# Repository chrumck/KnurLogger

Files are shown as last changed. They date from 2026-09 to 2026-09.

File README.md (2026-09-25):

# KnurLogger

Headless Raspberry Pi logger for the ND Miata instrumentation. It publishes sensor channels to
RaceChrono over BLE and retains raw readings and diagnostics in append-only local session files.

## Start here

| Task | Read |
|---|---|
| Work on the code | [Working instructions](CLAUDE.md), then [software contract](software-contract.md) |
| Build, deploy, enroll probes or retrieve logs | [Operations](operations.md) |
| Configure the phone or decode a packet | [Channel reference](racechrono-channels.md) |
| Diagnose BLE or inspect a recording | [BLE protocol](ble-protocol.md) |
| Diagnose I2C or change sensor acquisition | [Hardware interfaces](hardware-interface.md) |
| Change thermal sampling | [1-Wire probes](one-wire-probes.md) |
| Interpret counters and clocks | [Session records](session-records.md) |
| Change the pressure correction or enter line lengths | [Correction plan](pressure-correction.md), then [operations](operations.md#pressure-correction-settings) |
| Wire the board | [Perfboard build sheet](SystemSetup/logger-perfboard-wiring.md) |
| Configure the host or inspect setup progress | [Host runbook](SystemSetup/pi-headless-setup.md) |
| Restore the phone profile | [RaceChrono profile](RaceChrono/README.md) |
| Understand a retired feature or resolved fault | [History](CLAUDE.history.md) |

Measurement requirements, qualification and the project backlog belong to
[ndLouvers](../ndLouvers/CFD-Learning-Plan.md). Measured results belong to its
[thermal](../ndLouvers/thermals-testing.md) and [pressure](../ndLouvers/pressure-testing.md)
companions. Logger operation is not pressure-channel qualification.

## Hardware it drives

| Part | Interface | Channels |
|---|---|---|
| 5 × Sensirion SDP810 (4 × ±500 Pa on `P0`/`P1`/`P3`/`P4`, 1 × ±125 Pa on **`P2`**) | I2C `0x25` behind a PCA9548A mux at `0x70` | `P0`–`P5` |
| 4 × DS18B20 | 1-Wire on GPIO4, addressed by 64-bit ROM ID | `temp0`–`temp3` |
| BME280 | I2C `0x77` on the main bus | enclosure pressure, cavity temperature, humidity |

**Channel names are positional and carry no meaning.** `P0`–`P5` are fixed by mux position;
`temp0`–`temp3` are fixed by ROM ID at enrollment. The mapping from these to measurement roles
(`T_ambient`, `T_core_in`, `U`, `X`, `C` …) must be recorded with the session metadata. Do not
rename a channel after a role. The thermal role map and its confirmation are in
[ndLouvers thermals §1.1](../ndLouvers/thermals-testing.md#11-channels-roles-and-bindings); the
ROM IDs are in the build sheet's §5a. Pressure role allocation belongs to
[ndLouvers instrumentation](../ndLouvers/instrumentation-spec.md).

All five SDP810s answer at the same fixed I2C address and cannot be strapped apart, which is why
the mux is mandatory rather than a convenience.

## Layout

Single translation unit: every `.cxx` is `#include`-d into `main.cxx`, in the order below, and only
`main.cxx` is named in `CMakeLists.txt`.

```
main.cxx              argument parsing, worker startup, thread joins
dataContracts.hpp     includes, constants, the config and state structs
appData.cxx           the two globals
helpers.cxx           TAI and boot clocks, sysfs and subprocess readers
config.cxx            the .ini, resolved from /proc/self/exe
sessionWriter.cxx     append-only NDJSON, record queue, ~1 s fsync cadence
blePackets.cxx        RaceChrono packet wire format — before every producer
supplyMonitor.cxx     vcgencmd + rpi_volt hwmon at 1 Hz, sticky-bit transitions
oneWireProbes.cxx     DS18B20 enrollment, the bindings in the .ini, 0x602 and 0x603
i2cBus.cxx            I2C_RDWR transport with the mandatory retry — the mux shares it
bme280Sensor.cxx      BME280 forced-mode reads, compensation, 0x600 and 0x601
pressureSensors.cxx   PCA9548A channel select, five SDP810s, 0x605, 0x606 and 0x607
raceChronoBle.cxx     bluez_inc: adapter, advertisement, GATT, notify timers
bluez_inc/            submodule, github.com/weliem/bluez_inc

build/KnurLogger.ini  config TEMPLATE; the deployed copy is ~/bin/KnurLogger.ini on the box

*.md                  subsystem, operations and plan documents — routed by "Start here" above

Tools/                offline diagnostics; nothing here runs on the box
  rcz-channels.py       decode a RaceChrono .rcz's channel slots and flag a mistyped
                        equation — the phone's channel list, audited without the phone
  bell-marks.py         evaluate calibration-bell marks against one pressure channel of a
                        session, on the as-built bell constants and the barometric factor
  ladder-fit.py         re-derive every ladder mark in force and fit each sensor's span
                        term: constant, sign split, slope, per-rung offsets, validation
  pressure-correction-check.py  recompute a session's pressure correction from its own
                        baseline and raw readings, and check the stale-hold events

3DPrinting/           every printed part for both boxes — enclosure, sensor holders, boom
                      tip, the calibration bell (calibrationBell.md owns its constants) and
                      the hood tap's surface static button (surfaceStaticButton.md)

bellTesting.xlsx      the bell-session spreadsheet

RaceChrono/           the phone's configuration, which lives nowhere else
  vehicleProfile.json   RaceChrono's exported vehicle profile, localUuid stripped;
                        both boxes' channels, since the two share one channel set
  README.md             why it is here, how to re-import it, and its traps

SystemSetup/          host configuration; nothing here is logger code
  pi-headless-setup.md    the runbook — start here
  logger-perfboard-wiring.md  the perfboard build sheet — §3a's net list is the authority
                          on every connection. Measurement requirements it serves are in
                          ndLouvers/instrumentation-spec.md.
  audit-boot.sh           read-only survey of what the box runs at boot
  install-dependencies.sh packages the build needs
  harden-headless.sh      boot-time service reduction and bus configuration
  ssh-harden.sh           key-only SSH
  deploy-logger.sh        installs the production binary into ~/bin, never its .ini
  grant-w1-bulk-read.sh   udev rule for therm_bulk_read — one of the two conditions for 1 Hz
  60-knurlogger-w1-bulk-read.rules  what that script installs
  KnurLogger.service      systemd unit — INSTALLED and enabled, survives a reboot
```

## Relationship to the other two loggers

| | KnurDash | iSitePiLogger | KnurLogger |
|---|---|---|---|
| Display | 4.3" DSI touchscreen, GTK under `startx` | none | none |
| Primary record | RaceChrono on the phone | files uploaded over HTTP | **RaceChrono over BLE**; SD card is the durable raw/diagnostic record |
| Radios | BLE | both disabled | **BLE required**, Wi-Fi up (blocked by hand only to diagnose BLE) |
| Language | C | C++, single translation unit | C++, single translation unit |

**KnurDash** contributes the RaceChrono BLE protocol implementation and its `bluez_inc` usage.
It is not the structural model: it is a GUI dash that boots into `startx`, and this box has no
display.

**iSitePiLogger** is the structural model — `SystemSetup/` layout, pre-flight-by-default scripts,
single-translation-unit CMake build, procedural GLib workers, an `.ini` beside the binary,
`CLOCK_TAI` throughout. Two things in it must **not** be copied, and both are load-bearing:

1. Its `setupNotes.txt` disables Bluetooth. BLE is this box's product.
2. Its `setupNotes.txt` disables Wi-Fi. This box lives in a wheel-well cavity with no Ethernet,
   so Wi-Fi is the only way back in; it stays up and is blocked by hand only to diagnose BLE.

## Next

Use [ndLouvers Work Progress](../ndLouvers/work-progress.md) for project work,
[pressure-correction.md](pressure-correction.md) for the logger correction's remaining steps, and
the [host runbook](SystemSetup/pi-headless-setup.md#work-progress) for host-specific open items.
The [acquisition plan](pressure-worker-plan.md) retains its pending recording audit and links
to the completed implementation record.

## Licence

MIT — see [LICENSE](LICENSE), which also states what it does not cover and the absence of any
warranty of fitness for vehicle use. **`bluez_inc` is a submodule, not a copy**, so its own MIT
licence travels with it rather than being restated here. The sibling
[ndLouvers](https://github.com/chrumck/ndLouvers) repository carries the same licence.

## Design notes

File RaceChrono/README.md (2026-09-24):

# RaceChrono vehicle profile — the channel list, backed up

**`vehicleProfile.json` is RaceChrono's exported vehicle profile, with `localUuid` removed.**
It is the only copy of the phone's channel definitions outside the phone, and it covers **both
boxes**: the two devices share one RaceChrono channel set, which is why a channel added for one of
them can break the other.

**Why this is here at all.** Channel definitions are hand-typed into the app. The byte-level
specification is in `../racechrono-channels.md`; this file is the actual configuration, equations and predefined
channel slots included. Re-picking slots by hand is what produced the `bytesToUint`-where-
`bytesToInt`-belongs fault on `Temperature Front 2` (`../../ndLouvers/` open item 45), so a backup that
can be re-imported is worth more than a table that has to be re-typed.

**This directory holds the PROFILE, not recordings.** Session `.rcz` exports live outside both
repositories, in `C:\_claude\RaceChrono\` — `../../ndLouvers/thermals-testing.md` §2.5 item 4 owns
that and says how they differ from the SD session files. Sessions are cited by `.rcz` filename in
`../CLAUDE.history.md`; do not look for them here.

**Exported 2026-09-19**, from the profile named `AE30`. It is a snapshot, not a live mirror —
**the app is the authority**, and this file is stale from the moment a channel is edited.
Re-export after any change.

**This export is the one that carries `0x605`–`0x607`.** The pressure channels and their status
fields were entered on 2026-09-19 and verified the same day — the sentinel check with the sensors
disconnected, every channel negative, and `0x606`'s free-running counter stepping +1 — so all eight
of box 2's packets are now subscribed. It also carries the `0x420` byte 7 channel that
`../../ndLouvers/` open item 47 had been waiting for.

> **⚠ A `git diff` OF THIS FILE IS NOT A REVIEW OF IT.** RaceChrono emits `customChannels` in an
> order that shifts as entries are added, so a re-export rewrites lines that did not change — this
> one showed 184 insertions and 86 deletions for 14 added channels. **Diff it by `(pid, channelId)`
> instead**, decoding each id as `slot × 2²⁰ + channelType`, or an equation edited by hand will pass
> review unseen. That is the fault class this whole directory exists to catch.

## Restoring it

RaceChrono imports a `.rcz`, which is a zip with the profile at the archive root:

```bash
cd RaceChrono && zip ../vehicle.rcz vehicleProfile.json
```

**`localUuid` was removed before committing** — it is a 64-hex-character identifier tied to the
owner's install, not a channel definition, and this repository is public. Re-import has **not been
tested without it**; if the app refuses the file, paste the value back from the original export or
from an export taken after this one.

## What is in it

49 custom channels across thirteen packet IDs. **Box 2's are `0x600`–`0x607`, 36 channels**
(`../racechrono-channels.md` §"The slot map" is the human-readable version). **Box 1's are `0x78`, `0x202`,
`0x420`, `0x4FA` and `0x7F0`, 13 channels.**

**The IDs claimed across both boxes are therefore `0x78`, `0x202`, `0x420`, `0x4FA`, `0x600`–`0x607`
and `0x7F0`.** Check a proposed new packet ID against that list here, in this file, rather than
against either box's source: the two devices share one channel set, so an ID free on one of them is
not necessarily free.

Two of those 49 are not in the slot map and are worth naming, because each is a decision rather
than an omission:

1. **`P5` has no channel** — `0x606` bytes 2–3. Mux channel 5 is unpopulated, so the field is a
   permanent sentinel inside a packet that is subscribed anyway. `../racechrono-channels.md` slot-map note 5
   owns it, including what to do if channel 5 is ever populated.
2. **`0x420` byte 7 is now defined**, as `H-40` on predefined channel 10031, alongside byte 0's
   existing `A-40` on 10026. That is the outside-air temperature of `../../ndLouvers/` open item 47.
   Defining it fixes nothing retrospectively — no past recording can be reprocessed — so it counts
   only from the first session recorded after this export.

**Two things worth knowing before editing an equation by hand.**

1. **RaceChrono's equation parser is case-insensitive**, and this file proves it: `bytesToUint`,
   `bytesTouInt`, `bytestouint` and `bytesToUInt` all appear and all work. **Do not "normalise" the
   casing** — there is nothing to fix, and an edit is a chance to introduce the fault below.
2. **`bytestoint` and `bytestouint` differ by one letter, and that letter is the signed/unsigned
   decision.** In lowercase, scanning for it by eye is unreliable. `../Tools/rcz-channels.py`
   checks it from a recording instead — on `Temperature` slots at +327.68 and, since 2026-09-19,
   on `Pressure` slots at +3.2768. **The pressure channels need that check more than the thermal
   ones did**: a negative differential is normal on half of them, depending only on which port the
   tube lands in, so a wrong sign there corrupts ordinary data rather than only the marker.
   `Pressure Front 50` is exempt and must stay `bytesToUint` — `0x600`'s enclosure pressure is
   unsigned by design.

**`A`–`H` (or `a`–`h`) in an equation are payload bytes 0–7.**

**An all-empty channel is not necessarily a broken one.** RaceChrono renders a deliberate
out-of-range marker as no value at all. Box 1's `0x7F0` channels `lowPass(E,254)*4` and
`lowPass(F,254)-50` are `NaN` whenever their sensors are outside their calibration range, and
**that is by design** (owner, 2026-09-11): the marker is how that is signalled. They are working —
on the 2026-09-13 track day both read normally once the car was warm and were empty only for the
first 200–550 s of each session, so "empty" is a property of the session, not of the channel. `../Tools/rcz-channels.py` reports such channels without
calling them faults — **ask what the sensor was doing before changing an equation.**

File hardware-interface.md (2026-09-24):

# Sensor interfaces and bus diagnostics

[SystemSetup/logger-perfboard-wiring.md](SystemSetup/logger-perfboard-wiring.md) owns the net
list, addresses, serial-to-channel allocation and assembly. Consult its §2 and §5 before
working on a physical channel. This file owns software-facing bus rules and diagnostic technique.

## Addressing and identity

1. The five SDP810s are hard-soldered; moving or isolating a sensor requires desoldering.
   Identify each by returned product number and serial, not its board position. Retain its
   returned scale factor; do not hard-code 60 counts/Pa for both products.
2. The sensors share fixed address `0x25`, so select one mux channel at a time. Use only the
   configured populated-channel list. Never probe channel 5: its pull-ups are not fitted.
3. The PCA9548A is strapped to `0x70`; the BME280 at `0x77` occupies the address a differently
   strapped mux could collide with. The BME280 chip ID is `0x60` at register `0xD0`.
4. Each populated downstream channel requires its own pull-ups. The build sheet owns values.
5. Read the mux control register back after writing it and verify the selected channel.
   A seemingly successful write to a faulty segment can otherwise hang the main bus.

## Idle-bus refusal

1. On some boots the first `I2C_RDWR` after an idle interval is refused with `EREMOTEIO`.
   The behavior is bimodal per boot. A clean boot does not close the physical-cause question
   in [ndLouvers open item 44](../ndLouvers/work-progress.md).
2. `i2cBus.cxx` owns the counted retry: up to ten attempts, separated by 500 µs.
   Do not add another retry layer in a sensor worker or hide recovered/exhausted transfers.
3. A clean `i2cdetect` is not proof that spaced transfers work. Check several spaced reads with
   `i2ctransfer -y 1 w1@0x77 0xd0 r1`; a single success or failure cannot establish the mode.
4. Check `present` before interpreting exhausted transfers. Errors while a device is absent
   are not evidence of a deteriorating connected bus. Counters are cumulative and shared;
   [session-records.md](session-records.md) explains the calculation.
5. The configured 10 Hz pressure loop still leaves the bus idle between cycles. Do not raise
   the sample rate to conceal the refusal; its physical cause and sampling choice are separate.

## A downstream segment hangs the main bus

1. First inspect the Pi side with `pinctrl get <n>` when a device is silent. Check wiring before
   trying to repair a physical reset fault in software.
2. A clean scan, both lines idle-high and failed transfers can indicate SDA shorted to SCL on
   the selected downstream segment. Check `SDA_CH<n>` to `SCL_CH<n>` continuity.
3. Recover using GPIO17: `pinctrl set 17 op dl`, pause, then `pinctrl set 17 op dh`.
   Reset between populated channels during diagnosis so one failed segment cannot mask the rest.

## SDP810 continuous mode and sampling

1. Use stop-continuous `0x3FF9`, identity `0x367C`/`0xE102`, then start `0x3615` once per
   sensor. Each measurement is a nine-byte frame with a CRC on each word.
2. Starting continuous mode again while already running is NAK'd. Mux switching does not stop
   that mode. Track `isContinuousStarted` per sensor; a failed read clears it so the next visit
   re-arms and pays `SDP810_START_SETTLE_US`. Do not re-arm unconditionally every cycle.
3. Keep `0x3615` differential-pressure temperature compensation. Do not switch to the mass-flow
   compensation variants as a substitute for the barometric correction specified in
   [pressure-testing.md §2.3a–§2.4](../ndLouvers/pressure-testing.md).
4. At this logger's read interval, `average till read` is exponential smoothing, not a full-cycle
   mean. Its roughly 10 ms time constant does not cover the configured 100 ms interval.
   Changing sampling or averaging requires the measurement decision in
   [open item 54](../ndLouvers/work-progress.md); the hardware retry is a separate question.
5. [pressure-correction.md](pressure-correction.md) owns the pressure correction's decisions and
   its progress. Read it before changing conversion or configuration.

## BME280 quantities

1. `enclosurePressurePa` is enclosure pressure. It is unsuitable as an aerodynamic static
   reference, but supplies the pressure correction's absolute-pressure input. Log it for every
   bench and road session. Physical interpretations belong to
   [thermals-testing.md §1.4](../ndLouvers/thermals-testing.md).
2. `cavityTemperatureC` is the cavity thermometer. It is not the inlet-air temperature for
   density; use the measurement plan's ambient channel for that purpose.
3. `enclosureHumidityPct` supports dewpoint-margin interpretation. The measurement acceptance
   of a sealed enclosure belongs to the instrumentation specification.
4. Forced mode, ×1 oversampling and IIR off minimize self-heating of the cavity thermometer.
   A skipped temperature invalidates pressure and humidity through shared `t_fine`; successful
   transport does not make the resulting measurement valid.

## Other interfaces

1. [one-wire-probes.md](one-wire-probes.md) owns DS18B20 binding, powered-bus operation,
   `28-*` filtering, bulk-read permissions and trigger length, stale-probe behavior, offsets
   and the accepted 85 °C blind spot. Read it before changing that worker.
2. [racechrono-channels.md](racechrono-channels.md) owns packet meanings. The ESP32 test's
   synthetic `0x600`/`0x601` definitions do not describe the Pi's BME280 packets.
3. The four thermal probes are installed on the car. A phone hotspot can provide a local SSH
   path without internet if its NetworkManager profile is configured beforehand. Keep PSKs out
   of git. Enrollment and logging must also survive unattended power-on; BLE is the feedback
   path that shows what RaceChrono actually receives.
4. Wi-Fi gating is manual when diagnosing a BLE problem. Keep Bluetooth enabled and never use
   `rfkill block all`; see [operations.md](operations.md).

The diagnoses behind these rules are in [CLAUDE.history.md](CLAUDE.history.md).

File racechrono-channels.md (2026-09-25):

# RaceChrono channel and packet reference

This file owns packet layouts, equations and the phone slot map.
[ble-protocol.md](ble-protocol.md) owns subscription behavior and export auditing;
[RaceChrono profile restoration](RaceChrono/README.md) owns importing the saved profile.

## RaceChrono channels — what to type into the phone

RaceChrono channel definitions are entered by hand, so they live here. Add the device from inside
RaceChrono (**Settings → other devices → add a DIY device**), **not** from the phone's Bluetooth
pairing screen: this is a BLE GATT peripheral with no bonding, advertising `BR/EDR Not Supported`,
so the OS pairing list will never show it.

**Every payload field is big-endian. Only the 4-byte packet ID is little-endian**, per the DIY API.

> **A packet with no channel definition is never sent.** The logger honours RaceChrono's
> subscription, so entering the logging regime means only the packet IDs you have defined channels
> for get notified. Measured 2026-09-10 on the bench and again in the car on 2026-09-11, when
> `0x604` took **zero** notifications because no channel was defined for it while the other four
> ran at ~1 Hz. The first five packets were defined on 2026-09-11 and **`0x605`–`0x607` on
> 2026-09-19**, so all eight are now subscribed.
> In CAN-bus test mode RaceChrono asks for everything instead, which is why test mode shows
> channels that logging mode does not.
>
> **Define at least one free-running counter, whichever it is.** `0x604` byte 7 is the heartbeat,
> but `0x601` and `0x603` bytes 4–5 are per-cycle counters with the same property, and the second
> road test's zero-drop measurement was made off those two with `0x604` absent.

### The slot map — what to re-enter after a phone wipe

**RaceChrono channels are hand-typed into the phone and exist nowhere else.** The tables below say
which bytes carry what; this one says which predefined channel slot each field was put in, because
a slot is what a gauge, a lap chart or an exported CSV is named after. **Losing it means re-picking
36 slots, and re-picking slots is how one of them ended up decoding signed data as unsigned.**

Slots as of **2026-09-19**, and **verified against RaceChrono's own exported profile**, which is
committed at `RaceChrono/vehicleProfile.json` — that file is the authority on what is entered, this
table is the readable view of it. Packet IDs are decimal, which is what the CAN-ID field takes.

| Packet | Bytes | RaceChrono slot | Carries |
|---|---|---|---|
| 1536 `0x600` | 0–3 | `Pressure Front 50` | enclosure pressure — `/1000` for kPa, displayed in bar |
| 1536 | 4–5 | `Temperature Front 50` | cavity temperature |
| 1536 | 6–7 | `Percent Front 50` | enclosure humidity |
| 1537 `0x601` | 0 | `Digital Front 51` | BME280 status bits, expect 31 |
| 1537 | 1 | `Digital Front 52` | chip ID, expect 96 |
| 1537 | 2–3 | `Digital Front 53` | read errors |
| 1537 | 4–5 | `Digital Front 54` | sample cycles — free-running |
| 1537 | 6–7 | `Digital Front 55` | last read, ms |
| 1538 `0x602` | 0–1 | `Temperature Front 1` | `temp0` |
| 1538 | 2–3 | `Temperature Front 2` | `temp1` |
| 1538 | 4–5 | `Temperature Front 3` | `temp2` |
| 1538 | 6–7 | `Temperature Front 4` | `temp3` |
| 1539 `0x603` | 0 | `Digital Front 1` | probes enumerated |
| 1539 | 1 | `Digital Front 2` | valid-this-cycle mask |
| 1539 | 2–3 | `Digital Front 3` | read errors |
| 1539 | 4–5 | `Digital Front 4` | sample cycles — free-running |
| 1539 | 6–7 | `Digital Front 5` | last conversion, ms |
| 1540 `0x604` | 0 | `Digital Front 11` | logger status bits |
| 1540 | 1 | `Digital Front 12` | sticky throttle bits |
| 1540 | 2 | `Digital Front 13` | undervoltage comparator |
| 1540 | 3–4 | `Digital Front 14` | SoC core mV |
| 1540 | 5–6 | **`Temperature Front 15`** | SoC temperature |
| 1540 | 7 | `Digital Front 16` | **heartbeat** |
| 1541 `0x605` | 0–1 | `Pressure Front 1` | `P0` |
| 1541 | 2–3 | `Pressure Front 2` | `P1` |
| 1541 | 4–5 | `Pressure Front 3` | `P2` |
| 1541 | 6–7 | `Pressure Front 4` | `P3` |
| 1542 `0x606` | 0–1 | `Pressure Front 5` | `P4` |
| 1542 | 2–3 | **not defined** — see note 5 | `P5` |
| 1542 | 4–5 | `Digital Front 21` | sample cycles — free-running |
| 1542 | 6–7 | `Digital Front 22` | last cycle, ms |
| 1543 `0x607` | 0 | `Digital Front 23` | channels enabled, bitmask |
| 1543 | 1 | `Digital Front 24` | sent-this-cycle mask |
| 1543 | 2–3 | `Digital Front 25` | read errors |
| 1543 | 4–5 | `Digital Front 26` | CRC failures |
| 1543 | 6 | **`Temperature Front 20`** | sensor temperature, lowest enabled channel |
| 1543 | 7 | `Digital Front 27` | mux channel selected |

Five things this table is carrying rather than repeating:

1. **`Temperature Front 15` is a Temperature slot on purpose.** It was a Digital one until
   2026-09-11. It is the only `0x604` field with decimals; the rest are integers, and **SoC core
   millivolts stays Digital because RaceChrono has no voltage slot** — no precision is lost, the
   gauge simply carries no unit.
2. **Changing a slot's type changes its identity.** `Digital Front 15` and `Temperature Front 15`
   are different channels with different ids, so a retyped field leaves the old slot behind unless
   it is deleted — still subscribed, still decoding the same bytes under the old name.
3. **The pressure channels are `Pressure Front 1`–`5` and their status fields are `Digital
   Front 21`–`27` plus `Temperature Front 20`** — chosen to sit clear of every slot above, so no
   existing channel is disturbed and a `.rcz` from before 2026-09-19 can be told apart from one
   after it by their presence alone.
   **`0x607` byte 6 is `Temperature Front 20`, not the 21 this table specified until 2026-09-19.**
   The slot entered on the phone won, as the profile always does; 20 was free, satisfies the same
   clear-of-everything property, and `Temperature Front 21` and `Digital Front 21` would have been
   distinct channels anyway, so nothing was at stake either way. **Do not re-pick it to match an
   older table** — deleting and re-entering a channel by hand is the operation that produced the
   `bytesToUint` fault on `Temperature Front 2`, and it would buy nothing.
4. **`0x601` was renumbered from 50–53 to 51–55 on 2026-09-11**, when byte 6–7 was added. **Any
   recording made before that carries the old slot numbers**, so a session and this table can
   disagree without either being wrong. `Tools/rcz-channels.py` prints what a given recording
   actually used — **and a session that was paused and resumed carries one fragment per stretch**,
   which the tool reports separately. Reading only the archive root silently discards every later
   stretch; that is half of the 2026-09-13 track day.
5. **`P5` has no channel on the phone, and that is a decision** (owner, 2026-09-19). Mux channel 5
   is unpopulated — its pull-ups are footprints only and addressing it hangs the bus — so the
   worker never enables it and `0x606` bytes 2–3 carry the `−32768` sentinel permanently. An
   undefined field inside a *subscribed* packet costs nothing: `0x606` is sent for its other three
   channels and the phone simply discards these two bytes. **This is not the open item 47 mistake
   and must not be filed as one** — that was an undefined byte on a frame nobody could see was
   missing, carrying data that existed. Here the packet is visible, the field is a constant, and
   the logger's own `0x607` byte 0 states that channel 5 is disabled. **If mux channel 5 is ever
   populated, define `Pressure Front 6` as `bytesToInt(raw,2,2)/10000` before the first session
   that uses it** — the data is unrecoverable afterwards.

**`0x602` and `0x603` are transcribed byte for byte from the ESP32 rig in
`../ndLouvers/step0b-rig/racechrono_ble_test/`, so definitions written against that rig carry over
unchanged. `0x600` and `0x601` do NOT** — they were the rig's synthetic test frames and were
released for real use (owner decision, 2026-09-10), so a rig-era `0x600` definition decodes
garbage here and must be re-entered.

### `0x600` — enclosure conditions

**These two IDs used to be the ESP32 rig's synthetic test frames and no longer are** (owner
decision, 2026-09-10). That rig is spent, so the IDs were released for real use. **A channel
definition written against the rig's `0x600` decodes garbage here and must be re-entered.**
`0x602`–`0x604` are unchanged and still carry over.

| Bytes | Channel | Equation as deployed | Invalid |
|---|---|---|---|
| 0–3 | enclosure pressure, **kPa on the wire, displayed in bar** | `bytesToUint(raw, 0, 4) / 1000` | `4294967295` → `4294967.295`, i.e. ~42 950 bar |
| 4–5 | cavity temperature | `bytesToInt(raw, 4, 2) / 100` | `-32768` → −327.68 °C |
| 6–7 | enclosure humidity, % | `bytesToUint(raw, 6, 2) / 100` | `65535` → 655.35 % |

**The logger sends pressure in whole pascals and the `/1000` is the phone's, because RaceChrono's
Pressure channel takes kPa and this gauge is set to display bar** (owner, 2026-09-11). So 101 319 Pa
goes out, RaceChrono stores 101.319 and renders **~1.013 bar**. This table documented the undivided
form until the saved vehicle profile showed what was actually entered. The divide is fine and the
invalid marker survives it — ~42 950 bar is no more plausible than 4294967295 Pa — but **the packet
and the channel must be read together**, which is the reason the profile is now backed up in
`RaceChrono/`.

**Temperature is signed — use `bytesToInt`.** Pressure and humidity are unsigned and use
`bytesToUint`; pressure needs the full four bytes because absolute pressure does not fit in two
at 1 Pa resolution. Each invalid marker is absurd after the divide for the same reason `0x602`'s
is: RaceChrono holds the last value it received indefinitely.

**Name these three channels for their roles, not for the part**, because two of the three are
easy to point at the wrong thing:

1. **Pressure is ENCLOSURE pressure and never a static reference.** The cavity is
   aerodynamically live: **measured at 156 Pa below stationary at a mean 116 km/h on the first
   drive (Cp ≈ −0.25)**, which is still 2–3× the 45–90 Pa measurands, is not a single constant Cp,
   and is speed-correlated so it does not average out of a speed sweep. **That is not the only cavity
   record, and the records disagree**: a second cavity record from the third drive
   corroborates the sign and order without being a Cp point, because the route's elevation change
   is the same order as the signal and no altitude channel was exported. **Two track days then add
   SEVEN sessions and they CONTRADICT the first drive** — Cp −0.108 to −0.144, flat to within ±0.006
   from 40 to 200 km/h, on circuits with 8–14 m of altitude span and the altitude channel present;
   `../ndLouvers/` open item 49 owns the disagreement, where the plan's rev 92 review arithmetic
   (12 Pa per metre of GPS altitude error against a 94 Pa signal at 45 km/h) recommends the track
   result, and it is not yet decided. The second drive's box
   was on the passenger seat, so its
   speed-correlated pressure record is a cabin record and was withdrawn.
   **This field is named for where the box is designed to sit, not for where it actually sat**, and
   nothing in the session file says which. Record the mounting state per session. It is tolerable as a
   density term and disqualifying as a reference (`../ndLouvers/thermals-testing.md` §3.6).
2. **Temperature is the cavity thermometer** (plan item 1d, the hot-day envelope), with Pi SoC temperature on `0x604`
   as a cross-check rather than the primary proxy. **It is not the inlet density term** — that is
   `T_ambient`'s DS18B20 on `0x602` byte 0–1.
3. **Humidity is the enclosure's condensation diagnostic** — the enclosure is sealed with no
   desiccant (plan item 1c, closed). Its measurement consumer is the dewpoint margin
   (`../ndLouvers/thermals-testing.md` §3.10).

### `0x601` — BME280 health

| Bytes | Content | Equation | Expected |
|---|---|---|---|
| 0 | bit 0 present, bit 1 calibration read, bit 2 pressure valid, bit 3 temperature valid, bit 4 humidity valid | `bytesToUint(raw, 0, 1)` | **31**; **3** on a skipped measurement |
| 1 | chip ID as read | `bytesToUint(raw, 1, 1)` | **96** (`0x60`); `88` would be a BMP280 |
| 2–3 | cumulative read errors, saturating | `bytesToUint(raw, 2, 2)` | **0** |
| 4–5 | sample cycles | `bytesToUint(raw, 4, 2)` | +1 per second, wraps every **18.2 h** |
| 6–7 | last read, ms | `bytesToUint(raw, 6, 2)` | **~15** |

**This is `0x603`'s argument applied to the BME280, and it matters more here.** A sealed cavity's
temperature and pressure legitimately sit still for minutes, so a frozen `0x600` is not by itself
evidence of anything. Byte 4–5 advances every cycle regardless of what the part reports, which is
what separates a dead worker from a still cavity.

> **⚠ BYTE 0 IS WHAT CATCHES A SKIPPED MEASUREMENT, AND BYTES 2–3 DELIBERATELY DO NOT.** Measured
> once in the field, 2026-09-14: one cycle sent all three `0x600` values as their invalid sentinels
> together — which is the `t_fine` rule, a skipped temperature invalidating pressure and humidity —
> and **byte 0 dropped 31 → 3**, keeping only *present* and *calibration read*. **The read-error
> counter correctly stayed at 0**: the transfer succeeded and `lastReadMs` was normal, so nothing
> failed to read. **A cumulative read-error count of 0 is therefore not evidence that every sample
> was valid.** First time byte 0 has read anything but 31 in the field.

### `0x602` — the four thermal channels

| Bytes | Channel | Equation |
|---|---|---|
| 0–1 | `temp0` | `bytesToInt(raw, 0, 2) / 100` |
| 2–3 | `temp1` | `bytesToInt(raw, 2, 2) / 100` |
| 4–5 | `temp2` | `bytesToInt(raw, 4, 2) / 100` |
| 6–7 | `temp3` | `bytesToInt(raw, 6, 2) / 100` |

**Signed — use `bytesToInt`, not `bytesToUint`.** Sub-zero ambient is a real reading and would
otherwise decode as ~655 °C. A channel with no trustworthy reading sends `-32768`, i.e. **−327.68 °C**,
deliberately absurd rather than plausible because RaceChrono holds the last value it received
indefinitely and an invalid marker has to be visible.

> **⚠ `Temperature Front 2` was defined `bytesToUint`; it is fixed and VERIFIED** (owner,
> 2026-09-11 — with the sensor disconnected the channel reads negative, so the signed decode is in
> force). Keep the whole entry: the fault class is permanent even though this instance is closed.
> Found 2026-09-11: three of the four sentinels decoded as −327.68 and that one as **+327.68**. It
> is `0x602` bytes 2–3, i.e. **`temp1`, the `T_core_in` slot — the probe ΔT_preheat is measured
> from**. **The fault is invisible in normal data**, because a positive temperature decodes
> identically either way, and **nothing on the logger can detect it**. The only ways it shows are
> the sentinel and a sub-zero ambient, so the check below is the check — and it only works with no
> probes attached, which is the condition to confirm the fix in.

**These values carry the per-channel calibration offset** from `KnurLogger.ini`, if one is set — see
§[Calibration offsets](operations.md#calibration-offsets). The session file records the raw reading beside the
value sent, so the two can always be reconciled.

**With no probe on the bus all four send the sentinel, and the packet keeps being republished once
per sample cycle.** Unbound, bound-but-absent and read-badly all send the same sentinel, which is
right — none of them is a temperature — and the session file is where the three are told apart. To
see *which* it is from the phone alone, watch `0x603`: byte 0 is how many probes are on the bus and
byte 1 is which channels read cleanly.

### `0x603` — 1-Wire bus health

| Bytes | Content | Equation | Expected with four probes |
|---|---|---|---|
| 0 | probes enumerated | `bytesToUint(raw, 0, 1)` | **4** |
| 1 | valid-this-cycle bitmask, bit *n* = `temp<n>` | `bytesToUint(raw, 1, 1)` | **15** |
| 2–3 | cumulative read errors, saturating | `bytesToUint(raw, 2, 2)` | **0**, and staying there |
| 4–5 | sample cycles | `bytesToUint(raw, 4, 2)` | +1 per second, wraps at 65535 — i.e. every **18.2 h** |
| 6–7 | last conversion, ms | `bytesToUint(raw, 6, 2)` | **~780 with four probes** — one bulk conversion covering all four. It read ~3200 before 2026-09-11, when each probe paid its own |

Transcribed byte for byte from the ESP32 rig's `0x603`, so channel definitions written against that
rig carry over. **This is what makes the thermal channels checkable rather than merely present:**
four plausible numbers on `0x602` say nothing about whether they are being read, and bytes 0–3 are
where a probe that dropped off the bus or a bus that is retrying shows up. Byte 4–5 is the thermal
equivalent of `0x604`'s heartbeat — it advances every cycle regardless of what the probes read, so
it separates a dead worker from four steady temperatures.

> **⚠ BYTE 2–3 COUNTS *UNTRUSTED SAMPLES*, NOT BUS FAULTS.** A CRC failure, unparseable content,
> a failed read and an out-of-range value all increment it, and only the session record's `reason`
> separates them, so **a rising counter is a reason to read the session file, not a diagnosis.**
> **In sessions recorded before 2026-09-23 it also counted every 85.000 °C reading** as
> `powerOnDefault` — every one of the 17 it counted across the two track days was `temp3` at exactly
> 85.000 °C with a **good CRC**, while the loaded star recorded **zero** CRC failures in 133 894
> cycles. The logger now accepts 85.00 °C as a reading (`one-wire-probes.md`).

**Byte 2–3 counts only probes that answered and read badly.** A bound channel whose probe is *absent*
does not increment it, because a dropped lead and a marginal bus send you to different parts of the
car; absence shows up as byte 0 falling and byte 1 losing a bit.

**A probe that has just been unplugged is `absent` for this purpose too, for ~100 s before it looks
it.** The kernel keeps an unregistered slave's sysfs entry for `w1_slave_ttl` (10) missed searches
at `w1_master_timeout` (10 s), and reads of it succeed and return nothing — so byte 0 stays up,
byte 1 loses its bit, and byte 2–3 stays put. That last part was a bug until 2026-09-10, when
unplugging probes during enrollment charged 186 read errors to a bus that had not failed once
(`CLAUDE.history.md` §1.12). The session file counts these separately as `notAnswering`, so a bus
that really is dropping out is still visible; it is just not confused with one that read badly.

**Byte 6–7 reads ~780 with four probes bound**, because one bulk conversion now covers all four;
it read ~3200 while the reads were sequential. **It read 0 for one session**, which is how the
first fault was found: the field reported the bulk wait whenever the *write* succeeded, so a 0 ms
wait masked ~800 ms of real conversion. It now reports what the cycle actually paid — timed from
**before** the write, because the kernel sleeps the whole conversion inside it — and the `temp`
records carry `bulkState` (the raw `therm_bulk_read` readback, `"1"` when healthy) beside it.
**A ~0 ms reading with cycles still near 1 s means the bulk path ran and its bus reset failed:**
the kernel marks every slave ready regardless, so check byte 2–3 before trusting the temperatures.

**Confirmed on the phone 2026-09-11.** All five channels are defined and decoded correctly against
the logger's own record of the same samples, with no probes attached: probes 0, valid-mask 0, read
errors 0, sample cycles ramping at 1 Hz, conversion 0 ms.

### `0x604` — supply health and logger liveness

| Bytes | Content | Equation |
|---|---|---|
| 0 | low nibble = live throttle bits; bit 4 = records dropped; bit 5 = enrollment mode | `bytesToUint(raw, 0, 1)` |
| 1 | sticky throttle bits, latched since **boot** not since session start — **observed at 5 across both track days**, `undervoltage` + `throttled`, dated from the SD file to the first 13.2 s after boot | `bytesToUint(raw, 1, 1)` |
| 2 | undervoltage comparator; **255 = could not be read**, not "no alarm" | `bytesToUint(raw, 2, 1)` |
| 3–4 | SoC core millivolts — **NOT the supply rail** | `bytesToUint(raw, 3, 2)` |
| 5–6 | SoC temperature | `bytesToInt(raw, 5, 2) / 100` |
| 7 | **heartbeat, +1 per second, wraps at 255** | `bytesToUint(raw, 7, 1)` |

> **⚠ This frame went unsent through two road tests** — no channel was defined for it, so
> RaceChrono's subscription burst never asked for it and the logger recorded `"supply": 0`
> notifications. **Defined 2026-09-11 and CONFIRMED the same evening** on the third drive — all six
> channels decoded, and byte 7's heartbeat stepped exactly +1 across all 410 samples. The slot map
> above has where the six rows went. Re-confirm from either end after any edit to the phone's
> channel list: byte 7 ticking +1 per second on the phone, or `bleNotifiesByPacket` in any
> `supply` record showing `supply` climbing instead of 0.

**Byte 1 is the one to read after a run, and byte 7 during it.** Byte 1 latches since **boot**, so
a session that starts with it non-zero is reporting something that happened before the recording
opened, and **no BLE record can ever date that** — `recordStickyTransitions` timestamps the first
transition of each bit and `stickyAtSessionStart` says whether it was inherited, and both are in
the SD session file only. **That is exactly the case the track days produced, and reading the SD
file is what settled it:** `stickyAtSessionStart` was already 5 at `bootUs` 13.17 s, so the latch
is a power-on transient inside the first 13 seconds (`../ndLouvers/` open item 48, closed). The general
lesson is the one to keep — **a non-zero byte 1 is a question the phone cannot answer.**

**Byte 7 is the channel to watch while the link is live.** Every other field here is a physical
quantity allowed to sit still — SoC core voltage reads a constant 840 mV on an
idle box for hours — so a frozen value proves nothing about the link. A counter freezing means the
link died; a counter skipping means a notification was dropped, which is exactly what commissioning
item 5a asked to be logged. **It is not the only counter with that property**: `0x601` and `0x603`
bytes 4–5 advance every cycle regardless of what their sensors report, and the second road test's
zero-drop measurement was made off those two.

### `0x605` and `0x606` — the six pressure channels

**Nothing on these channels is a pressure measurement yet.** They carry what the five SDP810s
report with every port open to whatever air is around them; the pneumatic rig — wands, tubing,
filters, drainage — is not installed, and `../ndLouvers/pressure-testing.md` §2 is the
qualification none of this discharges. What exists is the channel a measurement will travel down.

**The value on the air is the corrected pressure, not the raw reading** (since 2026-09-24): the
reading divided by the density factor `P_abs / 96 600 Pa` and by `(1 + ε±)`, plus the loss along the
slot's lines. With every line length configured as 0, which it is until the routes are measured,
only the density and span terms act. The equations below are unchanged; `pressure-correction.md`
owns the correction and `session-records.md` the record fields that let a session recompute it.

| Packet | Bytes | Channel | Equation | Invalid |
|---|---|---|---|---|
| 1541 `0x605` | 0–1 | `P0` | `bytesToInt(raw, 0, 2) / 10000` | `-32768` → **−3.2768 kPa** |
| 1541 | 2–3 | `P1` | `bytesToInt(raw, 2, 2) / 10000` | as above |
| 1541 | 4–5 | `P2` | `bytesToInt(raw, 4, 2) / 10000` | as above |
| 1541 | 6–7 | `P3` | `bytesToInt(raw, 6, 2) / 10000` | as above |
| 1542 `0x606` | 0–1 | `P4` | `bytesToInt(raw, 0, 2) / 10000` | as above |
| 1542 | 2–3 | `P5` | **no channel defined** — slot-map note 5 | as above |
| 1542 | 4–5 | sample cycles | `bytesToUint(raw, 4, 2)` | free-running, wraps at 65535 |
| 1542 | 6–7 | last cycle, ms | `bytesToUint(raw, 6, 2)` | **~16** for five sensors |

**The wire carries signed decipascals — 0.1 Pa/LSB — on all six channels** (owner decision,
2026-09-19; [ndLouvers instrumentation-spec.md](../ndLouvers/instrumentation-spec.md) commissioning item 4a). `int16` at 0.01 Pa/LSB overflows
at 327 Pa and cannot carry a ±500 Pa channel, so centipascals would have meant **two decode rules**
on a list nothing in this code can check — which is exactly how `bytesToUint` survived on
`Temperature Front 2`. One rule covers all six instead. The resolution thrown away on the ±125 Pa
part is affordable **because the session file carries raw counts and the returned scale factor at
full resolution**, so any session can be reprocessed; only a `.rcz` cannot, which is the asymmetry
that governs everything on this link.

> **⚠ THE `/10000` IS CORRECT AND THE NUMBER ON THE GAUGE IS THEREFORE SMALL. DO NOT SHORTEN IT.**
> RaceChrono's Pressure channel stores **kPa** — `Pressure Front 50` divides by 1000 for exactly
> that reason — and decipascals reach kPa through ten thousand. Full scale is then 0.5 kPa and the
> 45–90 Pa measurands this project is built around are 0.045–0.090, which a gauge set to bar
> renders as near zero.
>
> **The obvious shortcut does not work, and it was tried** (2026-09-19, withdrawn the same day).
> `/10` looks like it puts pascals on the gauge. It does not: RaceChrono still believes the stored
> number is kPa and applies **its own** unit conversion on top, so 500 Pa stored as "500 kPa"
> displays as **5 bar**. That is wrong twice — wrong unit *and* wrong magnitude — where `/10000` is
> merely small. **A divide that fights the app's unit handling produces a number that means
> nothing.** Keep `/10000`.
>
> **The divide has never been about resolution, and that was measured rather than assumed.**
> RaceChrono stores every sample as a **float64**: `Pressure Front 50`'s samples in the 2026-09-14
> export come back as `101.151`, `101.154`, `101.15000000000001` — an IEEE-754 double carrying full
> precision, 8 bytes per sample. A double would need a divide around 10¹² before it noticed
> anything. **`/10000` costs nothing in the recording**, which is the whole of what the logged and
> exported data depends on.
>
> **What it does cost is the at-the-car eyeball**, and that cost is real: these six channels will
> not be readable on a bar-scaled gauge. Two things soften it. **The sentinel check survives**,
> because it turns on the *sign* — −0.0033 bar against +0.0033 bar — not the magnitude. And if
> RaceChrono's pressure display unit can be set per gauge, setting these six to kPa or Pa makes
> them readable with no change to the equation; the channel definition carries no unit field, so
> the unit is an app setting and not something this document can fix. **The SD session file is the
> authority regardless** — raw counts, the returned scale factor and full-resolution pascals, none
> of which pass through the phone.

**Signed — use `bytesToInt`.** A negative differential is the normal case on half these channels,
depending only on which port the tube lands in, so an unsigned decode corrupts ordinary data rather
than only the sentinel. **`-32768` is the no-trustworthy-reading marker** — also sent for a good
reading that could not be corrected, because the BME280's absolute pressure is missing or more than
10 s old — and decodes to **−3.2768 kPa** — 6.5× the ±500 Pa part's full range and therefore impossible, which is the property an invalid
marker needs, because RaceChrono holds the last value it received indefinitely.

> **⚠ ZERO IS A COMPLETELY PLAUSIBLE DIFFERENTIAL PRESSURE, WHICH MAKES THE SENTINEL MATTER MORE
> HERE THAN ON THE THERMAL CHANNELS.** All six are published as `-32768` before the worker has read
> anything — five of them reaching the phone, `P5` having no channel — so a phone that connects
> first sees unmistakable non-readings rather than believable readings of nothing. A thermal channel
> reading 0 °C at least looks like weather; a pressure channel reading 0 Pa looks like a correct
> answer. **The sentinel check passed on all five with the sensors disconnected** (owner,
> 2026-09-19): every one read negative.

**`0x606` bytes 4–5 advance every cycle whatever the sensors report**, which is what separates a
dead worker from five steady pressures — and five steady zeroes is the resting state of a healthy
rig, so this counter is more necessary here than on `0x601` or `0x603`. At the measured 9.594 Hz it
wraps at 65535 every **1.9 h** rather than the 18.2 h those two take at 1 Hz.

**Channel names are positional and mean nothing.** `P0`–`P5` are fixed by mux position. **The
role→channel mapping belongs to `../ndLouvers/`** (`instrumentation-spec.md` Step 0b, open item 30a) — and these
channels are published independently of any role on purpose, so the phone-side definitions can be
built and verified **before** the rig is, which is the only way to stop open item 47 repeating on the
pressure side. Recording which *part* sits on which channel (the `pressureBaseline` record, and
`SystemSetup/logger-perfboard-wiring.md` §5) is not deciding which *role* it serves.

### `0x607` — pressure channel health

| Bytes | Content | Equation | Expected with five sensors |
|---|---|---|---|
| 0 | channels enabled, bitmask, bit *n* = `P<n>` | `bytesToUint(raw, 0, 1)` | **31** — channels 0–4 |
| 1 | sent-this-cycle bitmask, bit *n* = `P<n>`: read validly **and** corrected | `bytesToUint(raw, 1, 1)` | **31**, and staying there |
| 2–3 | cumulative read errors, saturating | `bytesToUint(raw, 2, 2)` | **0** |
| 4–5 | cumulative CRC failures, saturating | `bytesToUint(raw, 4, 2)` | **0** |
| 6 | sensor temperature of the lowest enabled channel, °C; **−128** when that channel has no valid reading this cycle | `bytesToInt(raw, 6, 1)` | bench ambient |
| 7 | mux control byte: **0** deselected, bit *n* set while `P<n>` is being read, **255** if the end-of-cycle deselect failed | `bytesToUint(raw, 7, 1)` | **0** |

**Byte 1 is how an invalid channel is seen from the phone without decoding the sentinel**, exactly
as `0x603` byte 1 works for the probes. Byte 0 beside it separates "that channel is switched off in
the config" from "that channel failed": a bit in 0 and not in 1 is a sensor that did not read, or a
reading that could not be corrected. The session record's per-channel `reason` says which.

> **⚠ BYTES 2–3 AND BYTES 4–5 ARE TWO COUNTERS ON PURPOSE, AND COLLAPSING THEM WOULD REPEAT A FAULT
> THIS PROJECT HAS ALREADY PAID FOR.** Read errors count *transfers that did not complete*; CRC
> failures count *frames that arrived and could not be trusted*. They send a reader to different
> parts of the box — the bus and the mux for one, the sensor and its wiring for the other. On the
> thermal side one counter conflating the two is what left a probe sitting at 85.000 °C
> misclassified as a bus fault across two track days.

**Byte 7 should read 0, and anything else is a stuck worker or a bridged bus.** The worker
deselects the mux at the end of every cycle and publishes 0. **A cycle that has not finished after
1 s publishes nothing of its own**, so the BLE worker sends `0x607` with byte 7 set to the channel
the pressure worker is stuck on — 1, 2, 4, 8 or 16 for `P0`–`P4` — while `0x606`'s cycle counter
stops. **255 means the deselect itself failed**, which is the state in which a faulty downstream
segment may still be bridged onto the main bus. The session record's `muxControl` field carries the
same value (−1 for 255).

**Byte 6 is the lowest enabled channel's sensor temperature only** — the same part every cycle, so
a trend on the phone always means one sensor — and it is a diagnostic for the part rather than a
measurement of anything: the SDP810's compensation spans −20…85 °C and this says whether it is
inside it. **−128 means that part gave no valid reading this cycle**; the byte never falls back to
another channel. Per-sensor temperature at full resolution is in the session file; there is
no room for five of them here, and no consumer for them on the phone.

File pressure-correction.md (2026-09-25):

# Pressure correction — implementation plan

**Read this first.** This file is the executable plan for correcting the five SDP810 channels
before they reach RaceChrono. Each step below stands alone: it names the files, the change, the
command and the acceptance. **After executing a step, update its row in [Work Progress](#work-progress)**
with the status and what was done, so re-reading this file always shows where the work stopped
and what comes next. Work from `C:\_claude\KnurLogger` on the workstation and build on the box
(`ssh KnurLogger`, `~/KnurLogger/build`); [operations.md](operations.md) owns build and deployment.

[ndLouvers instrumentation-spec.md](../ndLouvers/instrumentation-spec.md) owns measurement
acceptance and [pressure-testing.md §2.4 step 4](../ndLouvers/pressure-testing.md#24-the-calibration-regime)
owns the correction's physics. The fitted values are in
[pressure-testing.md §3.3a](../ndLouvers/pressure-testing.md#33a-the-tubing) and §3.3b; read
them from there rather than from any copy.

## Decisions (owner, 2026-09-24)

1. **Divide.** The true pressure at the pickup is the reading divided by the combined factor
   `g(P)`. The SDP810 is a thermal mass-flow sensor calibrated at 966 mbar, so denser air makes it
   read high: `reading = Δp × P_abs/96 600 Pa`. At 1006.5 mbar a true 100 Pa reads 104.2 Pa.
   Dividing recovers 100 Pa; multiplying gives 108.6 Pa, applying the error twice. The bench ladder
   brought all five sensors within ±1.5 % only with division, and the span terms were fitted that way.
   **Do not implement the multiply form** — the old README's wording, see history 2026-09-24.
2. **Stale absolute pressure: hold, then invalidate.** Use the last valid BME280 pressure for up
   to 10 s — a steep climb moves it ~0.2 % in that time — then send the invalid sentinel on every
   corrected channel until a valid value returns. Raw counts are logged throughout. Every pressure
   record carries the absolute pressure used and its age.
3. **Configuration shape: constants plus lengths.** Global `r` and `R_fixed`, per-slot route
   lengths in metres, per-slot span pair `ε+`/`ε−`, and per-slot bypass-resistance fit
   (coefficient and exponent). The code computes `R_path`.

## The correction, in the form the code uses

For one channel with reading `rdg` (Pa, signed), absolute pressure `P_abs`, and the slot's values:

    B       = P_abs / 96 600 Pa
    ε       = ε+ if rdg ≥ 0, else ε−
    Δp_port = |rdg| / (B · (1 + ε))                      true Δp across the sensor's ports
    Q       = (Δp_port / (a · 10⁻⁶))^(1/(n + 1))          mL/s, from R_s(Q) = a · Q^n
    R_path  = Σ over the slot's lines with L > 0 of (R_fixed + r · L)
    P       = sign(rdg) · (Δp_port + Q · 10⁻⁶ · R_path)

This is §2.4 step 4's `P = reading / g(P)` solved explicitly: the sensor passes a flow `Q` set by
its own bypass curve, and the lines upstream and downstream lose `Q · R_path` before the sensor
sees the rest. A port left open to the bay has no line, no filter and no wand, so it has length 0
and contributes nothing. A zero reading corrects to zero.

**Reference values** for acceptance, with `a` = 2.093 × 10⁸, `n` = 0.615, `r` = 3.1 × 10⁶,
`R_fixed` = 2.6 × 10⁶:

| case | inputs | corrected |
|---|---|---|
| bench charge C, `P0`, rung 6 | rdg 364.86 Pa, `P_abs` 100 090 Pa, ε 0, L_H 10.088 m, L_L 0 | **398.885 Pa** (bell 394.5) |
| bench charge A, `P0`, rung 3 | rdg 101.94 Pa, `P_abs` 100 090 Pa, ε 0, L_H 10.088 m, L_L 0 | **119.611 Pa** (bell 121.7) |
| `P1`, negative, no lines | rdg −100 Pa, `P_abs` 101 325 Pa, ε+ 0.0091, ε− −0.0091 | **−96.212 Pa** |
| 70 Pa on 3 m + 3 m | rdg 70 Pa, `P_abs` 101 325 Pa, ε 0, L_H 3, L_L 3 | **78.463 Pa** |
| zero | rdg 0 | **0** |

---

## Step 1 — Configuration keys and data contracts

**Files:** `dataContracts.hpp`, `config.cxx`, `build/KnurLogger.ini`.

1. In `dataContracts.hpp`, add to the `[pressure]` group:
   1. `tubingResistancePerMetre` (Pa·s/m³ per m; bounds 1e5–1e8) and `lineFixedResistance`
      (Pa·s/m³; bounds 0–1e8), both global.
   2. Per slot, as format strings like `CONFIG_KEY_TEMP_OFFSET_C_FORMAT`: `p{}SpanPositive`,
      `p{}SpanNegative` (fraction; bounds ±0.05), `p{}LineLengthHighM`, `p{}LineLengthLowM`
      (m; bounds 0–20), `p{}BypassCoefficient` (Pa·s/m³ at 1 mL/s; bounds 1e7–1e9) and
      `p{}BypassExponent` (bounds 0–2).
   3. `SDP810_CALIBRATION_ABSOLUTE_PA 96600.0` and `PRESSURE_ABSOLUTE_HOLD_MS 10000`, each with a
      one-line comment saying why (the datasheet's calibration pressure; the hold bound's 0.2 %).
   4. The matching `AppConfig` fields, per-slot arrays indexed by mux channel.
2. In `config.cxx`, load the globals always and the per-slot keys **for every enabled channel**.
   A missing or out-of-range key is a startup error through `logErrorAndKill`, never a silent zero —
   the rule the thermal offsets already follow.
3. In `build/KnurLogger.ini`, add the keys with the §3.3a/§3.3b values: `r` 3.1e6, `R_fixed`
   2.6e6; spans 0/0 for `P0`, `P2`, `P3`, `P4` and 0.0091/−0.0091 for `P1`; bypass 2.093e8/0.615
   for `P0`, `P1`, `P3`, `P4` and 1.586e8/0.216 for `P2` (provisional, two points); **all line
   lengths 0** until the routes are measured on the car.

**Acceptance:** the logger builds, starts with the new template, and refuses to start — naming the
key — when one enabled slot's key is deleted.

## Step 2 — Share the BME280's absolute pressure with the pressure worker

**Files:** `dataContracts.hpp`, `bme280Sensor.cxx`.

1. Add to `Bme280Data` two atomics, `std::atomic<gdouble> heldPressurePa` and
   `std::atomic<guint64> heldPressureBootUs`, with a comment that they are the one cross-thread
   read of this struct and why (the pressure correction). `Bme280Data`'s "no lock" comment must be
   updated to say so.
2. In `sampleBme280()`, write both whenever `reading.isPressureValid` — never on an invalid
   reading, so the held value is always the last good one.
3. Add `gboolean getHeldAbsolutePressure(gdouble* outPa, guint64* outAgeMs)`, returning FALSE if
   no valid value has ever been read. `bme280Sensor.cxx` is included before `pressureSensors.cxx`,
   so the pressure worker can call it directly.

**Acceptance:** builds; a hand-run session's `enclosure` records and the held value agree.

## Step 3 — The correction

**File:** `pressureSensors.cxx`.

1. Add `gdouble getLinePathResistance(gint slot)` and
   `gboolean correctPressure(gint slot, gdouble readingPa, gdouble absolutePa, gdouble* outPa)`
   implementing the section above exactly. Its comment states the divide decision in one line; it
   does not cite this file.
2. At start the worker waits up to 2 s (`PRESSURE_ABSOLUTE_START_WAIT_MS`) for the first valid
   absolute pressure before its first cycle, so a normal start sends no uncorrected cycle and logs
   no stale event; past the bound it samples anyway and reports the pressure missing.
3. In `samplePressure()`, read the held absolute pressure once per cycle. For each valid raw
   reading: if the held value exists and is no older than `PRESSURE_ABSOLUTE_HOLD_MS`, correct it;
   otherwise the channel's sent value is `INT16_MIN` with reason `absolutePressureStale` (or
   `absolutePressureMissing`). **The raw `pressurePa` is kept unchanged.**
4. `pressureDeciPa` — what goes on the air — becomes the corrected value. The raw value stays in
   the record at full resolution beside it.
5. Log one `event` record when the absolute pressure goes stale and one when it recovers, not one
   per cycle (the rate-limiter pattern of `isChannelRefusalReported`).

**Acceptance:** a throwaway test harness, or a temporary `--selftest` path removed before commit,
reproduces every row of the reference table to within 0.001 Pa.

## Step 4 — Records and packets

**Files:** `pressureSensors.cxx`.

1. Each channel in the `pressure` record gains `correctedPa` (null when not sent). The record gains
   top-level `absolutePressurePa` and `absolutePressureAgeMs` — the value used, not the latest.
2. `pressureBaseline` gains a `correction` object: the formula name (`divide`), the hold bound,
   `r`, `R_fixed`, and per enabled slot its spans, line lengths, bypass fit and computed `R_path`.
   A recording then states its own correction, as the thermal offsets do.
3. `0x607`'s valid mask describes the **sent** value: a channel whose raw reading is valid but whose
   correction is stale is not valid there.

**Acceptance:** one hand-run session on the box shows the new fields, and `0x605`/`0x606` carry the
corrected decipascals.

## Step 5 — Offline check against a recording

**File:** new `Tools/pressure-correction-check.py`.

1. The script reads a session file, takes `correction` from `pressureBaseline`, recomputes every
   channel's corrected value from `pressurePa`, `absolutePressurePa` and the parameters, and reports
   the largest difference from the logged `correctedPa`, plus any stale-hold periods.
2. Run it on the step 4 session.

**Acceptance:** largest difference under 0.01 Pa on every channel; the stale-hold count matches the
`event` records.

## Step 6 — Deploy

1. **Hand-merge every new key into `~/bin/KnurLogger.ini` first** — deployment never touches that
   file, and a build with a missing required key crash-loops the service
   ([operations.md](operations.md)). Line lengths stay 0.
2. Build on the box, stop `KnurLogger.service`, deploy with `SystemSetup/deploy-logger.sh`, start
   the service, then back the production `.ini` up into `build/KnurLogger.ini` and commit.

**Acceptance:** the service runs; the phone shows the pressure channels; the session header's
`correction` matches the production `.ini`.

## Step 7 — Documentation

1. [racechrono-channels.md](racechrono-channels.md): `0x605`/`0x606` now carry the corrected
   pressure; the channel equations are unchanged.
2. [session-records.md](session-records.md): the new record fields and the stale-hold behavior.
3. [operations.md](operations.md): the new keys and where their values come from.
4. ndLouvers: `pressure-testing.md` §2.4 step 4 and `instrumentation-spec.md` Step 0b say the
   correction is implemented; `work-progress.md` Step 0b row.
5. [CLAUDE.history.md](CLAUDE.history.md): a dated entry. Run the sync pass and
   `python ../ndLouvers/tools/check-markdown-links.py`.

**Acceptance:** 0 link findings; no document still describes the correction as unimplemented.

## Step 8 — Route lengths (after the lines are cut on the car)

1. Enter each slot's measured `p{}LineLengthHighM`/`p{}LineLengthLowM` into `~/bin/KnurLogger.ini`,
   restart the service, back the file up, commit. A port ending in a pickup other than a wand
   adds that pickup's equivalent length — the hood tap's is in
   [surfaceStaticButton.md](3DPrinting/surfaceStaticButton.md#line-resistance).
2. Run the installed smoke test (ndLouvers `pressure-testing.md` §2.4 step 5).

**Acceptance:** every installed channel passes the smoke test; the session header's `R_path` per
slot matches the measured lengths.

---

## Work Progress

| Step | Status | What was done |
|---|---|---|
| Decisions: direction, stale input, config shape | **done** 2026-09-24 | Owner: divide; hold 10 s then invalidate; constants plus lengths |
| 1 — config keys and data contracts | **done** 2026-09-24 | Keys, bounds and `AppConfig` arrays in `dataContracts.hpp`; `config.cxx` loads the globals and every enabled slot's six keys; template carries the step 1.3 values and a header note. Built on the box; a hand-run starts with the template; deleting `p3BypassExponent` or `tubingResistancePerMetre` refuses naming the key, `p2SpanPositive=0.5` refuses as out of range, and a disabled `P3` with its keys deleted starts |
| 2 — share the BME280 absolute pressure | **done** 2026-09-24 | `heldPressurePa`/`heldPressureBootUs` atomics on `Bme280Data` (value written before time, read after, so a torn read overstates the age); written only on a valid pressure; `getHeldAbsolutePressure()` in `bme280Sensor.cxx`. Checked on the box with a temporary print never committed: five held values over 6 s equal the `enclosure` records' `enclosurePressurePa` exactly, ages within 1 ms of the records' `bootUs`. The first pressure cycle ran ~1 ms before the BME280's first sample, which step 3's start wait now covers |
| 3 — the correction | **done** 2026-09-24 | `getLinePathResistance()`, `correctPressure()`, `applyPressureCorrection()` and a one-shot stale/recover event pair in `pressureSensors.cxx`; `SdpReading` gains `correctedPa`/`isCorrected`, and `pressureDeciPa` is now the corrected value or `INT16_MIN`. A valid-but-uncorrected channel keeps `valid: true` with reason `absolutePressureMissing`, `absolutePressureStale` or `correctedOutOfRange` (past the wire's int16). A throwaway harness, never committed, built against the real sources on the box: every reference row within 0.0004 Pa, the template's `P1` loaded correctly, the sentinel cases send `INT16_MIN` with the raw value unchanged, and the hold holds at 9.9 s and goes stale at 10.1 s. The worker waits up to 2 s at start for the first absolute pressure: three hand-runs sent corrected values from the first cycle and logged no absolute-pressure event, and a harness showed the wait ending 3 ms after the value appears and giving up at 2003 ms without one. |
| 4 — records and packets | **done** 2026-09-24 | Each channel gains `correctedPa`; the record gains `absolutePressurePa`/`absolutePressureAgeMs` (the held value the cycle read, kept when stale so its age explains the refusal; null when none yet) and `sentMask`, which is what `0x607` byte 1 now carries, while `validMask` stays the raw validity. `pressureBaseline` gains `correction` (formula, calibration pressure, hold, `r`, `R_fixed`, per enabled slot its six values and `R_path`) and its `wireScaling` text says the air carries the corrected value. Hand-run on the box: the fields are present, and a temporary packet print, never committed, showed `0x605`/`0x606` equal to the records' `sentDeciPa` on 3 of 3 sampled cycles. In still air the corrections are hundredths of a pascal, so the live run shows the plumbing; the harness of step 3 shows the arithmetic. The stale path's `sentMask` was not exercised live |
| 5 — offline check | **done** 2026-09-24 | `Tools/pressure-correction-check.py`: recomputes each `correctedPa` from `pressurePa`, `absolutePressurePa` and the baseline's `correction`, checks `sentDeciPa`, explains every uncorrected valid reading, and matches stale-hold periods to their events; exit 1 on any failure. On the step 4 session (`2026-09-24T16-49-21.965026Z`) the largest difference is 0.00005 Pa, with 0 stale periods and 0 events. On a 20 s hand-run from a scratch `.ini` with lines on `P0` (10.088 m), `P2` (1.5 m) and `P3` (3 + 3 m) it is 0.00017 Pa, with `R_path` as computed by hand. A doctored copy with a stale period and its two events passes, and one with a single value off by 0.05 Pa fails. No real session has had a stale period yet |
| 6 — deploy | **done** 2026-09-24 | `~/bin/KnurLogger.ini` backed up to `~/bin/KnurLogger.ini.bak-20260924`, then hand-merged: 27 comment lines and the 32 new keys inserted, nothing else changed, and its values match the template exactly. The owner deployed with `deploy-logger.sh --execute` and started the service at 19:05:04; it is active with 0 restarts, and `~/bin/KnurLogger` is byte-identical to the build. Session `2026-09-24T17-05-04.760174Z`: the header's `correction` matches the production `.ini` key for key, and `pressure-correction-check.py` passes (largest difference 0.00007 Pa, no stale periods). Production's comments predated the template's cleanup, so at the owner's request they were brought to the template's wording (values checked identical first; the merged file kept as `~/bin/KnurLogger.ini.bak-20260924-merged`): production is now byte-identical to the committed `build/KnurLogger.ini`, so the copy back changes nothing. Phone check passed (owner, 2026-09-24) |
| 7 — documentation | **done** 2026-09-24 | `racechrono-channels.md` (the air carries the corrected value; `-32768` also for an uncorrectable reading; `0x607` byte 1 is the sent mask), `session-records.md` (new §Pressure correction), `operations.md` (new §Pressure correction settings; the forward-looking crash-loop note retired), README task map and Next; ndLouvers `pressure-testing.md` §2.4 step 4 and its status note, `instrumentation-spec.md` Step 0b note, `work-progress.md` reading path and Step 0b row. History entry added; link checker 0 findings |
| 8 — route lengths | not started — needs the lines cut on the car | |

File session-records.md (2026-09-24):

# Session records and interpretation

This file owns local-record interpretation. Measurement methods and admissible physical
comparisons live in the ndLouvers pressure and thermal companions.

## Counters and validity

1. `readErrors`, `crcFailures`, `i2cFirstAttemptFailures`, `i2cRecovered` and `i2cExhausted`
   are cumulative totals, including counters inside `channels[]`. Use the last record for
   a session total and differences between adjacent records for increments. Never sum totals.
2. Count invalid cycles using `valid`/`reason` or `validMask`, not a nonzero cumulative counter.
   The rule applies to pressure, enclosure and temperature records. For what reached the phone
   on a pressure channel, use `sentMask`; see the pressure correction below.
3. `appData.i2c.*` is shared across workers. An I2C count in a pressure record includes other
   bus users; the record containing it does not identify which sensor failed.
4. Check device presence before interpreting exhausted transfers. A missing device is different
   from a present device whose transfers fail.
5. A skipped BME280 measurement invalidates the enclosure values without necessarily incrementing
   the transfer-error count. Read status and validity rather than errors alone.

## Pressure correction

1. `pressurePa` is the raw reading and is never corrected. `correctedPa` is what went on the air,
   null when nothing did, and `sentDeciPa` is its wire form or `-32768`.
2. `validMask` is the raw validity; `sentMask` is what `0x607` byte 1 carried. A channel with
   `valid: true` and a reason of `absolutePressureMissing`, `absolutePressureStale` or
   `correctedOutOfRange` was read correctly but not sent.
3. `absolutePressurePa` and `absolutePressureAgeMs` are the held BME280 value the cycle read,
   including one too old to use — its age is the reason. Both are null before the first valid
   BME280 pressure.
4. A held value serves for up to 10 s; past that every enabled channel is sent invalid until the
   BME280 reads again. One `warning` event marks the loss and one `info` event the recovery. At
   start the worker waits up to 2 s for the first value, so a normal session has neither.
5. `pressureBaseline.correction` holds the parameters in force, per enabled slot with its computed
   `linePathResistance`. `Tools/pressure-correction-check.py` recomputes every `correctedPa` from
   it and checks the stale-hold events. A session with no `correction` was recorded before the
   correction existed and carried the raw value on the air.

## Clocks and alignment

1. Offline wall time and filenames can be wrong. NTP may step `taiUs` inside a session when
   the box regains a network. Compare `bootUs` across the same records before declaring data lost.
2. Use `bootUs` and `sessionUs` for elapsed timing. Do not carry an absolute-time offset between
   boots, or select a session solely by its wall-clock filename. Confirm its actual contents.
3. Match RaceChrono to the local file using the recorded cycle counter when available.
   For enclosure and temperature, `0x601`/`0x603` bytes 4–5 correspond to local `cycle`;
   account for counter wrap and separate recording fragments.
4. Without a usable link, use the thermal companion's physical alignment method:
   cross-correlate cavity temperature with GPS speed low-passed at approximately 180 s, and
   require substantial overlap to avoid spurious fits on a few edge bins. That is a fallback,
   not a universal clock offset.
5. Do not restore GPS-time fetching — see [CLAUDE.history.md](CLAUDE.history.md) §2.5.
6. A hard-cut file can simply end without a closing record or `BLE stopped` event. A clean
   shutdown records the BLE stop. Connection-event interpretation before the GLib context fix
   is limited as described in [ble-protocol.md](ble-protocol.md).

Record mounting state and measurement roles for the session. Neither a plausible value nor a
correctly decoded packet establishes where the sensor was or whether its pressure path was qualified.

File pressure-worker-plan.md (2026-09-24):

# Pressure acquisition — delivery and remaining verification

The acquisition implementation is delivered. The remaining acceptance is a recording audit;
this is distinct from the [pressure correction](pressure-correction.md).
Update Work Progress below after executing the audit, with the recording paths and outcome.

The original completed steps and evidence are in
[CLAUDE.history.md](CLAUDE.history.md#pressure-worker-delivery). Do not replay those steps or
restore the retired `pressureBaseline` documentation fields — see that history's 2026-09-23
entry on removing document citations. The current schema is implemented in the logger.

## Step 10 — Audit a recording containing pressure channels

1. Work from `C:\_claude\KnurLogger`. Obtain a RaceChrono `.rcz` with the pressure slots and
   the corresponding local logger session file. The channels and equations are in
   [racechrono-channels.md](racechrono-channels.md); export interpretation is in
   [ble-protocol.md](ble-protocol.md).
2. Run `python3 Tools/rcz-channels.py <session>.rcz`. Inspect every fragment, including
   `resume_<n>/`. Confirm the five defined pressure slots and their status channels appear.
   `Pressure Front 6` is deliberately absent because mux channel 5 is unpopulated.
3. Match samples using cycle counters and [session-records.md](session-records.md).
   Confirm decoded values and validity against the same local samples. Investigate all-empty
   channels; emptiness alone is not proof of a configuration error.
4. Acceptance: the five defined channels and status decode correctly against the local record,
   with no unexplained missing or empty channels. Record the checked artifact paths and result below.
5. After any phone-channel edit, repeat the disconnected-sensor sentinel check (negative
   pressure sentinel), verify the counter and re-export the profile following
   [RaceChrono/README.md](RaceChrono/README.md). A previous pass does not validate a later edit.

## Work Progress

| Original step | Status | Evidence / remaining work |
|---|---|---|
| 1–9 — acquisition implementation and bench verification | done | [Delivery record](CLAUDE.history.md#pressure-worker-delivery) |
| 10 items 1–4 — phone entry, sentinel, counter and export | done | Delivery record; repeat checks after any definition edit |
| 10 item 5 — recording audit | not started | Procedure above; acceptance remains unmet |
| 11 — original documentation sync | done | Delivery record; the current cleanup is recorded separately in history |

## Boundaries

1. Acquisition delivery qualifies no pressure channel. The measurement project owns acceptance.
2. Pressure role allocation remains [ndLouvers open item 30a](../ndLouvers/work-progress.md).
3. Automatic mux reset on exhausted transfers requires its own owner decision; do not infer it
   from the diagnostic reset procedure. The idle-bus physical cause remains open item 44.

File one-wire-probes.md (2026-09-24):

# The 1-Wire path — DS18B20 probes, the kernel, and what must not change

**This file owns 1-Wire behavior and standing requirements.**
[operations.md](operations.md) describes how to enroll probes, enter offsets and run the
fake-sysfs harness; this file says why each is shaped the way it is and what breaks if it changes.
`CLAUDE.history.md` holds the faults these guards came from — read it when a statement here
surprises you, never to reinstate something that looks missing.

**It owns no measurement decision.** [ndLouvers instrumentation-spec.md](../ndLouvers/instrumentation-spec.md) Step 0b's thermal-channels
subsection is the authority on what the thermal channels must achieve and what counts as done, and
`../ndLouvers/thermals-testing.md` holds the rig as built and every recorded result. A disagreement
between this file and Step 0b is resolved in Step 0b.

**Channel names are positional and mean nothing.** `temp0`–`temp3` are fixed by DS18B20 ROM ID at
enrollment, and a channel is never renamed after a role. The role map is decided and applied
(owner, 2026-09-09; enrolled in installed order 2026-09-10): **`temp0` = `T_ambient`,
`temp1` = `T_core_in`, `temp2` = `T_core_out`, `temp3` = `T_aft`** — confirmed independently by
warming each probe in installed order, which moved them in that order with clean separation.

---

## The probes and the bus

**A DS18B20 has no positional anchor.** Its 64-bit ROM ID *is* the channel definition, recorded
once at enrollment. **All four are bound as of 2026-09-10** — `temp0` `28-06254385da1f`,
`temp1` `28-0625424044b7`, `temp2` `28-062542ac86b6`, `temp3` `28-0625424e16c9` — in
`~/bin/KnurLogger.ini` on the box, in `build/KnurLogger.ini` in git, and in
`SystemSetup/logger-perfboard-wiring.md` §5a as the human record. **An earlier attempt the same day
bound three in a different order and was discarded** (history §1.11); do not reconcile anything
against it.
**The channel → role map IS independently confirmed** (2026-09-10): warming each probe by hand
in installed order moved `temp0`, `temp1`, `temp2`, `temp3` in that order with clean separation,
+3.8 to +5.4 K each. Plan open item 42 is closed on it.

**`w1-gpio`'s `pullup` parameter is ignored** on this firmware — the overlays README says so
outright. The overlay that drives an external strong pullup is a different one,
`w1-gpio-pullup`, and this build must not use it: `R11` is a plain 2.2 kΩ resistor to 3V3.

## The `28-*` family filter and the kernel behaviour behind it

**The `28-*` family filter is mandatory, and it can no longer be exercised on this box.** The
bare bus used to invent churning phantom `00-*` devices; with the sensor zone assembled and
`R11` terminating `GPIO4` the scans come back clean (history §1.4). The filter is correct
regardless of cause — a marginal 4 × 5 m star can produce garbage of its own — but its
correctness now rests on the parser rather than on an observation. Family code `00` is not a
valid 1-Wire family; a DS18B20 is family **`28`**.
1. **Match `28-*` and nothing else, everywhere** — enumeration, binding, and reads.
   `w1_master_slave_count` is not "off by one", it is **unstable**, and no code may branch on
   it.
2. **A `00-*` ROM ID must never be persisted** as a `temp` channel definition. Anything that
   auto-binds "the next device that appears" will bind noise within about ten seconds.
3. **An *empty* devices directory is the real failure signal**, because a working bus always
   registers its master.
4. **Bus rescan is every 10 s** (`w1_master_timeout = 10`), which is the hot-plug detection
   latency for anything that watches for a probe being connected. It cannot be shortened without
   root — the master attributes are root-owned and the logger runs as `chrum`.
## `therm_bulk_read` — the only way to sample four probes at 1 Hz

**`therm_bulk_read` appears the moment a probe attaches, and it WORKS — since 2026-09-11**
(history §1.15; before that the attribute had never existed here, because `w1_therm` registers
it as a **master** attribute only once a slave of its family attaches).
It is the documented way to convert every probe at once and the only way to sample four probes
at 1 Hz: without it each `w1_slave` read pays its own conversion — **799–832 ms measured on
the loaded four-probe star** — so a cycle was **3198–3281 ms**, i.e. **0.31 Hz** against plan
thermal item 2's ~1 Hz. **With it, measured at the car over 123 cycles: one 762–790 ms
conversion for all four probes, a 1023 ms mean cycle interval — 0.977 Hz — and zero CRC
failures across 492 reads.**
**TWO conditions are necessary and NEITHER alone is sufficient. Both are in place; do not undo
either.**
1. **The permission.** The cause was `errno 13`, `EACCES` — `w1_therm` registers the attribute
   `0644 root:root` and the logger runs as `chrum`, under `KnurLogger.service` too, whose
   `User=chrum` and `SupplementaryGroups=video i2c gpio` *extend* rather than replace chrum's
   own group memberships. `SystemSetup/grant-w1-bulk-read.sh` fixes that and **is applied**:
   the attribute comes up `root:gpio 664` and `chrum` writes it.
2. **The trigger is EIGHT bytes, newline included.** `therm_bulk_read_store` gates on
   `size == sizeof("trigger")`, which is 8. `oneWireProbes.cxx` wrote `strlen("trigger")` = 7,
   so the command was never parsed and `trigger_bulk_read()` was never called — for a day
   that looked like a permission fix that had not worked. `ONE_WIRE_BULK_TRIGGER_CMD` now
   carries the `\n`; **do not "tidy" it away.**
**A successful write is not a conversion, and cannot be**: `therm_bulk_read_store` returns the
write size unconditionally and reports its refusal only with `dev_info`. The evidence is
therefore the readback and the kernel log, never `write()`'s return value —
`journalctl -k | grep therm_bulk_read_store` prints the errno userspace never sees, and it is
empty on a healthy boot. `err=-22` is `EINVAL`, which only the size guard produces; `err=-19`
is `ENODEV`, which means the command was parsed and the bus had nothing on it.
Four further properties, each of which cost something to learn:
1. **`0` and `1` are different answers and the code used to treat them alike.** The attribute
   reads `-1` while converting, `1` when results are ready and unread, `0` when no bulk
   conversion is pending — which after a fresh trigger means the trigger did nothing. The
   readback is recorded as `bulkState` in every `temp` record and **`"1"` is the healthy
   value.**
2. **The steady-state readback is `1`, NOT `-1`.** `trigger_bulk_read()` sleeps the whole
   conversion inside the write, so by the time `write()` returns the results are already
   there. `-1` is only observable by a concurrent reader, and this worker is the only one — so
   a poll loop that recognised a conversion solely by seeing `-1` could never recognise one,
   which is what the first version did.
3. **Time the conversion from BEFORE the write**, for the same reason: a clock started after
   `write()` returns measures nothing and puts a 0 on `0x603` bytes 6–7 for the most expensive
   part of the cycle. It also separates a real conversion (~780 ms) from a bulk path that ran
   and failed its bus reset (~0 ms — which still marks every slave ready, so `bulkState` alone
   cannot tell them apart).
4. **`bulkConversion` means a conversion the kernel confirmed**, not a write that succeeded.
**Parasite power was the standing first suspect and it was WRONG** — do not return to it.
`ext_power` reads `1` on all four probes in the one-shot `probeCapabilities` record, measured
twice (2026-09-10 and 2026-09-11), so the strong pullup this bus lacks was never needed.
**`probeCapabilities.bulkReadState` reads `"0"` on a HEALTHY box and that is not a fault.**
The record is emitted after the per-probe reads, and reading `w1_slave` is what consumes the
ready flag. The authoritative field is `bulkState` in the `temp` records.
**Three properties of the udev rule that grants the permission**, each of which cost something
to get right:
1. **The rule matches the SLAVE add, not the master's.** The attribute is a *master* attribute
   that only exists once a slave of the family attaches, so the master's own add event fires
   long before it. The kernel creates the family's master attributes from the bus notifier
   during `device_add()`, which runs before the slave's `KOBJ_ADD` uevent — so the slave event
   is both the earliest point the attribute exists and a point at which it does.
2. **`gpio` is the group** because chrum is already in it and the bus is bit-banged on GPIO4.
   No new group, no new membership, and it covers the service and a hand-run alike.
3. **It is testable without a probe.** `--verify` writes a fake family-0x28 ROM ID to
   `w1_master_add`, which makes `w1_therm` bind and the attribute appear, checks that chrum
   can write it, then removes the fake slave. Reach for `w1_master_add` before concluding a
   w1_therm behaviour cannot be exercised on a probe-less box.
**Do not restore the once-per-cycle warning.** It logged 863 identical lines in 14 minutes at
the car and buried the two `BOUND` messages that were the point of the run.

## A pulled probe answers with NOTHING for ~100 s, and that is not a read error

**A probe pulled off the bus keeps its sysfs entry for ~100 s and answers with NOTHING, and
that must not count as a read error** (measured at the car, 2026-09-10). The kernel unregisters
a slave only after `w1_slave_ttl` (10) missed searches at `w1_master_timeout` (10 s), so for
up to ~100 s after a lead comes out the directory is still there, `w1_slave` still reads, and
the content carries neither `crc=` nor `t=`. That is a dropped lead, and the requirement in
§"Requirements this path carries from the plan" — "`absent` must not increment the read-error
counter" — applies to it for exactly the same
reason, arriving through the one path that still had a directory to read. Getting this wrong
charged **186 read errors to a bus that had not failed once** (history §1.12).
1. **The reason is `notAnswering`, and it is counted in its own field**, not in `readErrors`
   and not on `0x603` byte 2–3. A bus that is genuinely dropping out still shows here, so
   nothing is lost — it is just not confused with a bus that read badly.
2. **The split rule is the two markers, not the byte count.** `w1_therm` prints `crc=…` and
   `t=…` whenever the probe answered at all — a CRC failure prints both — so content with
   neither means the kernel got no reading. Content with one of them is malformed and *is* a
   read error.
3. **Unparseable content is now recorded** (`unparsed` in the `temp` record, truncated). The
   first version threw the bytes away, which is why the fault at the car could not be told
   apart from a marginal bus without going back.

## 85.00 °C is a reading, and the power-on default is deliberately not detected

**A reading of exactly 85.00 °C is accepted like any other temperature** (owner, 2026-09-23;
`../ndLouvers/` open item 53, closed). 85.00 °C is the DS18B20's power-on scratchpad default AND a
temperature a probe can be at, and the scratchpad is byte-identical in both cases —
`50 05 4b 46 7f ff 0c 10 1c`, with a valid CRC — so nothing in the reading can separate them.
`T_aft` peaks at **101.25 °C** and spends 2 351 samples above 85 °C in post-run heat soak; **the aft
probe lives in this band**, so a check keyed on the value flags a hot probe far more often than a
reset one. The owner prefers keeping every reading over flagging.

1. **The accepted blind spot:** a genuine power-on reset now passes as a plausible 85.00 °C
   reading, with `valid` true and no reason code. One is on record — all four probes in the first
   cycle after boot, 14.1 s in, in the two-day session `2026-09-11T18-08-06`. **Four probes
   reading exactly 85.00 °C together in a session's first cycle is the signature**; a transit sits
   between neighbours a resolution step (~60 mK) away.
2. **There is no `powerOnDefault` reason code**, and `TEMP_POWER_ON_DEFAULT_CENTI_C` is gone. **Do
   not reinstate the check** — `CLAUDE.history.md`, 2026-09-23.
3. **Sessions recorded before 2026-09-23 still carry `powerOnDefault` flags**, and they are the
   historical record: in the two-day session 21 of them, four the genuine boot-cycle reset and 17
   `temp3` transiting 85.000 °C with a good CRC — none a bus fault. **In those sessions `0x603`
   bytes 2–3 counted the flags too**, so there it is not a bus-quality figure on its own
   (`../ndLouvers/thermals-testing.md` §2.5 item 3, §3.11).

The measurement-accuracy question, open item 52, was **dropped** (2026-09-20): every `T_aft` sample
above 85 °C is permanently an indication, not a measurement.

## Testing the whole path without probes

**The whole 1-Wire path IS testable without probes, and this is how** (2026-09-10).
`unshare -Urm --map-root-user` gives an unprivileged user namespace with a private mount
namespace, so a fake tree can be bind-mounted over `/sys/bus/w1/devices` — **no root, no sudo,
no risk to the real box, and nothing to undo** since the namespace dies with the shell.
Populate it with `w1_bus_master1/`, `28-…/w1_slave` files in the kernel's two-line
`crc=xx YES` / `t=<millidegrees>` format, and a `00-…` entry to prove the family filter drops
it. Enrollment order, the ambiguous-step refusal, the store's family and duplicate guards,
bound-but-absent, CRC failure, out-of-range rejection and the
application of a hand-entered offset were all verified this way. **Reach for this before
concluding a sysfs-driven path is untestable.**

**Its one limitation: a plain file cannot emulate an attribute whose read value differs from what
was written**, and `therm_bulk_read` is exactly that — you write `trigger` and read back
`-1`/`0`/`1`. In the fake tree it reads back `trigger`, so that state machine is unexercised, and
neither is real bus timing or real conversion time. **So the harness covers every branch a plain
file can represent, which is not every branch.** Two workarounds fill the gap and are worth
reaching for before concluding something is untestable: a **FIFO** in place of `w1_slave` makes a
read block for a controlled time, which is how the `conversionMs` fallback was verified; and
**`w1_master_add`** attaches a real family-0x28 slave with no hardware, which is how the udev rule
was verified.

## Requirements this path carries from the plan

These two came from the ndLouvers specification rather than from
`iSitePiLogger`. A third — an automatic session-start thermal sample — was implemented and
then **retired whole**; do not rebuild it, and read history §3.1 before concluding it is
missing by accident.

**The logger binds `temp0`–`temp3` itself, by discovery order, and persists the binding**
(owner decision, 2026-09-09). The owner plugs the four DS18B20s in one at a time, lowest channel
first; the logger notices each new `28-*` ROM ID and writes the binding to a store that survives
restarts. This replaces reading ROM IDs off a bench rig and typing them into a config by hand.
Eight things make it correct rather than merely convenient, and skipping any of them produces
silently mislabelled temperature data — which is worse than no data, because ΔT_preheat rests on
the *differences* between these four probes:
1. **`28-*` only.** The bare bus invents churning `00-*` phantoms (see the family-filter trap
   above). Binding "the next new device" without the family filter binds noise.
2. **Binding happens only in an explicit enrollment mode, never during a logging run.** A
   dropout and reconnect mid-session, or a probe replaced after a failure, must not silently
   re-bind a channel. Outside enrollment an unknown ROM ID is **invalid data and a logged
   event**, not a new channel.
3. **One probe per enrollment step.** If two unbound `28-*` IDs appear in the same 10 s scan the
   arrival order between them is unknowable — sysfs order is not arrival order — so the logger
   must refuse the ambiguous step and say so rather than guess.
4. **The binding carries provenance: the ROM ID, the channel and the bind timestamp**, and it
   lives in the `[thermal]` section of `KnurLogger.ini` beside the binary, as `temp<N>RomId` /
   `temp<N>BoundTaiUs` / `temp<N>BoundIso` (owner decision, 2026-09-10; history §2.7).
   **There is no `channels.ini` and no separate binding store — do not rebuild one.** One file
   holds the whole logger configuration, and the bindings sit in the same section as the
   slot-keyed offsets they invalidate when they change, which is where that consequence is
   visible rather than filed elsewhere. Two properties the machine-written file keeps:
   an empty `temp<N>RomId` is an unbound channel and a legitimate state, unlike a missing offset
   which is a startup failure; and a hand-typed ROM ID is guarded exactly as a scanned one is —
   the `28-*` family filter and the one-probe-one-channel rule both apply on load.
5. **Enrollment must report which ROM ID it just bound**, so the binding can be checked against
   the lead being plugged in. **The probes are already installed on the car** (owner,
   2026-09-09) and the owner can identify each lead at the logger end, so enrollment binds
   channel → location directly and the older "mark the probe body" step is moot. Provide an
   identification fallback anyway: with all four bound, **warming one probe by hand must be
   visible as one channel moving**, which confirms the map in situ and doubles as a liveness
   test.
6. **A BOUND channel whose ROM ID goes absent must be logged as present-but-invalid, never
   omitted** (owner, 2026-09-10). Iterating the four channels rather than the devices present on
   the bus is what produces it. If the record simply loses the channel, a mid-session dropout
   becomes indistinguishable from the logger not having run — which destroys the one property the
   SD file exists for, namely that a gap in the local stream is the only evidence a sample was
   missing rather than held. The sentinel goes out on `0x602` for it, and `reason` in the session
   record separates `unbound`, `absent`, `notAnswering`, `unparseable`, `crc`,
   `outOfRange`, `readFailed` and `cycleAbandoned`.
   **`absent` must not increment the read-error counter.** A dropped lead and a marginal bus send
   you to different parts of the car, and inflating `0x603` byte 2–3 with absences would bury the
   bus-quality signal it exists to carry.
7. **Every probe stays plugged in once it is in** (owner procedure, corrected 2026-09-10 after
   the first attempt at the car did the opposite; history §1.11). Unplugging each probe as the
   next goes in *binds correctly*, which is what makes it easy to get wrong, and costs three
   things binding does not: the four-probe star is never loaded, so plan thermal item 1's star
   acceptance criterion (closed rev 77, on a run with every probe connected) is untouched and the
   run proves nothing the ESP32 bench rig had not already proved with single probes; rule 5's warm-one-probe map check needs four live channels
   and becomes impossible; and every unplug leaves a ~100 s tail of a channel present in sysfs
   and answering with nothing.
8. **Enrollment must keep running after the fourth bind** (owner, 2026-09-10). Requirement 5's
   fallback check *is* "warm one probe and watch which channel moves", and that needs a logger
   still sampling and still notifying. An enroller that exits on the fourth bind silently
   removes the only in-situ verification of the map. It reports a fifth ROM ID once and refuses
   it; `--enroll --reset` is the way to start over.

**Per-channel offsets are hand-entered in `KnurLogger.ini` and ARE APPLIED to what goes to
RaceChrono** (owner decisions, 2026-09-10). Two earlier positions were reversed to get here —
"never auto-apply an offset" and ROM-ID keying in the store — so do not restore either from git
history; history §2.3 and §2.4 carry both, and §2.3 in particular states the one condition the
reversal rests on: **the session record carries the raw reading (`centiC`), the offset in force
(`offsetC`) and the value sent (`sentCentiC`) side by side, and anything that drops the raw value
re-opens the original objection.**
**The consequence of slot-keying, stated once because it is real:** an offset is a property of
one particular DS18B20, so if the probes are re-enrolled in a different order, or one is swapped,
the offsets stay with the slots and no longer describe the parts in them. **Re-check them after
any re-enrollment.** What it buys is that the offsets sit in the same `[thermal]` section as the
`temp<N>RomId` bindings that say which probe each slot holds (owner decision, 2026-09-10), so a
changed binding is visible three lines from the offset it invalidates. **The production
`KnurLogger.ini` is NOT in git** — `operations.md` carries the dev/production split — so
copying it back into the repo after a calibration is the only thing that version-controls it.
Five further properties:
1. **All four keys must be present.** `temp0OffsetC`..`temp3OffsetC` in `[thermal]`; a missing
   one is a startup failure rather than a silent zero, because an offset that quietly stopped
   being applied would be invisible in the data it corrupts. A non-numeric value and one past
   the bound also refuse to start.
2. **Two bounds, deliberately different in kind.** Past ±5 °C it warns about a likely
   decimal-point slip and applies the value anyway; past ±50 °C it refuses to start. A logger
   that will not start in the car over a plausible-but-large typo loses the whole session, which
   is worse than a wrong offset that is recorded and reversible.
3. **Only relative offsets mean anything.** There is no reference thermometer on the car, and
   ΔT_preheat depends on the four probes' differences rather than their absolute accuracy, so
   what belongs there is each probe's deviation from the four-probe mean at equilibrium.
4. **All four offsets are currently 0.0, and that is the RESULT** (owner, 2026-09-10). The
   in-situ cold soak measured a 0.193 K spread across the four probes, ~3 % of a ~6 K ΔT_preheat
   signal and inseparable from a real spatial gradient across four locations, so the owner's
   decision was to enter nothing. **Do not "fix" the zeros.** Plan open item 41 is closed on it.
5. **The result is clamped clear of `INT16_MIN`.** A corrected reading that landed exactly on the
   invalid sentinel would be indistinguishable from "no reading at all".

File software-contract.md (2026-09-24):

# Logger software contract

This file owns implementation invariants. Measurement acceptance is in
[ndLouvers instrumentation requirements](../ndLouvers/instrumentation-spec.md).
Read [hardware-interface.md](hardware-interface.md) for I2C, [one-wire-probes.md](one-wire-probes.md)
for thermal sampling, [ble-protocol.md](ble-protocol.md) for BLE, and
[session-records.md](session-records.md) for interpreting local records.

## Architecture

Follow `iSitePiLogger`, which is the structural model:

1. **Single translation unit.** All `.cxx` files are `#include`-d into `main.cxx`. Do not add them
  to `CMakeLists.txt` as independent targets.
1. **`initialiseBlePackets()` is called exactly once, from `main`, before any worker starts.**
  Initialise shared packet state in `main`, never in a worker — `CLAUDE.history.md` §1.5 is the latent bug that
  made this a rule.
1. **Procedural workers, no OOP.** Plain `gpointer fn(gpointer)` passed to `g_thread_new()`.
1. **`CLOCK_TAI` throughout**, to avoid leap-second discontinuities in sample timestamps and file
  names.
1. **The `.ini` sits beside the binary** and its path is resolved from `/proc/self/exe`, not the
  working directory.

Four requirements came from the plan rather than from iSitePiLogger. Two of them — DS18B20 channel
enrollment and the calibration offsets — moved to [`one-wire-probes.md`](one-wire-probes.md) with
the rest of that subsystem, along with a fifth that was implemented and then **retired whole**.

1. **BLE is the primary data path; the SD card is the durable raw and diagnostic record**
  (owner decision, 2026-09-09, item 5b — this **reverses** the earlier "SD primary, BLE
  secondary", so do not reinstate that from memory or from git history; `CLAUDE.history.md` §2.1). The analysis
  record is RaceChrono's consolidated log, because RaceChrono is what collects box 1's CAN
  broadcast, box 2's channels and the phone's GPS and stamps them into one frame set on one
  timebase. Box 2's channels have to reach the phone to be useful.
  **The local file is still mandatory, on three narrower grounds** — and each one is a thing the
  BLE path physically cannot do:
  1. **Link-level loss cannot be signalled over BLE.** *Channel*-level invalidity can: send
     `-32768` (`INT16_MIN`) for any channel with no trustworthy reading and RaceChrono decodes an
     unmistakable −327.68 °C, which is what the ESP32 rig already does. But a dropped connection,
     a phone that stopped recording, or a dead logger leaves nobody to send a sentinel, and
     RaceChrono presents the last value it received indefinitely. **A gap in the local stream is
     the only evidence that a sample was missing rather than held.**
  2. **Item 4's diagnostics are not channel-shaped** — raw counts, the retained scale factor,
     sensor temperature, product/revision/serial, per-sample validity flags.
  3. **Supply telemetry is SD-only by nature**, because the event worth catching is a brownout at
     a brownout — with the constant feed as built, a cranking dip or the fuse being pulled.
1. **Append-only session file, `fsync` on a fixed ~1 s cadence** — not per sample, not only at
  close. The supply vanishes without warning — the fuse pulled at the end of the day, or a
  cranking dip — so the last durable write bounds the loss. Flushing per sample at 10 Hz buys a
  shorter window at the price of write amplification without changing the failure mode.
1. **DS18B20 channel enrollment and the calibration offsets** — both in
  [`one-wire-probes.md`](one-wire-probes.md) §"Requirements this path carries from the plan",
  with the retired session-start thermal sample recorded there too.
1. **Supply health is logged telemetry, read after a run** (owner decision, 2026-09-09), standing
  in for a bench instrument on commissioning item 5.7. It does not replace build sheet §10 step 2's
  meter, which is retired — do not rebuild it ([ndLouvers risk 14](../ndLouvers/risk-register.md)).
  What to record, and the traps:
  1. **`vcgencmd get_throttled`** is the useful one, because bits 16–19 **latch** "has occurred
     since boot". That is what makes a 1 Hz sampler unable to miss a transient. Log the live bits
     *and* the sticky bits, and log the **first transition with a timestamp** — "something
     happened during a 40-minute session" is far weaker evidence than "it happened 3 s after the
     fan engaged". Cost measured at ~3 ms per call, so 1 Hz is free.
  2. **`/sys/class/hwmon/<n>/in0_lcrit_alarm` on the `rpi_volt` device** is the same undervoltage
     comparator without a subprocess, but it is **live only, with no sticky history**. Resolve it
     by reading each hwmon's `name` file — **the hwmon index is not stable across boots**, and it
     was `hwmon1` on one boot only.
  3. **`vcgencmd measure_volts core` is NOT the supply rail.** It reports the regulated SoC core
     voltage (~0.906 V) and says nothing about the 5 V input. Logging it beside the throttle
     flags invites exactly that misreading; if it is logged, name the field so it cannot be
     mistaken for a rail measurement.
  4. **This telemetry must reach the fsync'd session file, not only the journal.** The event most
     worth having is a brownout, which on the constant feed as built means a cranking dip or the
     fuse being pulled — the moment the box loses power.

Preserve CRC failures, clipping, disconnects and stale samples as **invalid data**, never as
carried-forward values presented as new.

## Configuration and startup constraints

1. Preserve unrelated configuration bytes when saving bindings. Do not use
   `g_key_file_to_data()` to write the file: it damaged non-ASCII comments. Keep GKeyFile for
   reading and the line-preserving binding writer for changes; see `CLAUDE.history.md` §2.7.
2. Do not depend on `network-online.target`; host setup masks NetworkManager's wait-online
   service. The logger must start without a network, using its own readiness checks.
3. Pressure acquisition warns on an unknown product or unexpected scale factor and retains the
   returned identity; it must not silently substitute a known part. Reject an invalid zero scale
   factor before conversion. The configured channel list forbids unpopulated channel 5.
4. Automatic mux reset on exhausted transfers is not an approved recovery policy. The manual
   diagnostic reset in hardware-interface.md does not authorize adding it to the worker.

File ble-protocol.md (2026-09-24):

# BLE behavior, diagnostics and recording audits

[racechrono-channels.md](racechrono-channels.md) owns packet bytes, equations and the phone slot
map. [CLAUDE.history.md](CLAUDE.history.md) owns incidents and diagnoses; this file owns the
current protocol constraints and reusable checks.

## Subscription handling

1. RaceChrono requests the union of packet IDs defined for every connected DIY device.
   Unknown IDs are normal traffic: log and ignore them without returning an ATT error.
   An error can abort the subscription burst after `deny all`, leaving the display frozen.
2. Logging starts with `deny all` followed by `allow single` requests. CAN-bus test mode uses
   `allow all`, so success there does not prove the logging subscription sequence works.
3. Accept command-length minima, not exact-length equality, so optional future fields do not
   turn a valid command into a rejection. Do not reinstate the old strict checks; see `CLAUDE.history.md` §1.
4. With filtering honored, a packet without any defined phone channel is never sent.
   Use a defined free-running counter for link-loss checks. The packet reference owns their offsets.
5. The two boxes share the phone's channel list. Adding a channel for one can expose a
   subscription-handling bug in the other. Do not assume separate repositories mean independent
   protocol configuration.

## GLib context ownership

1. Call `g_main_context_push_thread_default()` before `g_bus_get_sync()` and
   `binc_adapter_get_default()` in the BLE worker. GDBus binds subscriptions to the current
   thread-default context; this headless program does not iterate the global default context.
2. Keep disconnect handling: clear notification state and restart advertising so a lost link
   can reconnect. Missing adapter callbacks can silently prevent both.
3. KnurDash's GTK main loop iterates the global context. Do not copy this headless ordering fix
   into that app merely because its order differs.
4. Local records before the context fix on 2026-09-10 omit BLE connection events. Their absence
   is not evidence that no phone connected; see the dated history record.

## The phone is part of the instrument

1. The logger cannot detect a missing or incorrect phone equation. Compare a RaceChrono export
   with the local logger record of the same samples.
2. Re-run the disconnected-sensor sentinel check after any channel-list edit. Positive thermal
   values cannot distinguish signed from unsigned decoding. Differential pressure can be
   negative during normal operation, so signedness matters beyond the sentinel.
3. RaceChrono stores defined decoded CAN channels, not every byte of the arriving frame.
   An undefined CAN byte cannot be recovered from an old `.rcz`. Defining it later helps only
   later recordings; the thermal companion owns the affected-session record.
4. The saved profile and restoration procedure live in [RaceChrono/README.md](RaceChrono/README.md).
   Compare exports by `(pid, channelId)`, not textual diff order. Preserve the exported array
   order and strip `localUuid`; re-import with a sorted array has not been validated.

## Audit an export without the phone

Run from the KnurLogger checkout:

```bash
python3 Tools/rcz-channels.py session.rcz
```

1. A channel ID is `slot * 2**20 + channelType`. Types used here are Digital 70537,
   Temperature 70539, Pressure 70541 and Percent 70547. An old export records the slots in
   force then; disagreement with today's map does not by itself make either wrong.
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

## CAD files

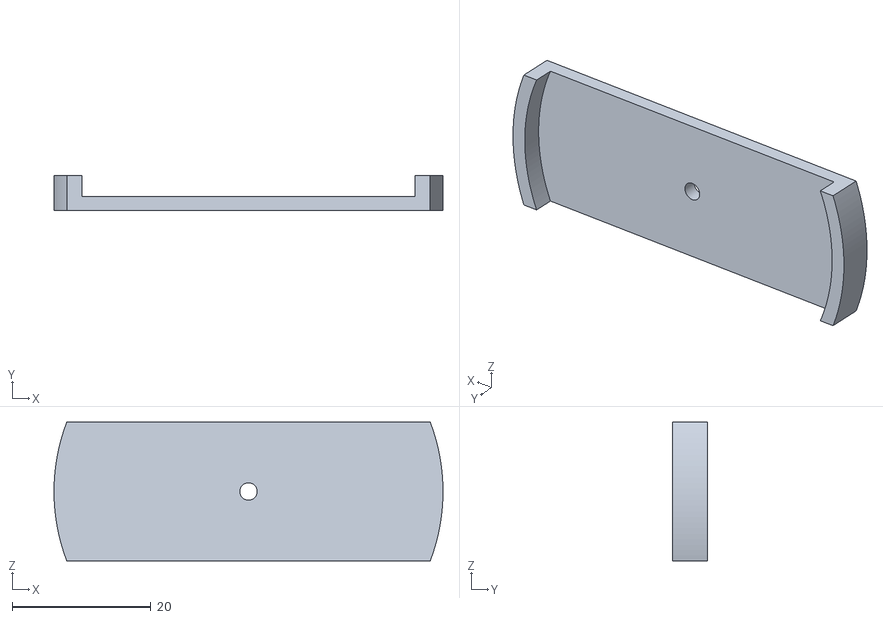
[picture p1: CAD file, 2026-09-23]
3DPrinting/calibrationBellPan1.stl
56.0 x 5.00 x 20.0

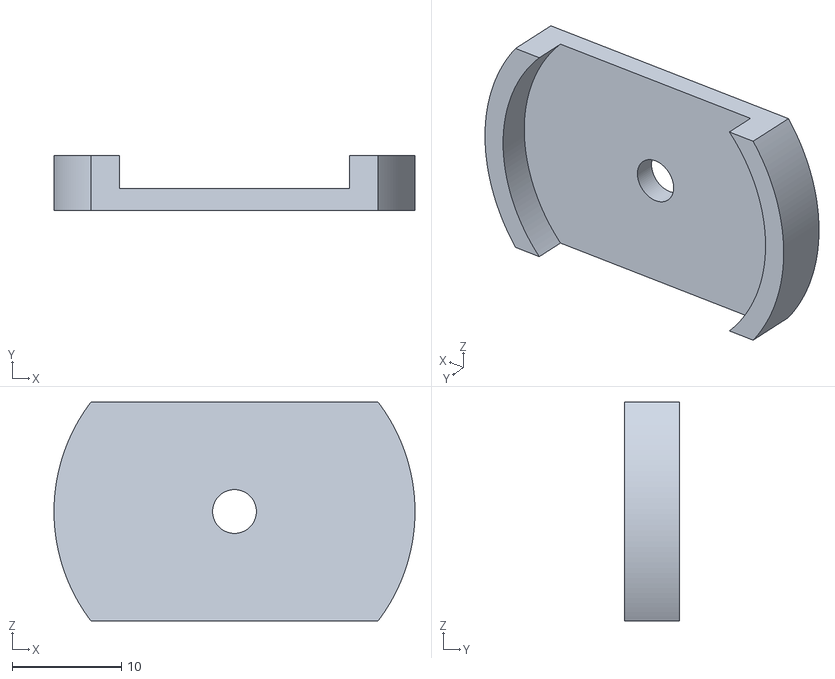
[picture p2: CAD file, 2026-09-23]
3DPrinting/calibrationBellPan2.stl
33.0 x 5.00 x 20.0

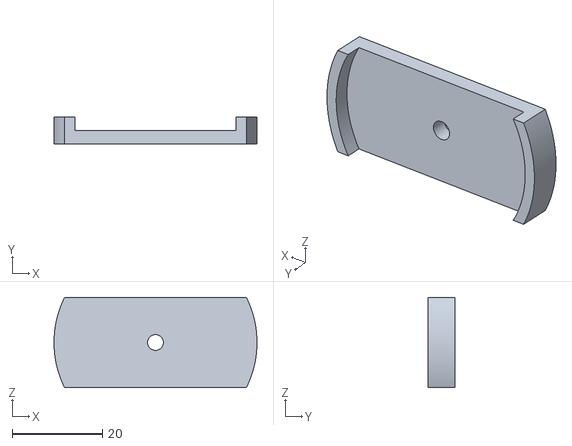
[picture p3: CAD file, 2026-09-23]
3DPrinting/calibrationBellPan3.stl
45.0 x 6.00 x 20.0

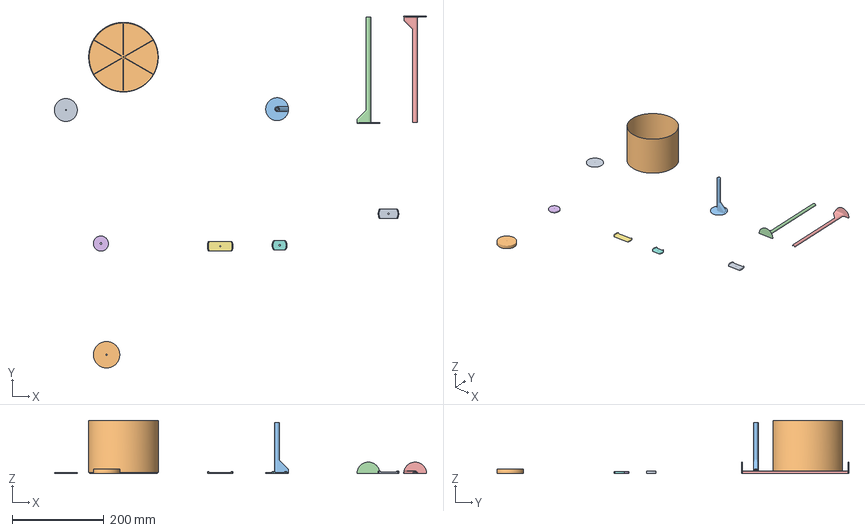
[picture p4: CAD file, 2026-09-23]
3DPrinting/calibrationBell.3mf
811.3 x 767.2 x 115.8 mm
calibrationBellPan.stl
calibrationBell.stl
pipeStand.stl
pipeStand1.stl
pipeStand2.stl
calibrationBellPan2.stl x 2
calibrationBellPan1.stl
calibrationBellPan3.stl
calibrationBellPan4.stl

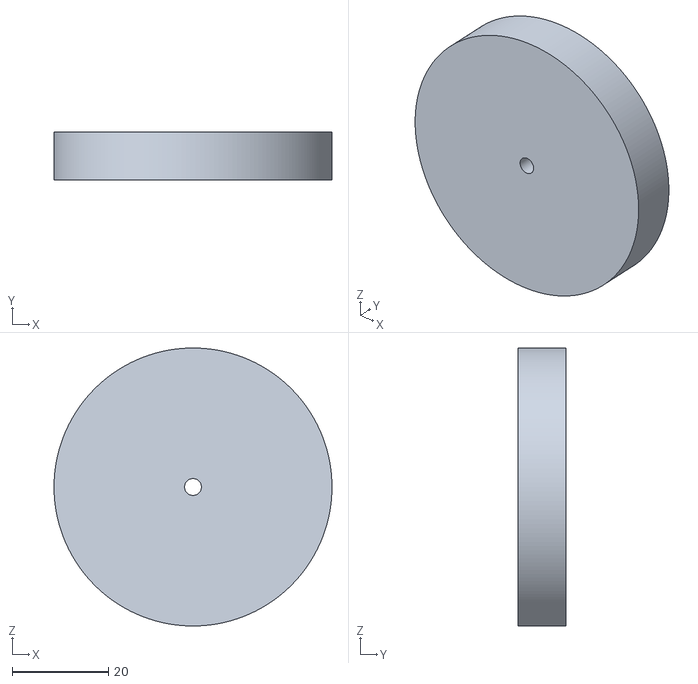
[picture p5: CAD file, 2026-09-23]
3DPrinting/calibrationBellPan4.stl
57.7 x 10.0 x 57.7

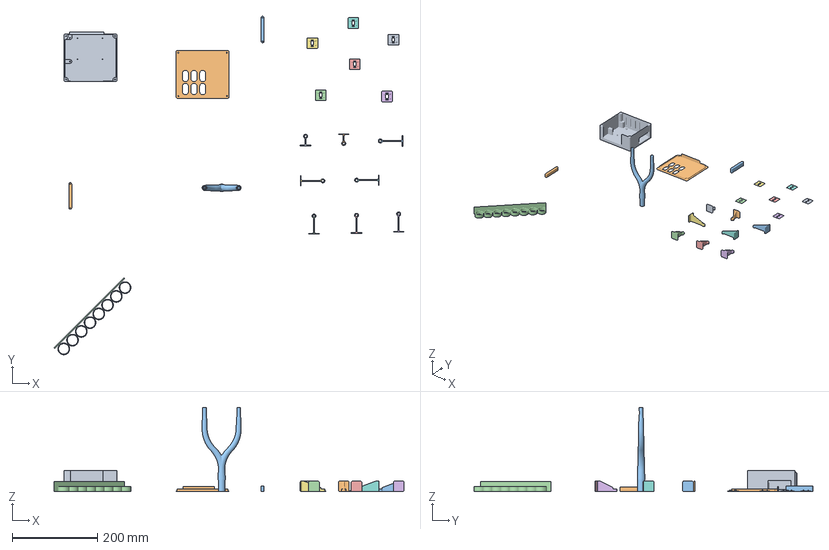
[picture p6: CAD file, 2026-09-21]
3DPrinting/KnurLogger.3mf
820.1 x 793.4 x 198.0 mm
case.stl
cover.stl
pcbHolder.stl x 2
cableTab.stl x 6
boomTip.stl
sensorHolderXL.stl x 3
sensorHolderXXL.stl x 3
sensorHolderL.stl x 2
filterHolder.stl

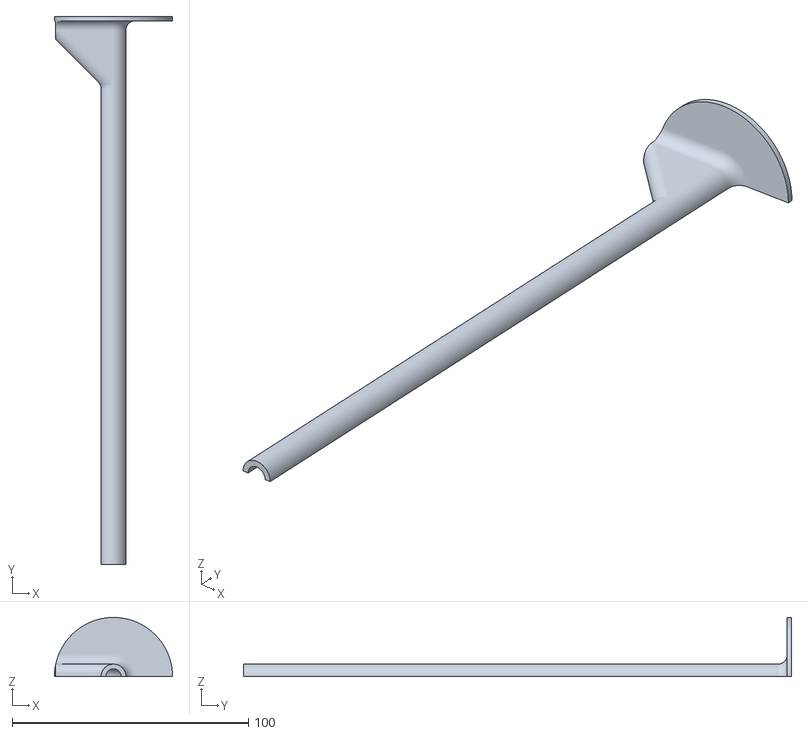
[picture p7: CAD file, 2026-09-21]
3DPrinting/pipeStand2.stl
50.0 x 231.8 x 25.0

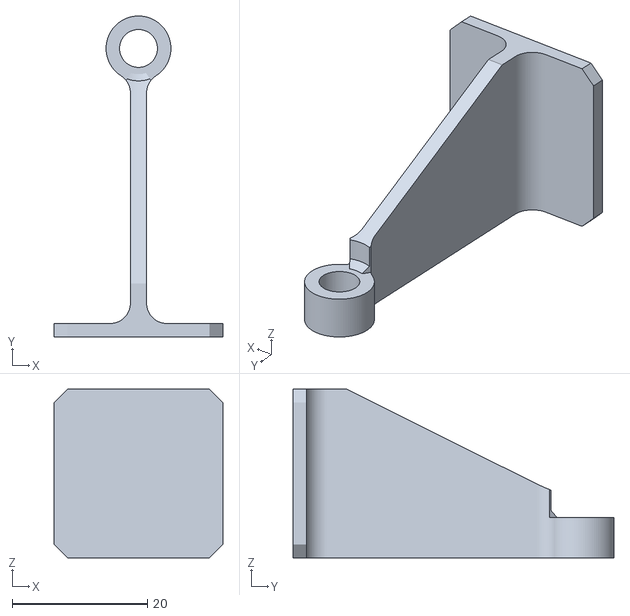
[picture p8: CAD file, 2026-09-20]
3DPrinting/sensorHolderXL.stl
25.0 x 47.5 x 25.0

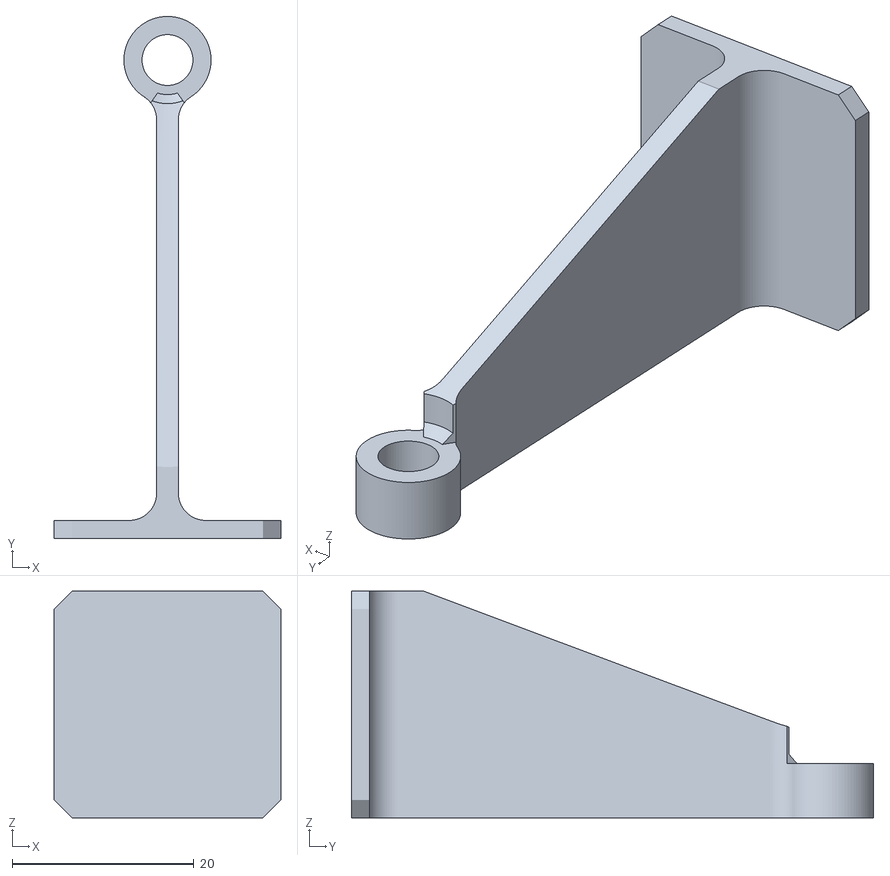
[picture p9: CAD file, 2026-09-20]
3DPrinting/sensorHolderXXL.stl
25.0 x 57.5 x 25.0

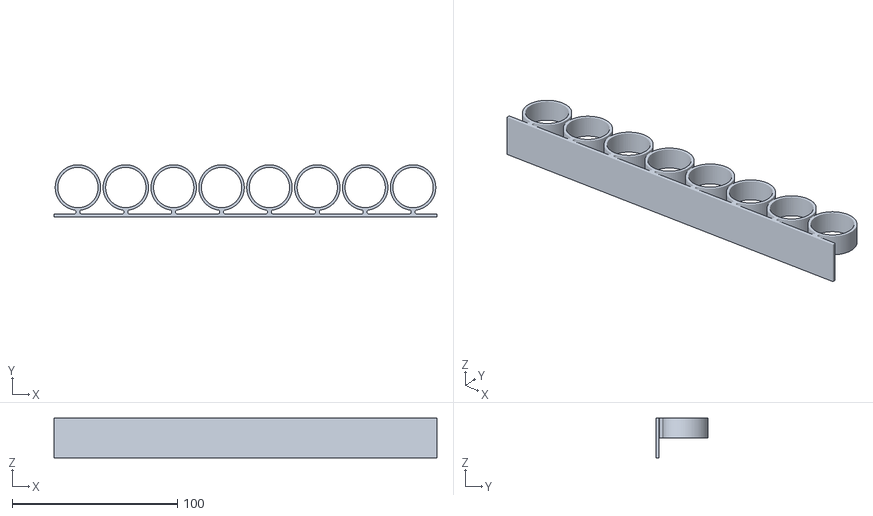
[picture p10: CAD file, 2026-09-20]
3DPrinting/filterHolder.stl
232.0 x 31.8 x 24.0

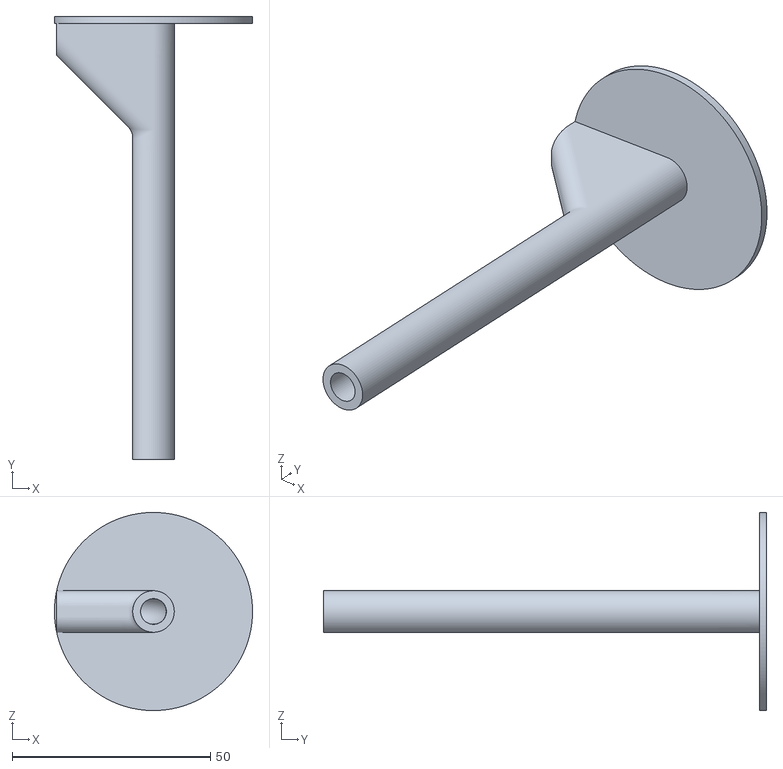
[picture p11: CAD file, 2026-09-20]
3DPrinting/pipeStand.stl
50.0 x 111.8 x 50.0

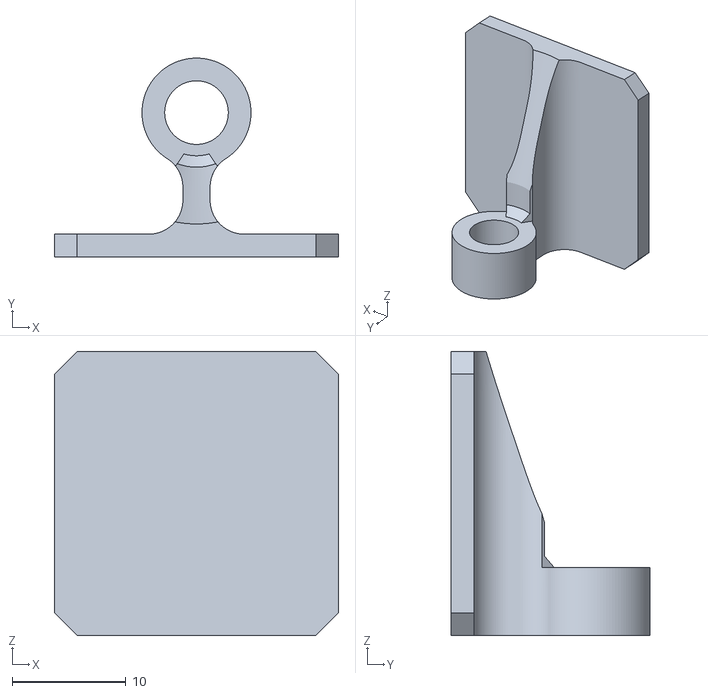
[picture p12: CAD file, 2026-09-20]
3DPrinting/sensorHolderS.stl
25.0 x 17.5 x 25.0

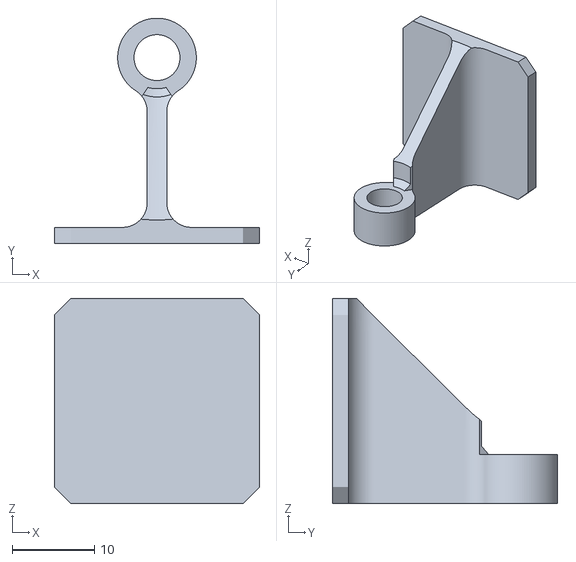
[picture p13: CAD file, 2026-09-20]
3DPrinting/sensorHolderL.stl
25.0 x 27.5 x 25.0

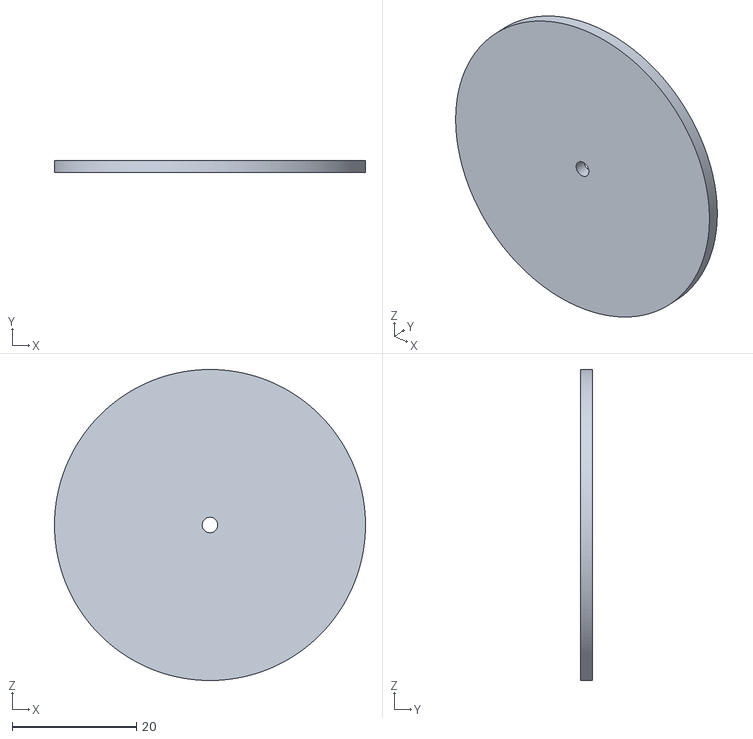
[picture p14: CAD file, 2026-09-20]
3DPrinting/calibrationBellPan.stl
50.0 x 2.00 x 50.0

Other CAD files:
3DPrinting/ruler.FCStd
3DPrinting/pipeStand1.stl
3DPrinting/boomTip.stl
3DPrinting/cableTab.stl
3DPrinting/calibrationBell.stl
3DPrinting/case.stl
3DPrinting/cover.stl
3DPrinting/pcbHolder.stl

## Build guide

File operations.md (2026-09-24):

# Build, deployment and operation

Run commands from the KnurLogger checkout unless a command explicitly uses the remote host.
[SystemSetup/pi-headless-setup.md](SystemSetup/pi-headless-setup.md) owns host setup and its progress.

## Repository, deployment and where the code is built

Upstream is **https://github.com/chrumck/KnurLogger** (`origin`), and it is **public** — see the
note at the end of this section before adding anything host-specific.

The box has the full toolchain (`git 2.47.3`, `cmake 3.31.6`, `gcc`/`g++`, `libglib2.0-dev`), so
**the code is built on the Pi**, not cross-compiled. First time:

```bash
ssh KnurLogger 'git clone https://github.com/chrumck/KnurLogger.git'
```

Thereafter `git -C ~/KnurLogger pull` on the box. The `build/` directory is gitignored except for
its tracked `KnurLogger.ini`, which is the **template**, not the deployed file.

### The dev copy and the production copy are two different files

The logger is **built** in `~/KnurLogger/build/` and **run** from `~/bin/`, and the two are kept
apart deliberately (owner decision, 2026-09-10):

| | Path | Owned by | Carries |
|---|---|---|---|
| dev | `~/KnurLogger/build/KnurLogger.ini` | git, overwritten by every sync | the seed, and the **version-controlled backup** of whatever was last copied back |
| production | `~/bin/KnurLogger.ini` | the box and `--enroll` | the live ROM ID bindings, offsets and pressure correction settings |

The dev copy is not permanently empty: it carries the four ROM IDs enrolled on 2026-09-10, copied
back after the trip. That is what makes it a backup rather than only a template — a fresh box
seeded from it starts with the current bindings, which is right, since the probes it will read are
the same four.

**The reason is that the configuration and the source now share a file.** `KnurLogger.ini` carries
the DS18B20 bindings as well as the calibration offsets; the bindings can only be made at the car;
and the `tar`-over-ssh loop below overwrites everything under `~/KnurLogger`. With one copy, one
sync from the workstation silently discards a trip to the car — which is exactly the trap this
README used to document and ask you to remember your way around.

```bash
ssh KnurLogger 'bash ~/KnurLogger/SystemSetup/deploy-logger.sh --execute'
```

`deploy-logger.sh` **always replaces the binary and only ever creates the `.ini`, never updates
it.** Run it with no arguments first, like every script in `SystemSetup/`. `KnurLogger.service`
points at `/home/chrum/bin/KnurLogger`, not at the build tree.

> **⚠ A BINARY THAT ADDS A REQUIRED KEY CRASH-LOOPS THE PRODUCTION LOGGER.** `config.cxx` exits on
> any missing key, the deploy never touches `~/bin/KnurLogger.ini`, and the service restarts every
> 5 s forever (`Restart=always`). Before deploying a build that adds a key, hand-merge it into
> `~/bin/KnurLogger.ini` — the pre-flight's diff of the two files shows what is missing — then
> deploy and check `systemctl status KnurLogger`.

> **⚠ The production `.ini` is not in git, so nothing else backs up a calibration or a binding.**
> After enrolling or entering offsets at the car, copy `~/bin/KnurLogger.ini` into the repo as
> `build/KnurLogger.ini` and commit it. That is a deliberate act rather than a side effect, which
> is the point — but it is also the only thing standing between a wiped SD card and another trip:
>
> ```bash
> scp KnurLogger:bin/KnurLogger.ini build/KnurLogger.ini
> ```

**The box is fed from constant 12 V, not the accessory circuit** (as built, 2026-09-10), so the
logger runs the whole day and the fuse is the off switch. Two consequences worth having here:
`SystemSetup/KnurLogger.service` is **required** rather than convenient, because nothing
hand-starts the logger when the fuse goes in; and the hard cut the ~1 s `fsync` protects against
is now the fuse being pulled, or a cranking dip, rather than ignition-off. The operating rules below cover constant-feed power and shutdown.

**Do not put push credentials on the box.** Commit and push from the workstation; the box pulls
only. A logger in a wheel-well cavity is physically exposed — if the car is broken into or the SD
card is pulled, any PAT or writable deploy key on it becomes an attacker's write access to this
repo. A public repo needs no credential to clone or pull, so read-only costs nothing.

For a tight edit-build loop, round-tripping through GitHub is slow; copy the tree to the box
instead and keep GitHub for durable commits. The loop in use is:

```bash
tar czf - --exclude=.git --exclude=build/CMakeCache.txt --exclude=build/CMakeFiles . | ssh KnurLogger 'tar xzf - -C ~/KnurLogger && cd ~/KnurLogger && cmake --build build -j4'
```

**That sync overwrites `~/KnurLogger/build/KnurLogger.ini`, and that is now harmless** — it is the
template, and the running logger does not read it. Nothing under `~/bin/` is touched until
`deploy-logger.sh` is run, and even then only the binary. This is what the dev/production split
above bought; before it, one sync destroyed a hand-entered offset silently.

**The `../ndLouvers/...` links throughout this repository are broken on github.com and that is
deliberate.** `ndLouvers` is a separate repository that happens to sit alongside this one on disk.
The links resolve locally, which is where the work happens. Do not "fix" them by copying
requirements across — a duplicated requirement is one that will drift, and `CLAUDE.md` says so.

## Getting on the box

SSH alias `KnurLogger` (`192.168.118.52`, user `chrum`), key-only.

```bash
ssh KnurLogger
```

## Enrolling the four DS18B20s

`temp0`–`temp3` mean nothing until a ROM ID is bound to each. Binding is a deliberate mode and
never happens during a logging run, so a probe that drops out and comes back mid-session cannot
re-label a channel.

**Stop the service first — it is installed and enabled, so the logger is always already running:**

```bash
ssh -t KnurLogger 'sudo systemctl stop KnurLogger'
```

Two instances both poll the bus and both advertise, and nothing warns. See Operating constraints below.

```bash
ssh KnurLogger '~/bin/KnurLogger --enroll'
```

1. Start with **no probe connected**, then plug them in **one at a time, lowest channel first** —
   the installed order the plan fixes is `temp0` = `T_ambient`, `temp1` = `T_core_in`,
   `temp2` = `T_core_out`, `temp3` = `T_aft`.
2. **Every probe stays plugged in once it is in. Do not unplug one to make room for the next.**
   Binding works either way, which is what makes this easy to get wrong — it was got wrong at the
   car on 2026-09-10 — but unplugging as you go costs three things that binding does not:
   1. **The four-probe star is never loaded**, so the run proves nothing the ESP32 bench rig had
      not already proved with single probes. All four together on the 4 × 5 m bus, enumerating
      with CRC-clean reads, is the acceptance criterion of plan thermal item 1 (closed, rev 77),
      and it is only met with all four connected at once.
   2. **Step 6's map check becomes impossible**, because warming one probe and watching one
      channel move needs four live channels.
   3. **Every unplug leaves a ~100 s tail** of a channel that is present in sysfs and answering
      with nothing — see `one-wire-probes.md` on `w1_slave_ttl`.
3. **Allow ~10 s per probe.** `w1_master_timeout` is 10 s, so that is the hot-plug latency; nothing
   can shorten it without root.
4. Each bind prints `OneWire: BOUND temp0 <- 28-…, reading 21.50 C` and writes an `enrollment`
   record. Check the ROM ID against the lead you just connected. **A bind whose reading comes back
   `INVALID` is a warning, not a failure** — the binding is still written, but the probe answered
   badly on the very read that is meant to confirm it, so re-seat that lead and watch the channel
   before trusting it.
5. **Two unbound probes in one scan are refused, not guessed.** sysfs order is not arrival order,
   so there is no fact available that says which came first. Unplug one and re-seat it alone.
6. **Enrollment keeps sampling after the fourth bind.** With all four bound, warm one probe by hand
   and watch one channel move on the phone — four warmings confirm the whole map in situ and double
   as a liveness test. Stop it with `pkill -TERM -x KnurLogger`.
7. `--enroll --reset` discards every binding and starts from `temp0`. The bindings it throws away
   are written into the session file first, because they are otherwise unrecoverable.

The bindings are written into the `[thermal]` section of the **`KnurLogger.ini` beside the
binary**, alongside the calibration offsets, as `temp<N>RomId` / `temp<N>BoundTaiUs` /
`temp<N>BoundIso` (owner decision, 2026-09-10 — this replaced a separate `channels.ini` in the data
directory; see `CLAUDE.history.md` §2.7 and do not rebuild that file). An empty `temp<N>RomId` is
an unbound channel and a perfectly good state. Three consequences:

1. **Enrollment rewrites a file you hand-maintain**, so it does it line by line: only the twelve
   binding lines are touched and every other byte, comments included, is copied through. It is not
   written through GLib's key-file serialiser, which destroys non-ASCII characters in comments —
   measured 2026-09-10, this file's em-dashes came back as `?`.
2. **The offsets are now in front of you when you change a binding**, which is the point: an offset
   is keyed to the slot, so re-enrolling in a different order strands it. See
   §[Calibration offsets](#calibration-offsets).
3. **This is the file `SystemSetup/deploy-logger.sh` refuses to overwrite.** The production copy is
   `~/bin/KnurLogger.ini` and the git-tracked template is `build/KnurLogger.ini`; see
   §[Repository, deployment and where the code is built](#repository-deployment-and-where-the-code-is-built).

**Editing a ROM ID by hand is allowed and guarded.** Anything that is not a 15-character `28-…` is
refused and logged as an event, and one ROM ID appearing on two channels is refused on the second
— a duplicate would otherwise produce two channels tracking each other perfectly, which is a
mislabelling that looks like agreement.

`SystemSetup/logger-perfboard-wiring.md` §5a is the human record of the resulting table, and it is
**filled** as of 2026-09-10. **Channel → role is a per-session record, never a channel name** — it
is in every session file's `thermalBaseline`, which is where an analysis should take it from.

## Calibration offsets

Hand-edited in `KnurLogger.ini`, one per channel, applied to the value sent to RaceChrono:

```ini
[thermal]
temp0OffsetC=0.0
temp1OffsetC=-0.375
temp2OffsetC=0.0
temp3OffsetC=0.0
```

**How to get the numbers.** Park the car long enough to reach equilibrium — engine cold, no sun, no
residual heat — and run one stationary logging session. At equilibrium all four probes sit in the
same air, so their differences are sensor error and nothing else: read the four values out of the
session file's 1 Hz `temp` records and enter each probe's deviation from the four-probe mean. Only
*relative* offsets mean anything, because there is no reference thermometer on the car and
ΔT_preheat depends on the probes' differences rather than their absolute accuracy. **Entering
nothing is a legitimate outcome** if the differences are small against a ~6 K signal.

Five things to know:

1. **They are keyed to the channel slot, not to the probe.** An offset is really a property of one
   particular DS18B20, so if the probes are ever re-enrolled in a different order, or one is
   swapped, the offsets stay with the slots and no longer describe the parts in them — **re-check
   them after any re-enrollment.** In exchange they live in the config beside every other setting,
   including the bindings that say which probe each slot holds.
2. **The session file records all three values** — `centiC` (raw), `offsetC` (in force) and
   `sentCentiC` (what went on the air) — so a mistyped offset costs a reprocess, not the session.
3. **All four keys must be present.** A missing one is a startup failure, not a silent zero: an
   offset that quietly stopped being applied would be invisible in the data it corrupts.
4. **Past ±5 °C it warns** about a likely decimal-point slip and applies the value anyway; **past
   ±50 °C it refuses to start.** The offsets in force are printed at startup and recorded in the
   `thermalBaseline` record.
5. **The ROM ID → channel bindings are in this same section**, as `temp<N>RomId`, machine-written
   by `--enroll` (2026-09-10). That is deliberate rather than incidental: item 1's consequence —
   an offset keyed to a slot stops describing the part in it after a re-enrollment — is only
   noticeable if the two are read together. A changed `temp2RomId` is the signal to re-check
   `temp2OffsetC` three lines above it.

**The logger takes no automatic session-start sample and makes no judgement about whether the car
was settled** — see `CLAUDE.history.md` §3.1 for why that was tried, measured failing, and
dropped.

## Pressure correction settings

Hand-edited in the `[pressure]` section of `KnurLogger.ini`; `pressure-correction.md` owns what they
mean and how they combine. A missing or out-of-range key for an **enabled** channel is a startup
failure, and the template's header lists the bounds.

1. `tubingResistancePerMetre` and `lineFixedResistance` are global, and `p<N>SpanPositive`,
   `p<N>SpanNegative`, `p<N>BypassCoefficient` and `p<N>BypassExponent` are per slot. Their values
   come from the bench: `../ndLouvers/pressure-testing.md` §3.3a and §3.3b. Like the thermal
   offsets they are keyed to the slot, so **re-check them after moving a sensor.**
2. `p<N>LineLengthHighM` and `p<N>LineLengthLowM` are the route lengths in metres, 0 for a port
   open to the bay. **They stay 0 until the lines are cut on the car**, then are entered from the
   measured routes (plan step 8).
3. After editing, restart the service, check that the new session's `pressureBaseline.correction`
   shows the values, and back the file up into `build/KnurLogger.ini` as above.

## Testing the 1-Wire path without probes

The probes are on the car and the phantom `00-*` devices stopped once `R11` terminated the line, so
neither a real reading nor the family filter can be exercised on this box. The whole path is
nonetheless testable, because the code reads sysfs and sysfs can be replaced:

```bash
unshare -Urm --map-root-user /bin/bash -c 'mount --bind /tmp/fake-w1 /sys/bus/w1/devices && ...'
```

An unprivileged user namespace gives a private mount namespace, so a fake tree can be bind-mounted
over `/sys/bus/w1/devices` with **no root and no risk to the real box**. Populate it with a
`w1_bus_master1/` directory, `28-…/w1_slave` files carrying the kernel's two-line format, and a
`00-…` entry to prove the filter drops it. This is how enrollment, the ambiguous-step refusal, the
store's own family and duplicate guards, bound-but-absent, CRC failure,
out-of-range rejection and the application of a hand-entered offset were all verified.

**Its one limitation, found the hard way:** a plain file cannot represent a sysfs attribute whose
read value differs from what was written, and `therm_bulk_read` is exactly that — you write
`trigger` and read back `-1`, `0` or `1`. In the fake tree it reads back `trigger`, so that state
machine is unexercised. Two things fill the gap and are worth reaching for before concluding
something is untestable:

1. **A FIFO in place of `w1_slave`** makes a read block for a controlled time, which is how the
   `conversionMs` fallback was verified — a read forced to 385 ms produced `conversionMs 385`
   where the old code produced 0.
2. **`w1_master_add`** attaches a real family-0x28 slave with no hardware present, so `w1_therm`
   binds and its master attributes appear. This is how the udev rule was verified. It needs root,
   `w1_master_remove` undoes it, and the id is parsed as `%02x-%012llx` — the hyphen matters.

## Session files are the only copy until you take one

`filesDir` on the box is the sole home of every session until it is copied off. The workstation
backup lives at `C:\_claude\KnurLoggerData\sessions\` — **deliberately outside both git
repositories, because this one is public and session files are data.** It is **current as of
2026-09-21**: 73 files, including the 324 MB two-day track file. **The 2026-09-22 ladder sessions
are not yet copied** and exist only on the card.

```bash
scp -r KnurLogger:KnurLoggerData/sessions/*.ndjson /c/_claude/KnurLoggerData/sessions/
```

**Three things to know before reading one.** A session filename is stamped from the box's wall
clock, which in the car is hours wrong — see `session-records.md`. And
`taiUs` can jump mid-file when `timesyncd` corrects the clock; `bootUs` and `sessionUs` are the
axes that survive it. And **copy a session only once the logger has stopped writing it** — a
mid-write copy is a truncated file that parses perfectly and says the session ended early. One
lived in the backup that way until it was replaced; `systemctl is-active KnurLogger` is the check.

## Operating constraints

1. The logger is fed from constant 12 V. It remains powered through engine-off periods and
   cranking. `KnurLogger.service` must start it unattended; remove power at the end of use.
   Prefer `sudo poweroff` before pulling the fuse to avoid repeated abrupt SD-card shutdowns.
2. Do not treat battery-draw estimates as measurements. No draw measurement is scheduled;
   leaving the fuse fitted for an extended parking period can flatten the battery.
3. Before running the binary manually, run `sudo systemctl stop KnurLogger`. There is no
   single-instance guard: concurrent instances can both advertise and poll the probe bus,
   corrupting timing observations and making the phone's selected instance ambiguous.
4. Restart log mode after enrollment; bindings are loaded at worker start and are not re-read.
   Session names include the mode, and binding writes use temp-file, rename and directory fsync.
5. Build-tree and production configurations are separate, as described above. Never point the
   service or another production launcher at the build tree. Back up the production configuration
   after enrollment or calibration, and merge required new keys before deploying new code.
6. The car has no internet. A preconfigured phone hotspot can provide local Wi-Fi and SSH.
   Prepare its NetworkManager profile before the trip; do not commit the PSK. Enrollment and
   logging must also operate unattended after power-on, with BLE providing phone-visible feedback.
7. Bluetooth stays enabled. Wi-Fi gating is manual, only when diagnosing BLE link problems:
   use `nmcli radio wifi off` or `rfkill block wifi`, never `rfkill block all` or a permanent
   `disable-wifi` overlay. Restore Wi-Fi after diagnosis to collect artifacts.
8. Keep `wpa_supplicant.service`: NetworkManager drives it over D-Bus. Disabling it can lose the
   only access path. Host services, module setup and tool paths belong to
   [SystemSetup/pi-headless-setup.md](SystemSetup/pi-headless-setup.md).
9. Run SystemSetup scripts in pre-flight mode before `--execute`. Mutations require a terminal
   for sudo. Do not run `ssh-harden.sh` under sudo; it must read the login user's authorized keys.
10. `harden-headless.sh` masks retired units so package upgrades cannot silently re-enable them.
    Roll back using `sudo systemctl unmask <unit>`. For units without `[Install]`, issue disable,
    stop and mask separately: `disable --now` can refuse before stopping anything.
11. Session filenames and wall clocks can be wrong offline. Follow [session-records.md](session-records.md)
    for time alignment and validity; record the physical mounting state separately for each run.
12. CAN ambient and fan state arrive through box 1 and RaceChrono, not this logger's SD card.
    Define the phone channels before recording. A BLE gap can lose the alignment needed to interpret
    box-2 data against those inputs; local logging does not reconstruct an undefined CAN channel.

Electrical qualification is retired by owner decision; do not rebuild it from the old bring-up
checklist. The fuse remains fitted, harness routing and logged supply telemetry remain required.
See [ndLouvers risk 14](../ndLouvers/risk-register.md) and plan history rev 105.

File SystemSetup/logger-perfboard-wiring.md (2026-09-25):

# Step 0b logger — perfboard wiring

**Companion to [ndLouvers instrumentation-spec.md](../../ndLouvers/instrumentation-spec.md) Step 0b.**
The specification owns the requirements; this file is the build sheet for the box-2 perfboard, as
built, and the rules for reworking it. Where the two disagree, **the specification wins** — bring
the disagreement back there rather than resolving it at the bench. The dated bring-up record is in
[CLAUDE.history.md](../CLAUDE.history.md) (2026-09-24, build sheet entry).

**As built.** The power zone is an **HW-384 buck module** (`U1`, USB-A port removed, pins fitted)
with a 100 µF output electrolytic (`C12`); it powers the Pi through a USB-C pigtail (`J1`). **`F1`
is fitted at the car's fuse box**, so the whole feed run is fused. **`TVS1`/`C1` are not fitted**:
the input has no load-dump clamp, and that exposure is accepted
([ndLouvers risk 14](../../ndLouvers/risk-register.md)). The supply was never measured; the Pi's
logged supply telemetry is the only rail evidence. The sensor zone carries the PCA9548A mux, the
BME280, pull-ups for channels 0–4, and **five SDP810s soldered directly to the board** (§5 has
each product number, serial and scale factor as read back). The four DS18B20s are installed on the
car and enrolled (§5a). Figures marked *(verify)* are from datasheets or general practice.

**Channel 5 is empty and its `R13`/`R14` are footprints only — never address it** (§5; it hangs
the whole bus).

**Retired — do not rebuild.** The HW-384's onboard reverse-polarity protection, 1.5 A input fuse
and 300 W output TVS retire `RP1`, `D2`, `F2`, `L1`, `C2`, `C3` and `C4`; its fixed output retires
the trim-pot procedure. The electrical qualification programme (§7 check 2, §10 steps 2, 3, 5
and 6) is closed unperformed by owner decision — risk 14 owns it.

---

## 1. Why the mux exists — read this before laying anything out

**All five SDP810s share one fixed I2C address.** SDP800/SDP810 parts answer at `0x25`
(SDP801/SDP811 at `0x26`); boot identification reads product/revision/serial and confirms it.
They are not strappable. Five identical addresses on one bus is an unresolvable collision, and
**that is the entire reason the mux is in the parts list.**

Two consequences that drive the whole layout:

1. **Exactly one SDP810 per mux channel.** Never two, whatever the channel count suggests.
2. **The mux does not pass pull-ups downstream.** Each channel is an electrically separate
   I2C segment. Every populated channel needs **its own SDA/SCL pull-up pair**. This is the most
   commonly missed part of a mux build and it fails in a confusing way — the bus works with one
   channel open and misbehaves as you switch.

**The BME280 does not go through the mux.** It has a unique address, so it hangs directly on the
Pi's main bus and saves a channel. It answers at `0x77` (§2 note 1), so **`0x77` is not free:
never strap a mux upward on this board.** The mux's `A0`/`A1`/`A2` are grounded and it sits at
`0x70` alone.

---

## 2. Address map

| Device | Address | Bus | Note |
|---|---|---|---|
| PCA9548A mux (note 4) | `0x70` | Pi main I2C1 | A0/A1/A2 grounded on the built board. Leave them low. |
| BME280 | **`0x77`** | Pi main I2C1 | `SDO` is not held at `GND_SIG`; the breakout's own pull-up sets the address. Note 1. |
| SDP810 ×5 | `0x25` each | One per mux channel | Identical by design; isolated by the mux |
| DS18B20 ×4 | 64-bit ROM ID | 1-Wire, GPIO4 | Addressed by ROM ID, not I2C. ROM ID → `temp0`–`temp3` fixed at enrollment (§5a); channel → role is a per-session record. |

`i2cdetect -y 1` on a healthy board returns **`0x70` and `0x77`**. Use bus 1 only —
`/dev/i2c-20` and `/dev/i2c-21` are the VC4 display DDC buses.

1. **The BME280 is at `0x77`, and that is the specified address** (owner decision). Chip-ID
   register `0xD0` reads `0x60`, the BME280 signature (`0x58` would be a BMP280). The breakout's
   onboard pull-up wins against the `SDO` tie that net list row 9 once specified; the owner
   amended the document rather than the board. No collision results while the mux stays at
   `0x70`.
2. **`~RESET` goes to physical header pin 11 (GPIO17, net list row 12).** Its neighbour, pin 9,
   is a `GND_SIG` pin: a one-position slip holds the mux in reset, and a PCA9548A in reset goes
   completely silent, which reads exactly like an absent or dead part. The Pi side is correct when
   `gpio=17=op,dh` is in `/boot/firmware/config.txt` and `pinctrl get 17` reads `op … hi`; GPIO17
   only goes high after the firmware reads `config.txt`, so a reading with the Pi off or mid-boot
   is legitimately low. **Of §3a.7's three `MUX_RST` rows, `RST` ↔ `+3V3` passes on this fault**
   (it measures `R12` regardless), so never clear the net on that row alone.
3. **THE FIRST TRANSFER AFTER AN IDLE BUS IS REFUSED — ON SOME BOOTS — AND THE CAUSE IS
   UNQUALIFIED.** After an idle gap of about 10 ms or more the first `I2C_RDWR` fails with
   `EREMOTEIO` and a retry 500 µs later succeeds. **The behaviour is latched at initialisation and
   is either on or off for the life of a boot**, so a clean run proves nothing about the board,
   and any diagnosis must record which mode the boot was in (`i2cFirstAttemptFailures`, see
   [session-records.md](../session-records.md)). **`i2cdetect` and a shell loop of `i2ctransfer`
   do not show it**, because they stay inside the warm window: a clean scan beside a program
   that fails every cycle is not a contradiction. `i2ctransfer -y 1 w1@0x77 0xd0 r1`, run several
   times with pauses, is the check.
   `SDA_MAIN` and `SCL_MAIN` carry **no added pull-up** (rows 10 and 11); a rise-time or
   level-shifter explanation is plausible and unmeasured — **measure it before adding a
   resistor** ([ndLouvers open item 44](../../ndLouvers/work-progress.md#item-44)). `i2cBus.cxx`
   works around it with a counted ten-attempt retry, which is not the answer to the physical
   question. The SDP810s meet the same behaviour through the mux, and **a single failed transfer
   on this board is never evidence of an absent part.**
4. **The part is a PCA9548A, not the TCA9548A the parts list names.** They are functional
   equivalents for everything this build uses: pinout, `0x70`–`0x77` address range, single-byte
   channel register, **active-LOW** `~RESET` needing a pull-up to `+3V3`, and 3.3 V supply.
   Recorded so a reader searching the board for "TCA9548A" does not conclude the wrong part was
   fitted.

---

## 3. Block diagram

This is the shape of the thing. **§3a is the wiring** — pin-level diagrams, the authoritative
net list and the pre-power checks — and §4 is a subset of it for the Pi header alone.

```mermaid
graph TD
    subgraph PWR["Power — keep physically separate, item 5.5"]
        V12["12 V CONSTANT, not accessory<br/>via existing grommet, item 1e"]
        FUSE["F1 fuse at source<br/>FITTED - car fuse box"]
        PROT["TVS1 24-26 V<br/>NOT FITTED - owner decision"]
        BUCK["U1 HW-384 buck - BUILT<br/>fixed 4.8-5.2 V, nothing to set<br/>onboard rev-pol + 1.5 A fuse + out TVS"]
        CAP["C12 100 uF output - BUILT"]
        V12 --> FUSE --> PROT --> BUCK --> CAP
    end

    CAP -->|"5 V, USB-C pigtail<br/>NOT the GPIO 5 V pins"| PI["Raspberry Pi 4B"]

    PI -->|"3.3 V pin 1"| RAIL["3.3 V sensor rail<br/>10 uF bulk + 100 nF per device"]
    PI -->|"SDA1 pin 3 / SCL1 pin 5"| MAIN["Main I2C1<br/>Pi internal 1.8k pull-ups"]
    PI -->|"GPIO17 pin 11"| RST["mux ~RESET"]
    PI -->|"GPIO4 pin 7"| OW["1-Wire bus<br/>2.2k pull-up to 3.3 V"]

    MAIN --> BME["BME280 @ 0x77<br/>cavity temp + RH + baro"]
    MAIN --> MUX["PCA9548A @ 0x70"]
    RST --> MUX

    MUX -->|"ch0 + own pull-ups"| P0["SDP810 P0 +/-500 Pa"]
    MUX -->|"ch1 + own pull-ups"| P1["SDP810 P1 +/-500 Pa"]
    MUX -->|"ch2 + own pull-ups"| P2["SDP810 P2 +/-125 Pa"]
    MUX -->|"ch3 + own pull-ups"| P3["SDP810 P3 +/-500 Pa"]
    MUX -->|"ch4 + own pull-ups"| P4["SDP810 P4 +/-500 Pa"]

    OW --> D1["DS18B20 temp0"]
    OW --> D2["DS18B20 temp1"]
    OW --> D3["DS18B20 temp2"]
    OW --> D4["DS18B20 temp3"]
```

---

## 3a. Detailed wiring diagram

**The net list in §3a.4 is the authority, and it is the only one.** The Mermaid diagrams below
and §4's header table are views of it. Where a picture and the net list disagree, the net list is
right and the picture is a bug — fix it. Designators (`F1`, `U1`, `R7` …) are used here, on the
board and on the enclosure label, so a fault can be named the same way in all three places.

**This section asserts topology, not part numbers.** Every value is *(verify)* against the parts
actually in hand.

**There is no CAD schematic, by decision.** Do not recreate one without deciding first which copy
is authoritative — a second hand-maintained net list buys drift and nothing else (history).

### 3a.1 Designators

| Ref | Part | Zone |
|---|---|---|
| `J2` | 12 V input, 2-pin polarised, from the cabin feed (item 1e) | Power |
| `F1` | Fuse + holder **at the source end**, sized to the feed — **fitted at the car's fuse box** (item 5.2). The module's onboard fuse protects nothing upstream of itself, which is why this one exists | Power (car fuse box) |
| `RP1` | **Retired** — reverse-polarity protection is onboard `U1` | — |
| `TVS1` | Transient clamp, ~24–26 V standoff — **not fitted, owner decision** (§3a.5 item 8) | Power |
| `C1` | Input bulk electrolytic, ≥35 V rated — **not fitted**, pairs with `TVS1` | Power |
| `C2` | **Retired** — `U1` carries its own input decoupling | — |
| `U1` | **HW-384 buck module.** USB-A port removed, pins soldered in. Fixed 4.8–5.2 V ±0.5 %, 6–24 V in, 3 A max, 500 kHz. Onboard: reverse-polarity, 1.5 A input fuse, 300 W output TVS, output short-circuit protection | Power |
| `F2` | **Retired** — `U1`'s onboard 1.5 A input fuse is the fusible element (§3a.5 item 8) | — |
| `D2` | **Retired** — `U1`'s onboard 300 W output TVS is the clamp (§3a.5 item 8) | — |
| `L1` | **Retired** — `U1` specifies ~10 mV ripple; `C12` provides the bulk | — |
| `C3` | **Retired** — superseded by `C12` | — |
| `C4` | **Retired** — see `C3` | — |
| `C12` | **100 µF output electrolytic** at `U1`'s output; the sole output bulk | Power |
| `J1` | USB-C power pigtail to the Pi — the GPIO 5 V pins are not in the path (§3a.5 item 7, item 5.4) | Power |
| `PI1` | Raspberry Pi 4B — the 40-pin header and the USB-C inlet | — |
| `U2` | **PCA9548A** mux `0x70` (§2 note 4) | Sensor |
| `U3` | BME280 `0x77` | Sensor |
| `U4`–`U7` | SDP810 ±500 Pa, soldered at positions `J7`, `J8`, `J10` and `J11` — channels P0, P1, P3 and P4 | Sensor (soldered to the board) |
| `U8` | SDP810 **±125 Pa**, soldered at position `J9` — channel P2 (§5) | Sensor (soldered to the board) |
| `R1`–`R10` | 4.7 kΩ channel pull-ups, one pair per populated mux channel | Sensor |
| `R11` | 2.2 kΩ 1-Wire pull-up | Sensor |
| `R12` | 10 kΩ mux `~RESET` pull-up | Sensor |
| `R13`/`R14` | 4.7 kΩ pair for channel **P5** — **footprints only, not fitted** (§3a.6) | Sensor |
| `R15` | 2.2 kΩ pull-up for the reserved second 1-Wire bus — **footprint only** | Sensor |
| `C5`–`C11` | 100 nF local decoupling: `U2`, `U3`, `U4`–`U8` | Sensor |
| `C13` | 10 µF rail bulk at the 3.3 V entry | Sensor |
| `J3`–`J6` | 3-pin DS18B20 probe headers, one per probe | Sensor |
| `J7`–`J11` | SDP810 positions P0–P4 — **no header fitted; each sensor is soldered directly to the board** | Sensor |
| `J12` | SDP810 position P5, unpopulated — **no header fitted** | Sensor |
| `TP1`–`TP5` | Test points: `V12_PROT`, `V5_RAW`, `V5_RAW` again (`TP3` — `V5_FILT` is retired, §3a.4 row 7), `+3V3`, `GND` | Both |

`TP1`–`TP3` were for the retired supply qualification (§10 steps 2 and 3) and have no remaining
consumer; they are still where a meter goes if the supply is ever diagnosed.

### 3a.2 Power chain

```mermaid
flowchart LR
    SRC["Constant 12 V, not accessory<br/>as built; cranking dips lower"]
    SRC -->|V12_RAW| F1["F1<br/>external input fuse<br/>at the car fuse box<br/>FITTED"]
    F1 --> JP{{"V12_PROT — TP1"}}
    JP --- TVS1["TVS1<br/>24-26 V standoff<br/>to GND_PWR<br/>NOT FITTED - owner decision"]
    JP --- C1["C1 bulk 35 V<br/>to GND_PWR<br/>optional, not fitted"]
    JP -->|"IN+"| U1["U1 HW-384 - FITTED<br/>fixed 4.8-5.2 V, NOTHING TO SET<br/>onboard: rev-pol, 1.5 A in-fuse,<br/>300 W out-TVS, short-circuit"]
    U1 -->|"OUT+"| JF{{"V5_RAW — TP2 and TP3<br/>one node now"}}
    JF --- C12["C12 100 uF<br/>to GND_PWR<br/>FITTED"]
    JF -->|"J1 USB-C pigtail, VBUS + GND only"| PI["Raspberry Pi 4B<br/>USB-C socket"]
```

**Hexagons are nets, rectangles are parts.** A part drawn hanging off a net by a plain line
(`TVS1`, `C1`, `C12`) sits between that net and `GND_PWR`; only the arrowed
path carries current through to the next stage. `GND_PWR` is the return for everything here,
`J1`'s ground conductor included.

**`TP2` and `TP3` are now the same node, and that node is `V5_RAW`.** With `F2`, `D2` and `L1`
retired there is nothing between the module output and the output bulk, so the old `V5_CLAMP` and
`V5_FILT` nets are gone (§3a.4 rows 6 and 7) and `V5_RAW` runs straight to `J1`. Keep both test
points if the board already has them — they are cheap — but do not expect a difference between
them, and do not read a difference as a fault.

### 3a.3 Signal chain

```mermaid
flowchart LR
    subgraph HDR["Pi 4B 40-pin header"]
        H1["pin 1 — 3V3"]
        H3["pin 3 — GPIO2 / SDA1"]
        H5["pin 5 — GPIO3 / SCL1"]
        H7["pin 7 — GPIO4"]
        H11["pin 11 — GPIO17"]
        H13["pin 13 — GPIO27<br/>RESERVED, unwired"]
        HG["pins 6, 9, 14, 20, 25 — GND"]
    end

    H1 --> RAIL{{"+3V3 rail — TP4<br/>C13 10 uF at entry"}}
    HG --> GNDS{{"GND_SIG — TP5"}}

    H3 --> MB{{"SDA_MAIN / SCL_MAIN<br/>Pi internal 1.8k pull-ups<br/>ADD NONE"}}
    H5 --> MB
    MB --> U3["U3 BME280 0x77<br/>SDO not tied — breakout pull-up wins<br/>CSB high = I2C mode<br/>C6 100 nF"]
    MB --> U2["U2 PCA9548A 0x70<br/>A0/A1/A2 hard-wired to GND_SIG<br/>C5 100 nF"]

    H11 --> RST{{"MUX_RST<br/>R12 10k shunt to +3V3<br/>idles high"}} --> U2

    U2 -->|"SD0 / SC0"| K0{{"SDA_CH0 / SCL_CH0<br/>R1 + R2 shunt 4k7 to +3V3"}} --> U4["J7 position: U4 soldered<br/>SDP810 +/-500 Pa, channel P0<br/>C7"]
    U2 -->|"SD1 / SC1"| K1{{"SDA_CH1 / SCL_CH1<br/>R3 + R4 shunt 4k7 to +3V3"}} --> U5["J8 position: U5 soldered<br/>SDP810 +/-500 Pa, channel P1<br/>C8"]
    U2 -->|"SD2 / SC2"| K2{{"SDA_CH2 / SCL_CH2<br/>R5 + R6 shunt 4k7 to +3V3"}} --> U8["J9 position: U8 soldered<br/>SDP810 +/-125 Pa, channel P2<br/>C9"]
    U2 -->|"SD3 / SC3"| K3{{"SDA_CH3 / SCL_CH3<br/>R7 + R8 shunt 4k7 to +3V3"}} --> U6["J10 position: U6 soldered<br/>SDP810 +/-500 Pa, channel P3<br/>C10"]
    U2 -->|"SD4 / SC4"| K4{{"SDA_CH4 / SCL_CH4<br/>R9 + R10 shunt 4k7 to +3V3"}} --> U7["J11 position: U7 soldered<br/>SDP810 +/-500 Pa, channel P4<br/>C11"]
    U2 -->|"SD5 / SC5"| K5{{"SDA_CH5 / SCL_CH5<br/>R13 + R14 footprints, NOT FITTED"}} --> J12["J12 — channel P5<br/>no header, no sensor"]

    H7 -->|OW_DATA| OW{{"1-Wire node<br/>R11 2k2 to +3V3"}}
    OW --> J3["J3 — DS18B20"]
    OW --> J4["J4 — DS18B20"]
    OW --> J5["J5 — DS18B20"]
    OW --> J6["J6 — DS18B20"]
    H13 -.->|"OW_DATA_B — R15 footprint"| SPLIT["second 1-Wire bus<br/>only if step 10.6 fails"]
```

**Hexagons are nets, rectangles are parts** — the same convention as §3a.2. A pull-up named on a
net hangs from that net to `+3V3`; it is not in series with the bus. `+3V3` and `GND_SIG` are
drawn only as far as their rail nodes, because every device sits on both and net-list rows 8 and
9 say exactly who.

**`J3`–`J6` are four identical positions, not four channels.** A DS18B20's channel is its ROM ID
(§5a); which header a probe is plugged into means nothing and may change. `J7`–`J11` are the
opposite case — those *are* the channels, because a mux port is a physical address.
### 3a.4 Net list — authoritative

Notation is `REF.pin`. A net is complete as listed; anything not listed is not connected.

**The net list names board nodes only.** The four DS18B20s are off-board parts that plug into
`J3`–`J6`; the five SDP810s are soldered directly to the board at positions `J7`–`J11`, with no
header fitted. Either way a sensor's pin appears here as its position's pin,
once — `U4`–`U8` are named in §3a.1 to identify the sensors, not as separately wired nodes.

| # | Net | Nodes | Notes |
|---|---|---|---|
| 1 | `V12_RAW` | `J2.+12V`, `F1.a` | 2-core from the cabin, item 1e. **`F1` is fitted at the car's fuse box**, upstream of this whole run, so everything from the tap onward sits behind it |
| 2 | `V12_FUSED` | **Retired** | `RP1` is onboard `U1`, so no node remains between `F1` and `U1.IN+`. Merged into row 3 |

| 3 | `V12_PROT` | `F1.b`, `TVS1.a`, `C1.+`, `U1.IN+`, `TP1.1` | **`TVS1` and `C1` are not fitted** (§3a.5 item 8). As built this net is `J2.+12V` → `U1.IN+` plus `TP1` |
| 4 | `GND_PWR` | `J2.GND`, `TVS1.k`, `C1.-`, `U1.IN-`, `U1.OUT-`, `C12.-`, `J1.GND` | Power-zone pour |
| 5 | `V5_RAW` | `U1.OUT+`, `C12.+`, `J1.VBUS`, `TP2.1`, `TP3.1` | **The whole output side is one node now.** `U1`'s output is fixed, so there is no pot to set. The meter reading here was retired unperformed (§10 step 2), so this node's voltage is not recorded |
| 6 | `V5_CLAMP` | **Retired** | `F2` and `D2` are onboard `U1` (§3a.5 item 8) |
| 7 | `V5_FILT` | **Retired** | `L1`/`C3`/`C4` retired; merged into row 5, so `TP3` reads the same node as `TP2` |
| 8 | `+3V3` | `PI1.1`, `C13.+`, `C5.1`, `C6.1`, `C7.1`, `C8.1`, `C9.1`, `C10.1`, `C11.1`, `U2.VCC`, `U3.VIN`, `U3.CSB`, `J7.VDD`, `J8.VDD`, `J9.VDD`, `J10.VDD`, `J11.VDD`, `J12.VDD`, `J3.VDD`, `J4.VDD`, `J5.VDD`, `J6.VDD`, `R1.a`, `R2.a`, `R3.a`, `R4.a`, `R5.a`, `R6.a`, `R7.a`, `R8.a`, `R9.a`, `R10.a`, `R11.a`, `R12.a`, `R13.a`, `R14.a`, `R15.a`, `TP4.1` | Sensor rail |
| 9 | `GND_SIG` | `PI1.6`, `PI1.9`, `PI1.14`, `PI1.20`, `PI1.25`, `C13.-`, `C5.2`, `C6.2`, `C7.2`, `C8.2`, `C9.2`, `C10.2`, `C11.2`, `U2.GND`, `U2.A0`, `U2.A1`, `U2.A2`, `U3.GND`, ~~`U3.SDO`~~, `J7.GND`, `J8.GND`, `J9.GND`, `J10.GND`, `J11.GND`, `J12.GND`, `J3.GND`, `J4.GND`, `J5.GND`, `J6.GND`, `TP5.1` | Sensor-zone pour. **`U3.SDO` struck out**: as built the BME280 answers at `0x77`, so `SDO` is not on this net and the owner has accepted the address rather than the tie (§2 note 1). |
| 10 | `SDA_MAIN` | `PI1.3`, `U2.SDA`, `U3.SDA` | No added pull-up |
| 11 | `SCL_MAIN` | `PI1.5`, `U2.SCL`, `U3.SCL` | No added pull-up |
| 12 | `MUX_RST` | `PI1.11`, `U2.~RESET`, `R12.b` | `R12.a` to `+3V3` |
| 13 | `OW_DATA` | `PI1.7`, `R11.b`, `J3.DQ`, `J4.DQ`, `J5.DQ`, `J6.DQ` | `R11.a` to `+3V3`; star, not daisy chain |
| 14 | `SDA_CH0` | `U2.SD0`, `R1.b`, `J7.SDA` | `R1.a` to `+3V3` |
| 15 | `SCL_CH0` | `U2.SC0`, `R2.b`, `J7.SCL` | `R2.a` to `+3V3` |
| 16 | `SDA_CH1` | `U2.SD1`, `R3.b`, `J8.SDA` | |
| 17 | `SCL_CH1` | `U2.SC1`, `R4.b`, `J8.SCL` | |
| 18 | `SDA_CH2` | `U2.SD2`, `R5.b`, `J9.SDA` | |
| 19 | `SCL_CH2` | `U2.SC2`, `R6.b`, `J9.SCL` | |
| 20 | `SDA_CH3` | `U2.SD3`, `R7.b`, `J10.SDA` | |
| 21 | `SCL_CH3` | `U2.SC3`, `R8.b`, `J10.SCL` | |
| 22 | `SDA_CH4` | `U2.SD4`, `R9.b`, `J11.SDA` | Specified as the ±125 Pa position; **as built that part is soldered at `J9`/P2** (§5); the channel copper is as listed |
| 23 | `SCL_CH4` | `U2.SC4`, `R10.b`, `J11.SCL` | |
| 24 | `SDA_CH5` | `U2.SD5`, `J12.SDA`, `R13.b` *(footprint)* | Reserved — §3a.6 |
| 25 | `SCL_CH5` | `U2.SC5`, `J12.SCL`, `R14.b` *(footprint)* | Reserved — §3a.6 |
| 26 | `OW_DATA_B` | `PI1.13`, `R15.b` *(footprint)* | Track to `GPIO27` is laid; `R15` is not fitted. Contingency for step 10.6 |

**`U2.SD6/SC6` and `SD7/SC7` are left open.** Unused mux channels are not a hazard, but do not tie
them anywhere — a grounded channel makes a switching fault look like a bus fault.

**`GND_PWR` and `GND_SIG` are two pours, joined in exactly one place: through `J1`'s ground
conductor, inside the Pi.** Do not add a board-level link between them. That is what keeps the
buck's switching return current out of the copper the I2C and 1-Wire returns use, which is plan
item 5.5's whole concern. There is no floating-rail hazard in this arrangement, because `J1` is
also the Pi's only supply — lose that conductor and the board is dead, not half-powered.

**3.3 V current budget** *(verify against the datasheets once the parts are in hand)*: five
SDP810s at ~6 mA, four DS18B20s at ~1.5 mA active, mux and BME280 under 1 mA each — call it
**~50 mA**, comfortably inside what Pi pin 1 will give. If the measured figure lands far from
this, something is wired wrong; do not simply accept it.

### 3a.5 Device pinouts, and the connectors that will bite

1. **SDP810 pin order is deliberately not asserted here, and the mapping is STILL OWED.** These
   are the most expensive parts on the board and the only ones that cannot be replaced from stock,
   and all five are soldered without the mapping written here. Before any sensor is desoldered or
   replaced, take pin 1 from the datasheet drawing *and* from the pin-1 marker on the parts on the
   board, and write the mapping into this section. The nets they join are fixed (rows 14–23).
2. **BME280 breakout supply.** Some breakouts (`VIN` + onboard regulator + level shifters) expect
   5 V and brown out on 3.3 V; bare `GY-BME280`-style modules take 3.3 V directly. **Establish
   which one is on hand before a replacement goes on the rail** *(verify)*. This board has no 5 V
   anywhere in the sensor zone by design, so a regulator-type breakout must be fed at its 3.3 V
   node, not at `VIN`.
3. **BME280 `CSB` must be high** for I2C mode. Most breakouts tie it up on-board; if this one does
   not, `CSB` goes to `+3V3` (row 8). **`SDO` is not tied on this board** — the breakout's own
   pull-up wins and the part answers at `0x77` (§2 note 1).
4. **DS18B20 cable colours vary by vendor** — red/black/yellow is common, red/green/yellow and
   red/blue/yellow both exist, and a sealed probe cannot be rung out to the TO-92 pins. Reversed
   `VDD`/`GND` destroys the probe. This is why probes go on **one at a time** (§10 step 6): a
   mis-coloured cable then costs one probe instead of four.
5. **Optional 1-Wire series resistors.** If the star ever produces CRC errors rather than outright
   non-enumeration, ~100 Ω in series with each probe's `DQ` at its header usually settles the
   reflections a 4 × 5 m star produces. Not fitted, and not needed on the loaded star as built
   (§5a) — but reach for them *before* splitting the bus to `GPIO27`, since they cost one resistor
   rather than a second bus.
6. **`GPIO17` boots as an input with the SoC's default pull-down (~50 kΩ).** Against `R12` at
   10 kΩ the `~RESET` node idles near 2.7 V — above V_IH, but not by much *(verify at the
   bench)*. `gpio=17=op,dh` drives it high in firmware before the first mux transaction; drop
   `R12` to 4.7 kΩ if the boot-time level ever measures marginal. `GPIO4` has the opposite
   default — an internal pull-up — which is harmless alongside `R11`.
7. **`J1`, the USB-C pigtail, carries `VBUS` and `GND` only.** `CC1`/`CC2` are the pigtail's
   business, not this board's: a dumb 5 V source needs no negotiation for the Pi to accept power.
   With a fixed-output module the pigtail's own drop is the only part of the rail margin left to
   adjust (item 9).
8. **The crowbar is inside `U1`; the remaining gap is on the input side.** A TVS across a supply
   stuck at 12 V conducts until something opens the circuit. The HW-384 supplies both halves: a
   300 W TVS on the 5 V output and a 1.5 A fuse on the input, which is what opens. That the fuse
   sits on the *input* side is fine for this fault — a shorted pass element draws the clearing
   current through it — but its rating is an input-current rating, so do not reason about it as
   though it were in series with the 5 V load.

   **What the module does not provide is input transient protection.** The vendor gives a 24 V
   nominal input ceiling and **no absolute-maximum figure**, and a 12 V system's load dump goes
   above 24 V. `TVS1` (~24–26 V standoff, e.g. SMBJ24A or P6KE24A), optionally with `C1`, is a
   single component across `V12_PROT` and `GND_PWR`. **It will not be fitted** (item 5.1, owner
   decision): the exposure is accepted, and the argument for the part is kept here in case that
   decision is revisited.

   **`F1` is a different argument, and it is satisfied rather than accepted.** Without it the
   whole run from the tap to the wheel-well cavity would be unfused — a **fire risk in a car**,
   not a hardware-loss risk. It is fitted at the car's fuse box (item 5.2). **Do not read the
   retirement of `TVS1` and the supply checks as covering `F1`.**
9. **Wire sizes.** `V12_RAW` from the cabin and the `J1` pigtail carry the whole logger current —
   0.5 mm² / 20 AWG minimum, and the pigtail is the one to be fussy about: a fixed-output module
   cannot be trimmed up, so every millivolt lost in the pigtail comes straight off the margin to
   the Pi's 4.63 V undervoltage flag (item 5.4). Signal nets are unloaded and any wire will do;
   spend the effort on keeping the five channel pairs short instead (§6).

### 3a.6 Channel P5 is wired but not populated

§5 reserves P5 as a sixth position; §6 specifies pull-ups on **five** channels. Both are right,
and this is where they meet: **`J12` is wired in full at build** — `SD5`/`SC5` from the mux,
`+3V3` and `GND_SIG` to its supply pins — and `R13`/`R14` get footprints but **no resistors**.
Fit the pair with the sensor, never before.

Wiring the reserved header's supply pins is the point of reserving it. A `J12` with signal but
no rail would need the board opened again to add two wires, which is exactly the rework the
reserved position exists to avoid. `R15` and the `GPIO27` track are reserved the same way
(row 26): the copper is there, the part is not.

An unpopulated channel carrying pull-ups is electrically harmless — the mux isolates it — but it
makes the §10 step 7 isolation test read as though a channel were present, and that test is the
one diagnostic this whole build depends on.

### 3a.7 Pre-power checks

These are fault-finding and rework checks with the board powered off. They were not run before
first power, so none of them is a record of the board as built.

Power off, nothing connected to `J2`, meter on resistance. In-circuit readings are pulled about by
parallel paths, so treat these as **orders of magnitude, not measurements**. This is a wiring
check only; §7 and §10 own the destroy-hardware checks and the rework order.

**Two rows disagree about whether the Pi is mated, so take them in this order.** Do the
`GND_PWR ↔ GND_SIG` row first with the Pi and the pigtail both **disconnected** — mated, the Pi
joins those two pours legitimately and the check reads as a short whether or not a second tie
exists. Do the `SDA_MAIN ↔ +3V3` row with the header **mated but unpowered**, because the 1.8 kΩ
being looked for lives inside the Pi. Everything else reads on the bare board.

| Between | Expect | What a failure means |
|---|---|---|
| `V12_PROT` ↔ `GND_PWR` | High; drifting up only if `C1` is fitted | `TVS1` backwards (if fitted), or a short under the module |
| `V5_RAW` ↔ `GND_PWR` | High, drifting up as `C12` charges off the meter | `C12` backwards, or a solder bridge under `U1` |
| `+3V3` ↔ `GND_SIG` | > 1 kΩ | A sensor or a decoupling cap is in backwards |
| `+3V3` ↔ `V5_RAW` | Open | The two voltage domains have met. Find it before power |
| `GND_PWR` ↔ `GND_SIG` | **Open on the board** | A second ground tie exists — remove it (§3a.4) |
| `SDA_MAIN` ↔ `+3V3` | ~1.8 kΩ, lower if breakout pull-ups remain | Confirms §6's Pi-side pull-ups and that the breakouts' were dealt with |
| `SDA_CHn` ↔ `+3V3` | ~4.7 kΩ, on each of the five | **The commonest fault in a mux build** — a missing channel pair |
| `SDA_CHn` ↔ `SCL_CHn` | **Open**, on each of the five | The two lines of a channel are shorted together — the fault §5's warning describes |
| `OW_DATA` ↔ `+3V3` | ~2.2 kΩ | `R11` missing or the wrong value |
| `MUX_RST` ↔ `+3V3` | ~10 kΩ | `R12` missing — the mux may boot held in reset. **Not sufficient on its own** — it passes with `~RESET` on ground (§2 note 2) |
| `MUX_RST` ↔ `GND_SIG` | **High** | `~RESET` is shorted to ground; the mux will be held in reset and silent (§2 note 2) |
| `MUX_RST` ↔ `PI1.11` | **Short, a few Ω** | The `MUX_RST` wire is open or on the wrong header pin. Pin 9 is its neighbour and is ground |
| `SDA_CH5` ↔ `+3V3` | **Open** | `R13`/`R14` were fitted early (§3a.6) |

---

## 4. Pi 4B header connections

**The header seen from the Pi's side. §3a.4 is the full net list; this table adds nothing to it
and must not disagree with it.**

| Pi pin | Signal | Goes to |
|---|---|---|
| 1 | 3.3 V | Sensor rail — mux VCC, BME280 VCC, all five SDP810 VDD, all four DS18B20 VDD |
| 3 | GPIO2 / SDA1 | Mux `SDA`, BME280 `SDA` |
| 5 | GPIO3 / SCL1 | Mux `SCL`, BME280 `SCL` |
| 6 | GND | Board ground plane / rail |
| 7 | GPIO4 | 1-Wire data, all four DS18B20 |
| 9 | GND | Second ground tie |
| 11 | GPIO17 | Mux `~RESET` |
| 13 | GPIO27 | **Reserved and unwired** — second 1-Wire bus only if §10 step 6 fails. `R15` footprint, §3a.4 row 26 |
| 14, 20, 25 | GND | Ground ties for the sensor and 1-Wire returns |
| USB-C | 5 V in | From the buck's clamped output. **Not** pins 2/4. |

**Pins 2 and 4 (5 V) stay unconnected.** Commissioning item 5.4: feeding the GPIO 5 V pins
bypasses the Pi's own input protection. A USB-C pigtail is the specified path. A dumb 5 V source
needs no CC negotiation for the Pi to accept power *(verify on your pigtail)*.

---

## 5. Mux channel allocation

**Channel names are positional and carry no test-scenario meaning.** A logger channel is a piece
of hardware — one mux port, one sensor with a serial and a fixed range, two tube tails — so it is
named for where it sits: **P0 … P5**. Which measurement a channel serves is a property of the
*session*, not of the board. The measurement roles move between phases, so a role frozen into a
channel name would leave every later scheme translating through an obsolete one, and would make a
wiring fault and a mapping fault look alike.

**The P→role mapping is not decided here**; ndLouvers `instrumentation-spec.md` Step 0b owns it, and
has fixed it for A1+A2+A3. It is recorded per session and is to be logged at boot alongside the
sensor serials (commissioning item 2, not yet implemented). Reassigning a channel is then a tube move plus one line in the session mapping — never a
relabelled board.

Every product number, serial and scale factor below was read back over I2C, not taken from a
label. Five distinct serials.

| Mux ch | Channel | Sensor fitted | Product / serial, as read | Scale | Tube tails |
|---|---|---|---|---|---|
| SD0/SC0 | **P0** | SDP810 ±500 Pa | `0x03020A01` / `0x000000009B994E22` | 60 | `P0+` / `P0−` |
| SD1/SC1 | **P1** | SDP810 ±500 Pa | `0x03020A01` / `0x000000009B994E19` | 60 | `P1+` / `P1−` |
| SD2/SC2 | **P2** | SDP810 **±125 Pa** | `0x03020B01` / `0x00000000978B88F8` | **240** | `P2+` / `P2−` |
| SD3/SC3 | **P3** | SDP810 ±500 Pa | `0x03020A01` / `0x000000009B994E18` | 60 | `P3+` / `P3−` |
| SD4/SC4 | **P4** | SDP810 ±500 Pa | `0x03020A01` / `0x000000009B994E24` | 60 | `P4+` / `P4−` |
| SD5/SC5 | **P5** | Unpopulated. Reserved position, wired for a sixth sensor. `R13`/`R14` are footprints only. | — | — | — |
| SD6–7 | — | Not used. Leave unpopulated. | | | |

**The ±125 Pa is on P2, and all five sensors are hard-soldered.** The build specified P4; the
board won and the document follows it. Nothing here moves with a plug: moving a sensor means
desoldering it, and the ±125 Pa's two duties are a scheduling constraint rather than a re-plug
(ndLouvers open item 38 stays closed). Anything that says "the ±125 Pa sits at P4" is stale.

**Read the product number, do not trust the bag or the board position.** The ±125 Pa identifies
itself as `0x03020B01` with 240 counts/Pa; `0x03020A01`/60 on the other four confirms none of
them is a mis-picked low-range part. **Retain the returned scale factor per sensor; never
hard-code 60.**

> **⚠ A FAULTY DOWNSTREAM CHANNEL TAKES THE WHOLE MAIN BUS WITH IT, AND IT LOOKS FINE AT IDLE.**
> Opening a bad channel — unpopulated with no pull-up pair, or with `SD<n>` shorted to `SC<n>` —
> makes every subsequent transfer on the **main** bus fail with `ETIMEDOUT`: the mux, the BME280,
> everything. **A `~RESET` pulse on GPIO17 is the recovery** (`pinctrl set 17 op dl`, pause,
> `pinctrl set 17 op dh`), which is what `R12` and net list row 12 are for.
>
> **It is invisible to every cheap check.** `i2cdetect` still lists `0x70` and `0x77`, and
> `pinctrl get 2`/`get 3` show `SDA` and `SCL` **both idle-high** with the bad channel open.
> That combination — clean scan, both lines high, every transfer failing — is the fingerprint of
> a downstream segment shorting the two lines *to each other*: at idle both are pulled up, and the
> fault only appears once `SCL` toggles and drags `SDA` with it. **Check continuity
> `SDA_CH<n>` ↔ `SCL_CH<n>` before suspecting the sensor.**
>
> **Never address a channel whose pull-up pair is not fitted** — today that is channel 5 alone.
> **Isolate channels with a reset between each when probing**, or one bad channel masks every
> channel after it. The pressure worker never sweeps: `selectMuxChannel` refuses any channel
> outside `pressureChannelsEnabled`, and `config.cxx` refuses to start if that list names
> channel 5 ([hardware-interface.md](../hardware-interface.md)). **If `R13`/`R14` are ever
> fitted, this table and that config guard both have to change.**

**Range belongs in this table because it is a hardware fact, not a scenario one.** Exactly one
±125 Pa part exists and it sits at P2. That constrains which roles P2 can serve without
unsoldering, and nothing else — if a later scheme wants the low range at another location, move
the *tubes*, not the sensor.

**`P` means a logger channel and nothing else.** The pitot probes are **T1/T2**; do not
reintroduce `P1`/`P2` as probe names.

Label every sensor **and both of its tube tails** with the channel number and port sign. The
port map is required in each session file, and getting it wrong at the bench is silent. Each
sensor's bench calibration is keyed to the part, so **identify a sensor by the product number and
serial it reads back**, never by its label. The installed check is a ±3 % smoke test only
([ndLouvers pressure §2.4](../../ndLouvers/pressure-testing.md#24-the-calibration-regime)), which
will not necessarily catch a swapped pair.

---

## 5a. Thermal channel allocation

Same rule as §5: **`temp0`–`temp3` are generic channel names and carry no location or scenario
meaning.** The role names — T_ambient, T_core_in, T_core_out, T_aft — are measurement quantities,
not names for these four probes. The thermal role→channel map is decided and applied
([ndLouvers thermals §1.1](../../ndLouvers/thermals-testing.md#11-channels-roles-and-bindings));
the pressure one is still open
([ndLouvers open item 30a](../../ndLouvers/work-progress.md#item-30a)). Either is recorded per
session.

**A thermal channel is defined by its ROM ID, not by a position.** The four DS18B20s share one
1-Wire bus and are addressed by 64-bit ROM ID, so unlike the mux there is no physical slot to
name. The ROM ID → channel assignment is the definition, made once and never changed.

**The logger makes the assignment, not a person.** `KnurLogger --enroll` binds each new `28-*`
ROM ID to the next free channel as the probes are plugged in one at a time, lowest channel
first, and writes `temp<N>RomId` into the `[thermal]` section of the `KnurLogger.ini` beside the
binary. **Every probe stays plugged in once it is in**, or the loaded star is never tested.
[operations.md](../operations.md) is the procedure and [one-wire-probes.md](../one-wire-probes.md)
the requirements. Marking probe bodies is unnecessary: each lead is identified at the logger end,
and warming one probe by hand shows which channel moves.

| Channel | ROM ID | Cable |
|---|---|---|
| `temp0` | `28-06254385da1f` | 5 m |
| `temp1` | `28-0625424044b7` | 5 m |
| `temp2` | `28-062542ac86b6` | 5 m |
| `temp3` | `28-0625424e16c9` | 5 m |

**These four ROM IDs are the channel definitions.** The live copy is `temp0RomId`..`temp3RomId`
in the deployed `KnurLogger.ini`; this table is the human record and that file is what the logger
reads. If they ever disagree, the logger is right about what it is doing and this table is wrong.
An earlier, discarded enrollment attempt differs on the last two probes — do not reconcile
against it (history §1.11).

The loaded 4 × 5 m star reads CRC-clean on the 2.2 kΩ `R11` as built
([ndLouvers thermals §3.3](../../ndLouvers/thermals-testing.md#33-the-loaded-4--5-m-star--passed)),
so §3a.5 item 5's fallbacks are not needed. All four probes are electrically and mechanically
identical, so any channel can serve any role — the constraint that applies to P2's ±125 Pa range
has no thermal equivalent.

---

## 6. Resistors and passives

| Where | Value | Why |
|---|---|---|
| Main I2C1 (SDA/SCL) | **none** | The Pi 4B already has fixed 1.8 kΩ pull-ups on GPIO2/3. Do not add more — they parallel down. Remove any fitted on the mux and BME280 breakouts, or confirm the combination. |
| Each mux channel ×5 — `R1`–`R10` | **4.7 kΩ ×2** to 3.3 V | Mandatory per §1. Short perfboard traces at 100 kHz. |
| 1-Wire data — `R11` | **2.2 kΩ** to 3.3 V | Stronger than the usual 4.7 kΩ: four sensors on ~20 m of cable in a star is a hard case for 1-Wire. |
| Mux `~RESET` — `R12` | 10 kΩ to 3.3 V | Idle high; GPIO17 drives it low to recover a wedged bus. Check the boot-time level: §3a.5 item 6. |
| Every IC — `C5`–`C11` | 100 nF | Local decoupling, at the pins. Seven devices: mux, BME280, five SDP810s. |
| Sensor rail — `C13` | 10 µF | Bulk, at the rail entry. |
| Channel P5 — `R13`/`R14` | 4.7 kΩ ×2 | **Footprints only, not fitted.** Fit with the sixth sensor, never before — §3a.6. |
| Second 1-Wire bus — `R15` | 2.2 kΩ | **Footprint only.** Contingency for §10 step 6. |
| Buck output — `C12` | **100 µF** electrolytic | **Fitted.** The owner's addition at `U1`'s output and the only output bulk, `L1`/`C3`/`C4` having been retired with the HW-384 (§3a.1). |

**Power-zone passives that no longer exist:** `C2` (input HF — onboard `U1`), `C3`/`C4` (output
filter — superseded by `C12`). `C1` remains specified but unfitted, as the optional partner to
`TVS1`. Do not re-add the retired parts from an older revision of this sheet.

**Run the I2C bus at 100 kHz.** Three reasons, and the throughput one is the weakest. The whole
rig samples at 10 Hz across five sensors — a few hundred bytes per second — so there is no
throughput argument for 400 kHz either way; and the slower edges are better behaved next to a
switching regulator. **The binding reason is rise time.** Each mux channel carries its own
4.7 kΩ pull-ups above, and t_rise ≈ 0.85·R·C against fast mode's 300 ns limit leaves only about
**75 pF** of segment capacitance — which a breakout plus its wiring can spend. Standard mode
allows 1000 ns, so the same pull-ups get about **250 pF**. Raising the speed therefore requires
either a measurement of the actual segment capacitance or lower pull-ups, and a change here
first; it is not a setting to try casually during bring-up.

---

## 7. Two ways to destroy hardware

1. **DS18B20 supply voltage — applies to every probe fitting.** These parts accept 3.0–5.5 V, and
   the 1-Wire data line idles at whatever rail the pull-up goes to. **Supply them from 3.3 V and
   pull up to 3.3 V.** Powered at 5 V, the data line presents 5 V to GPIO4, which is not 5 V
   tolerant. This kills the Pi.
2. **The supply into a dummy load — retired unperformed, do not schedule** (risk 14). It was to
   confirm the re-pinned module's output and record the margin against the Pi's ~4.63 V
   undervoltage flag, which a fixed-output module cannot be trimmed to recover. That margin is an
   accepted unknown; the logger's supply telemetry (§10 step 4) is the only rail evidence.

Never use parasitic-power mode for the DS18B20s: the arrangement is *powered* 1-Wire, three wires
per probe, not two.

---

## 8. Physical layout on the board

Three zones, driven by items 5.5 and 1b:

1. **Power zone** — `J2`, the fused feed cable from `F1` at the car's fuse box, `U1` and `C12`.
   `TVS1`/`C1` are not fitted and will not be.
   Put this at one end with its own ground pour, `GND_PWR`. **That pour's only tie to the sensor
   side is `J1`'s ground conductor, through the Pi** (§3a.4) — do not add a board-level link
   between the two pours. Item 5.4: the victims of buck noise are the I2C bus and the 1-Wire
   runs, not the radio.
2. **Sensor zone** — mux, BME280, the five SDP810s (soldered directly, no headers), all pull-ups,
   on the `GND_SIG` pour.
   As far from the power zone as the board allows.
3. **Antenna keep-out** — item 1b. The Pi 4B's PCB antenna is at the microSD/USB-C corner
   *(confirm on the board)*. Nothing metallic within 15–20 mm of it: no buck, no bulk caps, no
   mounting standoff, no cable bundle crossing over it. Orient the finished assembly so this
   corner faces the cavity's largest opening.

Keep the SDP810s grouped and their pneumatic tails exiting the same edge of the board — the
enclosure gland positions and the drainage requirement in item 1a both depend on where those
tails leave. **The sensors must sit above their traps** (item 1a): decide the board's mounting
orientation in the cavity *before* fixing tail positions, not after.

---

## 9. Bill of materials

**Fitted.** Power zone: `U1` HW-384 buck module, `C12` 100 µF output electrolytic, `J1` USB-C
pigtail, and `F1` at the car's fuse box. Sensor zone: PCA9548A mux, BME280, `R1`–`R12`,
`C5`–`C11`, `C13`, `J3`–`J6`, and the five SDP810s (4 × ±500 Pa, 1 × ±125 Pa) soldered at
`J7`–`J11` with no headers. The Pi 4B runs on it and the four DS18B20s are enrolled.

**On hand, unused:** an MP1584 module, superseded by the HW-384 — a spare.

**Retired — do not buy.** The HW-384 carries these onboard (§3a.5 item 8): `RP1`
reverse-polarity, `D2` output clamp, `F2` clamp fuse, `L1`/`C3` output filter, `C2`/`C4` HF
decoupling. `TVS1` and `C1` are retired unfitted by owner decision (risk 14); the argument for
them is kept in §3a.5 item 8.

**The ±125 Pa was once required to be connectorised** so it could move between duties without
desoldering. That requirement is retired unmet (ndLouvers open item 38 stays closed): it is fixed
to `P2`, so record per session which duty it was on.

**Contingency stock** — nothing else is outstanding:

| Item | Ref | For | Status |
|---|---|---|---|
| Spare resistors: 2 × 4.7 kΩ, 1 × 2.2 kΩ, 4 × ~100 Ω | `R13`–`R15`, 1-Wire series | §3a.5 items 5 and 6, §3a.6 | Not fitted; the 1-Wire series resistors are not needed (§5a) |
| Test-point pins or pads, 5 | `TP1`–`TP5` | §3a.7 | No consumer since §10 steps 2–3 were retired |

---

## 10. Build and bring-up order

The order below is how the board was built and the order any rebuild or major rework follows:
the supply alone first, the expensive parts last, because risk 14 is a single-supply-kills-
everything risk. **Steps 2, 3, 5 and 6's checks are closed unperformed by owner decision** — do
not schedule them. The narrative of how each step was executed is in history.

| Step | What | State |
|---|---|---|
| 1 | Build the power zone: `U1`, `C12`; `F1` at the car's fuse box | Done. `TVS1`/`C1` will not be fitted |
| 2 | Measure the output into a dummy load at `TP2` (§7 check 2) | **Closed unperformed** — the rail margin is unknown |
| 3 | Transient-check the supply before it sees the Pi | **Closed unperformed** — no cranking or load-dump check exists |
| 4 | Add the Pi alone through `J1`; read `vcgencmd get_throttled` (`0x0` clean; bit 0 undervoltage now, bit 16 it has occurred) | Done. A power-on undervoltage latch on roughly 2 boots in 10 is on record (ndLouvers item 48). Under load this is the logger's supply telemetry (item 5.7). If undervoltage ever flags *during* a run, the fix is the pigtail and connectors, not the module |
| 5 | Build the sensor zone, run §3a.7, add the mux and BME280 | Built; both answer. Its bring-up checks closed unperformed |
| 6 | Add the four DS18B20s, one at a time | Done; the loaded star reads CRC-clean (§5a). Its remaining checks closed unperformed |
| 7 | Add one SDP810 as P0; confirm it appears only when channel 0 is selected | Done in substance — this is the test that proves mux isolation |
| 8 | Add the remaining four one at a time, re-testing isolation after each | Done in substance — all five read correctly; whether steps 7–8 ran exactly as written is not recorded |
| 9 | Assign every DS18B20 ROM ID to `temp0`–`temp3` | Done by enrollment (§5a) |
| 10 | Commission against the specification | Commissioning is an ndLouvers activity with acceptance criteria this file does not restate |

**Rules for any rework or replacement:**

1. **Host precondition.** `/dev/i2c-1` needs *both* `dtparam=i2c_arm=on` and the `i2c-dev`
   module; `SystemSetup/harden-headless.sh` sets both plus §6's 100 kHz. With them in place, an
   `i2cdetect` *no such device* is the host, and anything else is this board.
2. **Repeat every I2C read several times before concluding anything** (§2 note 3). A mux channel
   switch followed by a sensor read is two transfers, and the first is the one after idle.
3. **One DS18B20 at a time**, lowest channel first, under `--enroll` — cable colours vary and a
   reversed supply destroys the probe (§3a.5 item 4). All four must then enumerate together.
4. **Count `28-*` entries in `/sys/bus/w1/devices/`, never `w1_master_slave_count`.** A bus with
   nothing wired lists a churning set of phantom `00-*` devices read off a floating line; family
   `00` is not a valid 1-Wire family and a DS18B20 is family `28`. Never write a `00-*` ROM ID
   into §5a or bind it to a channel. An *empty* devices directory is the real failure signal,
   since a working bus always registers its master. Rescan is every 10 s.
5. **One SDP810 at a time**, with the isolation test of step 7 after each, a `~RESET` between
   channels when probing, and never an unfitted channel (§5). Write §3a.5 item 1's pin mapping
   before desoldering anything.
6. **If the star ever fails**, try §3a.5 item 5's series resistors and only then split to GPIO27
   as a second bus; the star topology is the suspect, not the sensors.

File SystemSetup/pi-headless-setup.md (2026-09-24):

# Box-2 Pi — headless setup and boot-time reduction

**Scope:** bring the box-2 Raspberry Pi 4B from a stock Raspberry Pi OS Lite install to a headless
logging host running only the services a logger needs, with the I2C and 1-Wire buses the perfboard
expects already configured.

**Subordinate to [ndLouvers instrumentation-spec.md](../../ndLouvers/instrumentation-spec.md).**
That specification owns requirements and acceptance criteria; this file owns the host
configuration that satisfies them, and owns no measurement decision. Where the two disagree, the
specification wins.
`logger-perfboard-wiring.md` owns pinouts, addresses and bring-up
order; this file configures the SoC side of the same pins and does not restate them.

---

## PREAMBLE — READ THIS FIRST

**After completing each step, update the `Work Progress` section at the bottom of this file**:
set the step's status and write a short note on what was actually done, what deviated, and any
values measured. Re-reading this file must always reveal where we left off.

Each numbered step is self-contained and states its own background, commands and acceptance.

**The two rules that matter here:**

1. **Every destructive script defaults to pre-flight.** Run it with no arguments first, read what
   it says it will do, then re-run with `--execute`. This is the iSitePiLogger `prepare-image.sh`
   idiom and it is deliberate.
2. **Bluetooth is never disabled on this box.** iSitePiLogger's `setupNotes.txt` sets
   `dtoverlay=disable-bt`; copying that removes the RaceChrono BLE link, which is the reason box 2
   exists. The same file sets `dtoverlay=disable-wifi`; box 2 keeps Wi-Fi up and blocks it by hand
   only to diagnose BLE (step 8), because a wheel-well cavity has no Ethernet and Wi-Fi is the only
   way back in.

---

## 0. Baseline and current state

The shipped-state audit is preserved in
[CLAUDE.history.md](../CLAUDE.history.md#host-shipped-state); it is not the current machine.
[Work Progress](#work-progress) below owns setup status. Capture a fresh baseline with step 2
when applying this runbook to a new image; do not treat the old audit as a fresh pre-flight.

1. I2C requires both `dtparam=i2c_arm=on` and the `i2c-dev` module to expose `/dev/i2c-1`.
   The headless setup script installs the module-load file. 1-Wire's family alias loads `w1_therm`.
2. Run mutating scripts in a login shell with a terminal for the sudo password. Include
   `/usr/sbin` in PATH before declaring tools such as `rfkill` or `i2cdetect` missing.
3. Bluetooth soft-block state persists across reboot. Clear it with `sudo rfkill unblock bluetooth`;
   `bluetoothctl power on` cannot clear an rfkill block. There is no `hciuart.service` on this image.
4. The clock can resume from the last saved time without NTP. Use the logger's boot/session
   clock for elapsed time — do not restore GPS-time fetching; see history §2.5.

## 1. Step 1 — First login and the outstanding supply check

**Background.** Plan item 5 and build sheet §10 step 4: the Pi runs on the HW-384, which is
fixed-output and cannot be trimmed, so the undervoltage flag is the only available evidence that
the 4.8 V bottom of the vendor band plus pigtail drop clears the Pi's 4.63 V threshold. Build
sheet §10 steps 2 and 3 were retired unperformed at rev 105 (2026-09-20), so this flag and the
logger's supply telemetry are the only supply evidence there will be.

**Do.**

```bash
ssh KnurLogger 'vcgencmd get_throttled; vcgencmd measure_volts core; dmesg | grep -i -E "voltage|throttl"'
```

**Acceptance.** `throttled=0x0`. Bit 0 set means undervoltage now; bit 16 means it has occurred
since boot. Record the value either way.

**The `TP2` meter reading is retired unperformed (rev 105), not owed.** An idle reading does not
settle item 5.7: the flag has to be read under full logging load with every device running, which
is the logger's supply telemetry (`0x604` and the `supply` records) under a run.

---

## 2. Step 2 — Baseline audit, before changing anything

**Background.** Two audits that can be diffed are worth more than any opinion about what a Pi runs
at boot. The disable list in step 4 is written with existence guards rather than assumptions, but
the guards only tell you what happened if you can compare.

**Do.** The script writes nothing to the box; piping it over stdin avoids even creating a file.

```bash
ssh KnurLogger 'bash -s' < SystemSetup/audit-boot.sh > boot-audit-before.txt
```

**Acceptance.** `systemd-analyze time` reports a figure and the file is kept off the box. It is
the only record of the stock state.

---

## 3. Step 3 — Install what the build needs

**Background — and this step has been RUN; see the Work Progress table.** As the box shipped it
had `gcc` and `g++` but no `cmake`, no `git` and no GLib development package, so nothing could be
built on it. `i2c-tools` is needed for `i2cdetect` during bring-up. `rfkill` was already
installed; the script keeps it in the list as a guard and reports it present. **Re-running is
safe** — the script installs only what `dpkg-query` says is missing and exits early with
"Nothing to do" when the list is satisfied, which is what it does now.

**Do.**

```bash
./install-dependencies.sh              # pre-flight
./install-dependencies.sh --execute
```

**Acceptance.** `cmake --version`, `git --version`, `i2cdetect -V` and
`pkg-config --modversion glib-2.0` all answer.

---

## 4. Step 4 — Read the pre-flight output

**Do.**

```bash
./harden-headless.sh | less
```

No arguments means nothing executes. Read every `+` line, and in particular the **"Retained on
purpose"** block at the top — that is the answer to "what still runs at boot, and why", and it is
the part worth disagreeing with if you are going to disagree with anything.

**Acceptance.** You can say, for each retained unit, why it is retained.

---

## 5. Step 5 — Apply the boot-time reduction

**Background — and this step has been RUN; see the Work Progress table.** Eight phases, each
justified against *this* box rather than a generic Pi. The figures below are measured, from step 2,
and are therefore the *before* figures: the phases are described in the tense of a box that has
not had them applied, because that is what makes the justifications legible. What they actually
achieved is in the Work Progress table and in the corrections list after it.

1. **`NetworkManager-wait-online` (5.983 s) and cloud-init (2.53 s).** The first blocks
   `multi-user.target` and runs to its timeout in a car with no access point in range. The second
   finished its real work at first boot — the user, the SSH keys and the Wi-Fi profile persist as
   ordinary files — and every boot since has been a datasource probe finding the same answer.
   Together they are the majority of what is recoverable.
2. **apt / man-db / dpkg / e2scrub / fstrim / logrotate timers** — masked, not merely disabled,
   because apt's timers re-enable themselves on package upgrade. These cause multi-second I/O
   stalls at unpredictable moments, which on a 10 Hz logger means dropped samples.
   The before-audit caught three of them mid-stall and they are the strongest evidence in this
   section: **`fstrim.service` 3.467 s**, **`apt-daily-upgrade.service` 1.581 s** and
   **`e2scrub_reap.service` 1.092 s** — 6.14 s of I/O between them, none of it at a moment
   anybody chose. `fstrim` was the third-slowest unit on the box and went unmentioned here until
   the `--execute` run's diff surfaced it.
3. **rpi-eeprom-update (848 ms), udisks2, keyboard-setup (280 ms), console-setup** — nothing on
   this box consumes any of them, and these four are the ones that actually exist here. The script
   also names ModemManager, rsyslog, triggerhappy, bluealsa, rpcbind, nfs-client.target, cups and
   cups-browsed, and the `--execute` run reported every one of them **"not installed, skipping"**
   (correction 26). They stay in the list as guards against a future image, but nothing on *this*
   box is recovered by them — in particular there is no `rsyslog` here duplicating journald into
   `/var/log`, which an earlier draft of this section claimed as a saving.
4. **Serial console** — `serial-getty@ttyS0` off and `console=serial0` removed from
   `cmdline.txt`. `ttyAMA0` is the Bluetooth UART on a Pi 4B and is untouched.
5. **zram writeback off, zram swap kept.** Swap here is RAM-backed and costs no card wear, so
   there is nothing to gain by removing it. `rpi-zram-writeback.timer` is the exception: its job
   is to push idle zram pages onto the SD card.
6. **Write pressure, and evidence that survives a power cut** — `vm.dirty_background_ratio=5`,
   `vm.dirty_ratio=10` (iSitePiLogger's values and its reasoning; written as `99-` so it sorts
   after the image's own `98-rpi.conf`). Plan item 5b: the supply disappears without
   warning — the fuse pulled at end of day on the constant 12 V feed as built, or a cranking dip
   — so the last durable write bounds what a hard cut costs.

   **The journal setting in this phase cuts against the rest of it and is a deliberate trade.**
   The image ships `Storage=volatile` to spare the card (§0 item 8a); switching to a capped
   persistent journal *adds* a small continuous writer. It is still right here, because the
   failure this box exists to survive — the feed vanishing without warning — is exactly the event
   that destroys a volatile journal, and the journal is the only record of an undervoltage flag,
   thermal event or oops in the seconds before the cut. Deleting
   `/etc/systemd/journald.conf.d/90-knurlogger.conf` reverts to the vendor behaviour.
7. **Un-block Bluetooth, and turn Wi-Fi power save off.** The unblock is the single most
   consequential action the script takes — the radio ships soft-blocked (§0 item 7) and without
   clearing it there is no BLE and no product. Wi-Fi power save is currently unconfigured, so
   defaulting to enabled; it is a common cause of SSH stalling for seconds on an idle Pi and does
   not touch the BLE side.
8. **`config.txt` and `/etc/modules-load.d/knurlogger.conf`** — I2C1 at **100 kHz** *plus the
   `i2c-dev` module* (§0 item 5a: without both there is no `/dev/i2c-1`), `w1-gpio` on GPIO4,
   `gpio=17=op,dh`, and audio / camera / display / splash off. **A reboot is required** — the
   adapter does not exist until the firmware re-reads `config.txt`.

**`gpio=17=op,dh` is the one line that closes an open question rather than saving a resource.**
Build sheet §3a.5 item 6 records that GPIO17 boots as an input with the SoC's ~50 kΩ pull-down
fighting `R12`, and that the resulting level at the mux `~RESET` was never measured. Setting the
pin at firmware time, before Linux starts, means the mux is never held in reset by an unmeasured
divider. It does not answer the question, and does not retire that item's advice to drop `R12` to
4.7 kΩ if the level measures marginal.

**Do.**

```bash
./harden-headless.sh --execute
sudo reboot
```

Optional flags, both off by default and both with a real cost:

- `--drop-mdns` also retires `avahi-daemon`, which is what makes `KnurLogger.local` resolve.
  Reserve a static DHCP lease on the router first, or you lose a way in.
- `--no-hdmi` also drops the KMS driver. It saves a little memory and breaks the emergency console
  on a monitor — which, for a box in a wheel well, is worth more than the memory.

**Acceptance.**

```bash
ssh KnurLogger 'bash -s' < SystemSetup/audit-boot.sh > boot-audit-after.txt
diff boot-audit-before.txt boot-audit-after.txt
```

Boot time should fall from the measured 19.468 s, mostly from phase 1. Record the new figure.

**Rollback.** `config.txt` and `cmdline.txt` are backed up alongside the originals with a
timestamp suffix. Units are masked, so `sudo systemctl unmask <unit>` restores any single one.
cloud-init is re-enabled by removing `/etc/cloud/cloud-init.disabled`.

---

## 6. Step 6 — Confirm nothing needed was broken

**Background.** The failure mode of a script like this is not that it fails loudly; it is that it
removes something the logger needs three weeks later, on a day when the car is on a track.

**Do.**

```bash
ssh KnurLogger
rfkill list bluetooth      # MUST read "Soft blocked: no"
bluetoothctl show          # must NOT read PowerState: off-blocked
nmcli radio                # wifi enabled?
ls -l /dev/i2c-1 ; i2cdetect -y 1
ls /sys/bus/w1/devices/
timedatectl
```

**Acceptance.**

1. `rfkill list bluetooth` reports **`Soft blocked: no`**, and `bluetoothctl show` reports a
   controller that is **not** `PowerState: off-blocked`. **If either fails, stop** — there is no
   BLE and therefore no product. `Powered: no` on an unblocked controller is fine and is the
   logger's job to fix; `off-blocked` is not, and means phase 7 did not take.
2. `nmcli radio` shows Wi-Fi enabled, and this SSH session still works.
3. `/dev/i2c-1` **exists**, and `i2cdetect -y 1` shows **`0x70`** (the PCA9548A mux) and
   **`0x77`** (the BME280) on the main bus and nothing else; the five SDP810s answer at `0x25`
   only behind mux channels 0–4 (correction 32 for the empty-scan expectation this replaced;
   `../hardware-interface.md` before probing behind the mux — **never address channel 5**). A *missing*
   `/dev/i2c-1` is a failure, and means either the dtparam or the `i2c-dev` module did not take
   (§0 item 5a).
   **`/dev/i2c-20` and `/dev/i2c-21` also appear, and they are not yours.** They are the VC4
   display DDC buses, created by `i2c-dev` against adapters the KMS driver registers. Their
   presence proves only the module half; the perfboard is on **bus 1** and nothing else.
   Watching them appear is in fact how the two halves were told apart mid-run: loading `i2c-dev`
   before the reboot produced 20 and 21 but no 1, because the `i2c_arm` adapter does not exist
   until the firmware re-reads `config.txt`.
4. `/sys/bus/w1/devices/` exists and holds `w1_bus_master1`, plus one `28-*` entry per DS18B20
   attached — four with the car's probes plugged in, none on the bench without them. **No `00-*`
   entries**: those were phantom search results off the line while `R11` was unfitted, and they
   stopped once the sensor zone was assembled (correction 32; the phantom set is recorded in
   corrections 25 and 30). **Match only `28-*`, everywhere** — the filter stays mandatory though
   nothing on this box now exercises it — and never branch on `w1_master_slave_count`.
5. `timedatectl` shows `System clock synchronized: yes` while on Wi-Fi. **Give it a minute.**
   Run immediately after boot it reads `no` and `NTP service: active`, because timesyncd has not
   yet reached a server; that is the expected transient, not a failure.

---

## 7. Step 7 — SSH hardening (optional, and the one that can lock you out)

**Background.** iSitePiLogger's posture is key-only auth, no root login, no PAM, port 60022 and
ufw. Two of those are copied and three are not, for reasons stated in the script: `UsePAM no`
costs logind session registration for a marginal gain, and ufw guards a box that is on a home LAN
and then on no network at all.

**Run step 5 first.** While cloud-init is active it rewrites
`/etc/ssh/sshd_config.d/50-cloud-init.conf` at every boot, which would undo this script's edit to
that file. Step 5 phase 1 disables cloud-init.

**Do it from a login shell on the box** — it needs a terminal for both the confirmation prompt and
the sudo password, and refuses to run without one.

```bash
scp SystemSetup/ssh-harden.sh KnurLogger:~/
ssh -t KnurLogger './ssh-harden.sh'                          # pre-flight
ssh -t KnurLogger './ssh-harden.sh --execute'                # key-only auth on port 22
ssh -t KnurLogger './ssh-harden.sh --execute --port 60022'   # ...and add the iSitePiLogger port
```

**Password authentication WAS enabled and is now off — this step has been run** (2026-09-09; see
the Work Progress table). As the box shipped, `50-cloud-init.conf` was 27 bytes, the length of
`PasswordAuthentication yes`, and it sorts before our drop-in so it won. The script found exactly
that, printed the file's contents, and `sed`-ed the keyword to `no` in *that* file rather than only
writing its own — which is the whole point, since writing `90-knurlogger.conf` alone would have
looked like it worked and changed nothing. The file is now 26 bytes, one shorter, which is the
`yes`→`no` edit visible in the byte count.
The script reports the file's actual contents before touching it.

The script refuses to run if `~/.ssh/authorized_keys` is empty, validates with `sshd -t` before
reloading anything, keeps port 22 listening when it adds a new one, and handles Trixie's socket
activation, under which `Port` in `sshd_config` is ignored and the listener comes from
`ssh.socket`.

**Acceptance.** From a **second terminal**, while the first is still open:

```bash
ssh KnurLogger
ssh -p 60022 KnurLogger     # if a port was added
```

Only after both succeed, drop port 22 by hand.

---

## 8. Step 8 — Wi-Fi gating for a run

**Background.** Wi-Fi and BT share one radio and one antenna on the BCM43455, and background
scanning is a known source of BLE jitter.

**Decision: gating is manual** (owner, 2026-09-23). The installed link has run clean through the
track sessions with Wi-Fi left up, so nothing gates it routinely and the logger will not own it.
Gate by hand only when diagnosing a BLE link problem:

```bash
sudo rfkill block wifi         # before the diagnostic run
sudo rfkill unblock wifi       # after, to collect the session files
```

`sudo nmcli radio wifi off` does the same through NetworkManager; both are installed. Either is
preferable to `dtoverlay=disable-wifi`, which needs an SD card and a text editor to undo.

**Never use bare `rfkill block all`.** It would take the Bluetooth radio down with Wi-Fi, and
because `systemd-rfkill` persists the state it would stay down across the next reboot — which is
exactly the condition the box shipped in.

---

## 9. Not done, and deliberately

1. **Read-only root / overlayfs.** The real answer to unannounced power cuts and the correct
   long-term shape for a box whose supply vanishes without warning. Not done now because it
   complicates development on the same machine, and because plan item 5b's `fsync` cadence plus
   step 5 phase 6's dirty-page ratios already bound the loss to about a second. Revisit before the
   first event, not after.
2. **The logger systemd unit is no longer in this list** — `SystemSetup/KnurLogger.service` is
   installed, enabled and survives a reboot (Work Progress row 12). It does not copy
   `iSitePiLogger.service`'s `ExecStartPre=/usr/bin/sleep 12` readiness hack, and it must never
   name `network-online.target`, which cannot be reached on this box.
3. **Powering the Bluetooth controller.** Clearing the rfkill *block* is host configuration and
   step 5 phase 7 does it. Bringing the controller up and advertising afterwards is the logger's
   job, not this runbook's.
4. **Any measurement.** Nothing here calibrates, qualifies or commissions anything. Build sheet
   §10 steps 2, 3, 5 and 6 were retired unperformed at rev 105 (2026-09-20), and steps 7–9 are
   done in substance; step 10 and the plan's commissioning items belong to the build sheet and the
   plan, not to this file.

---

## Work Progress

| Step | Status | Notes |
|---|---|---|
| 0. Measured state | **done** 2026-09-09 | Full `audit-boot.sh` run over SSH. Pi 4B Rev 1.5 4 GB, RPi OS Lite 64-bit Trixie, kernel 6.18.34. Boot 19.468 s, `multi-user.target` 11.305 s. No failed units. |
| 1. `get_throttled` | **done (idle only)** 2026-09-09 | **`throttled=0x0`**, `volt=0.9060V` core, SoC 43.8 °C, no voltage/throttling lines in `dmesg`. Plan item 5.4 passes **at idle with no sensors attached**. Build sheet §10 step 2's `TP2` meter measurement was retired unperformed at rev 105 (2026-09-20); item 5.7's under-load reading is the logger's supply telemetry. |
| 2. Baseline audit | **done** 2026-09-09 | Piped over stdin, so nothing was written to the box. Findings folded into §0 and into the scripts — see the three corrections below. |
| 3. Install dependencies | **done** 2026-09-09 | `--execute` run from a login shell. `git 2.47.3`, `cmake 3.31.6`, `i2cdetect 4.4` and `glib-2.0 2.84.4` all answer; `build-essential` and `rfkill` were already present and were skipped. **It also upgraded 14 packages it never named** — the util-linux family, `rfkill` included — see correction 27. The box can now build. |
| 4. Read pre-flight output | **done** 2026-09-09 | All four scripts pre-flight against the box with exit 0 and no suspicious output, repeatedly, including the `--drop-mdns`, `--no-hdmi` and `--port` paths and every bad-argument case. Pre-flight changes nothing, so this does not advance step 5. |
| 5. Apply boot-time reduction | **done** 2026-09-09 | `--execute` from a login shell, all eight phases, both optional flags left off (`--drop-mdns` costs `.local` resolution, `--no-hdmi` costs the emergency console). No `FAILED to mask`, no `modprobe i2c-dev` warning. **Boot 19.468 s → 11.105 s**, userspace 17.463 → 9.108 s, `multi-user.target` 11.305 → 9.108 s. 17 units newly masked, enabled timers 9 → 2, cloud-init disabled, no failed units. Backups at `/boot/firmware/{config,cmdline}.txt.bak-20260909-123716`. Rebooted; `before`/`after` audits diffed. `NetworkManager.service` at 5.236 s is now the whole critical chain and cutting it costs the way back in. |
| 6. Confirm nothing broke | **done** 2026-09-09 | All five criteria pass. **`rfkill list bluetooth` → `Soft blocked: no`, and it survived the reboot**; `hciconfig` → `UP RUNNING`; BlueZ → `Powered: yes` / `PowerState: on`, which is better than the criterion asked for. Wi-Fi enabled and this SSH session never dropped. **`/dev/i2c-1` exists**, scanning empty as expected *at the time* — the sensor zone has since been assembled, so an empty scan is no longer the correct result; see correction 32. 1-Wire master registered — but the devices directory was **not** empty, see correction 25, itself now superseded by correction 32. `System clock synchronized: yes` after ~1 min, see correction 28. `throttled=0x0` at 56.0 °C. |
| 7. SSH hardening | **done** 2026-09-09 | `--execute` from a login shell, no `--port`. `sshd -t` reported **configuration is valid** before the reload. Effective now: `passwordauthentication no`, `kbdinteractiveauthentication no`, `permitrootlogin no`, `pubkeyauthentication yes`, `usepam yes` (deliberately kept), `port 22` listening on both stacks. `~/.ssh` 700 and `authorized_keys` 600, one key (`chrum@WielkiRig`). **Verified two ways**: the owner logged in from a second terminal while the first was open, and a forced password-only attempt from the workstation is refused with `Permission denied (publickey)` — the positive check, not just "keys still work". `ssh.service` owns the listener, so the socket-activation path was not needed. No failed units. **See correction 31: re-enabling cloud-init would undo this.** Its blocker had been cleared first: step 5 phase 1 disabled cloud-init, so `50-cloud-init.conf` is no longer rewritten at every boot. |
| 9. Full system upgrade | **done** 2026-09-09 | `apt-get full-upgrade` — **94 upgraded, 10 newly installed, 0 removed**, pre-flighted with `-s` first. Run to fix a BLE advertising failure that turned out to be a BlueZ/kernel structure mismatch (see `../CLAUDE.history.md` §1.2). `bluez 5.82-1.1+rpt1` → `+rpt2`, kernel `6.18.34` → `6.18.39`, `firmware-brcm80211` `1:20250410` → `1:20260519` — all three layers of the mismatch moved together, so **which one fixed it is unknown and deliberately not chased**. Verified after reboot: advertising works (`ActiveInstances: 1` with the logger running), `config.txt` untouched (`gpio=17=op,dh`, both bus lines intact), `pinctrl get 17` still `op -- pd | hi`, I2C shows `70` and `77`, w1 master present, `rfkill` still `Soft blocked: no`, **no failed units**, enabled timers still 2, masks survived. Audits at `boot-audit-preupgrade.txt` / `boot-audit-postupgrade.txt`. |
| 10. Production install | **done** 2026-09-10 | `deploy-logger.sh --execute`. The logger runs from `~/bin/KnurLogger` reading `~/bin/KnurLogger.ini`, separately from the build tree in `~/KnurLogger/build/`. **The two `.ini` files are not the same file and must not be conflated**: the build-tree one is the git-tracked template, the `~/bin` one carries the real ROM ID bindings and calibration offsets and is never overwritten by a deploy or by the `tar` build sync. `KnurLogger.service` points at `/home/chrum/bin/KnurLogger`; see step 12. `~/bin/KnurLogger.ini` holds the four ROM ID bindings enrolled 2026-09-10 and four zero offsets (the cold-soak calibration's result). |
| 11. 1-Wire bulk-read permission | **done** 2026-09-10 | `grant-w1-bulk-read.sh --execute --verify` from a login shell. The udev rule gives the `gpio` group write access to `w1_bus_master*/therm_bulk_read`, which `w1_therm` registers `0644 root:root`; without it the logger's write is refused with `EACCES` (errno 13) and four probes sample at **0.31 Hz instead of ~1 Hz**. **Verified against a fake probe, not a real one**: `--verify` writes a family-0x28 id to `w1_master_add`, the attribute appears as `root:gpio 664`, `chrum` writes it successfully, and the fake slave is removed again — bus left with the master alone. **The rate did NOT change and the permission was not the whole fault** (measured with four real probes the same day): 331 cycles at 3190–3309 ms, every probe still ~800 ms. **The other half was found 2026-09-11 and is in the logger, not here:** the trigger must be written as eight bytes (`"trigger
"`), because `therm_bulk_read_store` gates on `size == sizeof("trigger")`. With both in place, 123 cycles at a 1023 ms mean interval — **0.977 Hz** — and one 762–790 ms conversion for all four probes. Parasite power was the standing suspect and was wrong. The rule is correct and stays. Plan open item 43 and `../CLAUDE.history.md` §1.15. |
| 12. KnurLogger.service | **done** 2026-09-10 | Installed to `/etc/systemd/system/`, `daemon-reload`, `enable --now`, and **verified across a reboot** — `active` and `enabled`, all four channels bound at startup, BLE advertising. It runs `/home/chrum/bin/KnurLogger` in log mode as `chrum`. **Consequence for anything done by hand from now on: the logger is ALREADY RUNNING whenever the box is powered.** Two instances both poll the 1-Wire bus, each read triggering its own conversion, which roughly doubles cycle time and would corrupt any timing measurement — so `sudo systemctl stop KnurLogger` before running the binary by hand, `--enroll` included. Live view is `journalctl -u KnurLogger -f`. |
| 8. Wi-Fi gating | **done — manual** | Owner decision 2026-09-23: gate by hand with `rfkill block wifi` / `nmcli radio wifi off` only when diagnosing a BLE link problem; the logger does not own it. |

### Setup incident history

The dated audit and execution corrections are in
[CLAUDE.history.md — host setup corrections](../CLAUDE.history.md#host-setup-corrections).
The procedures above retain the applicable technique; this runbook owns current setup and progress.

### Script review status

The four scripts have been through **five review passes** (2026-09-09; history revs 66–66d in the
plan's companion file). What that did and did not establish:

1. **Established.** They pre-flight cleanly against the real box; `shellcheck` 0.11.0 at `-S style`
   reports only an informational SC1091; Phase 8 is idempotent across three runs against the real
   `config.txt`; every unit they mask is `WantedBy` something and `RequiredBy` nothing; every
   config file they write wins its ordering contest; every unit named in the "Retained on purpose"
   block exists.
2. **Now also established, by running them.** `install-dependencies.sh --execute` and
   `harden-headless.sh --execute` have both been run, followed by a reboot and a diffed re-audit
   (2026-09-09). Every phase completed, no unit failed to mask, the box came back, and the five
   step 6 acceptance criteria pass. That run produced corrections 25–29, and every one of them is
   a thing the five static passes could not have reached: what the kernel does with a bare 1-Wire
   bus, which units this image actually ships, what apt drags in behind a four-package list, how
   long timesyncd takes, and which retained units are D-Bus-activated rather than booted. The
   prediction that the remaining unknowns were all on the far side of `--execute` held.
3. **All four scripts have now been run with `--execute`** (2026-09-09), `ssh-harden.sh` last and
   verified from a second terminal plus a forced password-only attempt. **Since then the host has
   carried the logger under load** — BLE to RaceChrono, a 38.09-hour continuous session, two
   track days and, since 2026-09-19, the 10 Hz pressure worker — with `throttled` logged every second by the logger's supply
   worker.

### Open items owned by this file

1. **`avahi-daemon` keep or drop** — kept by default. Dropping needs a static DHCP reservation.
2. **Read-only root** — see §9 item 1. The decision remains open; the original pre-event
   deadline is stale because events have already run. Do not infer acceptance or retirement from that.

**I2C bus speed is not an open item.** Build sheet §6 specifies 100 kHz and owns the decision.
Raising it needs a segment-capacitance measurement or lower pull-ups, and a change to the build
sheet first — not a change here.

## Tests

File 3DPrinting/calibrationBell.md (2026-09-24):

# Liquid-sealed pressure bell — printed reference source

This file owns fixture geometry, constants and use. Measurement requirements and acceptance
belong to [ndLouvers instrumentation-spec.md](../../ndLouvers/instrumentation-spec.md);
[pressure-testing.md](../../ndLouvers/pressure-testing.md) owns the calibration regime,
measured chain results and qualification status.

**Use the As built section for the existing bell.** The nominal rev F drawing below describes
another geometry; do not substitute its constants into reductions of this fixture. The current
pressure results and withdrawn figures are in the measurement companion's §3.3 and §3.5.
Do not restore the impracticable add-mass test — see pressure history §3.3–§3.14.

[calibrationBell.svg](calibrationBell.svg) is the rev F drawing;
[calibrationBellWeighing.svg](calibrationBellWeighing.svg) illustrates the weighing rig.
Printed parts live beside them: `calibrationBell.stl`, `calibrationBellPan.stl`,
`calibrationBell.3mf` and `pipeStand.stl`.

## As built — the bell that exists, 2026-09-20

**These supersede every nominal figure in this file and on the drawing, for this part.** Geometry
read directly from `calibrationBell.stl`; wall and ID confirmed on the printed part with calipers;
`A_eff` measured with water. `k_d` is computed, not measured — a slope read through a sensor carries
that sensor's span and the barometric term, which is why the one attempt at measuring it is withdrawn.

| | STL | printed, measured | rev F nominal |
|---|---|---|---|
| OD | 151.80 | 152 | 150.0 |
| **ID** | **150.00** | **150.0 ± 0.2** | 148.4 |
| **wall** | 0.90 | **0.90** away from the rim; the caliper's 1.00 is the squished rim-down first layer | 0.80 |
| skirt, lid to rim | 113.5 | — | 115 |
| CG above the rim | **71.65** | — | — |
| features | plain skirt, 0.803 lid, **six lid ribs (2.2 cm³)**, Ø10 × 7 boss (0.5 cm³) | as STL | collar, 6 ribs, Ø16 × 25 tapped hub |
| graduations | **none** | none as printed; **since added**, zeroed at the rim, ±0.2 mm (`../../ndLouvers/step0b-rig/sensor-ladder-runsheet.md` §4) | every 5, zero at the rim |
| mass | 80.7 g at 1.24 | **79 g** weighed, **78 g** slicer; **81 g** with graduations | 88 g rod-less |

| constant | **as built** | superseded | rev F rod-less nominal |
|---|---|---|---|
| `A_eff` | **17 392 mm² — MEASURED WITH WATER** | 17 671 (from ID 150.00) | 17 296 mm² |
| `A_wall` | **423.3 mm²** (0.90 × 467.5 perimeter + π·0.90²) | 474 | 375 mm² |
| `A_rod` | **5.62 mm²** (M3 pitch diameter; the rod hangs from the bell) | — | — |
| **`k_m`** | **0.5639 Pa/g** | 0.5551 / 0.5549 | 0.5670 Pa/g |
| **`k_d`** | **0.2414 Pa/mm** (wall + rod) | 0.2367 wall only; 0.2372 measured, 0.2337 rod-less | 0.2122 Pa/mm |
| `ΔP/Δm` at constant volume | **0.5405 Pa/g** (`g/A_o`) | — | — |

> **⚠ `A_eff` IS MEASURED, NOT COMPUTED FROM THE ID — AND IT IS 1.6 % BELOW π/4·150²**
> (2026-09-22). A **datum-free two-fill difference**, 1215 g of water between the 30 mm and 100 mm
> marks, gives **17 392 mm²**; a 50 mm single fill corroborates it to **0.08 %**. The equivalent
> circular bore is 148.8 mm, i.e. about **150.0 × 147.6 as an oval** — which is what a 0.90 mm-walled
> printed cylinder does, and a caliper reports whichever axis it is handed. **Measure the ID on two
> axes before trusting a single number.**
>
> **Fill with the M3 rod fitted — that is correct, not a tolerated error.** `A_eff` in the force
> balance is the bore *minus* the rod, and the water occupies exactly that, so the two match with no
> correction. The six lid ribs and the central boss total **2.73 cm³** and sit below the 30 mm mark,
> so the two-fill difference cancels them; they matter only to a single fill referenced to the lid.
>
> **`k_d` = 0.2372 is WITHDRAWN as a measurement.** It was the slope of *reading* against depth, so
> it carried the reading sensor's span and the barometric term of `../../ndLouvers/pressure-testing.md`
> §2.3a. **And the 0.891 mm wall was inverted from it, which makes that pair circular** — do not
> re-derive either from the other. 0.2414 comes from geometry on the measured `A_eff`, the STL's
> 0.90 mm wall and the rod's pitch-diameter area.

1. **The print over-extruded ~0.1 mm on the wall, outward**, OD 151.80 → 152. **But "`A_eff` and
   `k_m` are unaffected" was wrong** (corrected 2026-09-23): `A_eff` is **1.6 % below** π/4·150²
   because the bore is **oval**, not because of the wall. Use the water-measured 17 392 mm².
   **And the 0.891 mm wall inverted from the old slope is withdrawn** — that inversion assumed the
   sensor was exact and the barometer irrelevant, and it produced a wall that was then used to
   justify the slope it came from. Take **0.90 mm from the STL**; the caliper's 1.00 was read at
   the rim, the first layer of a part printed rim-down, which is squished wider. Measure a printed
   wall away from the sealing edge, and **measure the ID on two axes**.
2. **Three independent mass figures agree to 2.5 g** — 80.7 g from STL volume at 1.24, 78 g from
   the slicer, 79 g on the scale. The slicer's does not come from the scale, so **this bounds the
   scale's span error at about ±1 g = ±0.55 Pa** at the bare-bell working point.
3. **No graduations were printed**, and reading `d` by eye against the plain skirt measured
   **±1 mm of scatter plus a ~1.7 mm systematic** (history §3.3c). **Graduations have since been
   added** — zeroed at the rim, ±0.2 mm (`../../ndLouvers/step0b-rig/sensor-ladder-runsheet.md` §4).
4. **There is no bell residual.** The "residual" this item carried — sighted from −0.4 Pa bare to
   +14 Pa at 726 g, growing with pressure — was the reading sensors' span, a **1.6 % bore error**
   (fixed by measuring `A_eff` with water) and the **4.2 % barometric term**
   (`../../ndLouvers/pressure-testing.md` §2.3a). With those applied all five parts are inside ±3 %
   (`pressure-testing.md` §3.3b). **The sightings and the per-sensor figures drawn from them are
   superseded — do not quote them**; they are in `../../ndLouvers/pressure-testing.history.md` §1
   (§3.3c, "the bell residual") and its sessions §3.9–§3.14.
   **THE ADD-MASS TEST CANNOT BE PERFORMED ON THIS BUILD** (owner, 2026-09-21): the pan is not
   reachable with the bell afloat, and changing weights means lifting the bell out, which resets
   the trapped volume the derivation in §"Use it differentially" depends on. **Retired as
   impracticable, not as unwanted.** The substitute is two settled placements at different loads
   compared at matched `d`, which cancels tare, datum and meniscus equally but returns
   `(1 + ε)(1 − f̄)` rather than `(1 + ε)`, because the line loss changes with load. A rebuild that
   wanted the check back needs a load path reachable from outside the skirt — a hook below the rim,
   or a pan that clears the tub floor by a hand's width. Plan open item 57 (closed 2026-09-24).

> **⚠ REVS A–E ARE SUPERSEDED. DO NOT BUILD ANY OF THEM.**
> **Rev A** floated the bell free with the masses on a tray on top. It capsizes — confirmed on the
> bench 2026-09-20 and explained below. **Rev B** fixed that with a central guide rod and linear
> bearings; it works, but it puts friction into the one place that must stay free.
> **Rev C hung the load underneath instead**, which removes the instability and the friction at
> the same time, but at Ø180 it needs 1.35 kg of washers. **Rev D is rev C at Ø150** — 921 g,
> a 4 L tub instead of 6.5 L, and a 43 Pa floor instead of 37 Pa. **Rev E swaps the Ø6 aluminium
> rod for M3 stainless threaded**, which is lighter, drops a galvanic pair, and — because a
> tapped hub is removable — turns the rod-less point into a grub screw instead of a tape patch.
> **Rev F puts the PLA pan back** in place of rev E's nut and backing washer (owner preference);
> it costs 1.3 Pa of floor and adds a second material to the apparent-mass arithmetic.
> The retired revisions are described here only so nobody rebuilds one from an old screenshot.

## What problem it solves

An SDP810 measures Δp by passing gas through an internal bypass, so **it is itself a flow path
between its two ports** and it drains any static reference. A 50 cm head on a 6 mm U-tube collapsed
in under 2 s (2026-09-19, `P0`). Ballast does not fix it: 5 L against the estimated bleed resistance
gives a 23 s time constant, and §2.5 asks for a 20 s plateau.

A bell does not fight the bleed. It is a **constant-pressure source**: as gas escapes the bell
sinks, and the pressure — weight over area — does not change. The supply only has to replace what
the sensor drinks. **Measured: ~0.3 mL/s at ~38 Pa and ~1.5 mL/s at ~394 Pa**, the top of this
bell's range (the 2026-09-22 ladder's sink rates × `A_o`). The circuit resistance is
**flow-dependent** — ~1.0 × 10⁸ Pa·s/m³ at 0.3 mL/s, ~2.6 × 10⁸ at 1.5 mL/s (history §3.5–§3.6,
`../../ndLouvers/pressure-testing.md` §2.3) — so **the demand does not scale linearly with
pressure**. **At the top rung the bell sinks ~5 mm/min and a charge lasts ~5–6 minutes** over the
tub's ~28 mm of usable travel.

Its accuracy comes from **mass and diameter**, both measurable at home to better than 0.2 %, rather
than from a liquid column read against a ruler. That is the other half of the U-tube's problem:
125 Pa is 12.7 mm of water, and contact-angle hysteresis alone puts ±1 mm of uncertainty on a 6 mm
bore — ±10 Pa, before anyone picks up a ruler.

## Why the load has to hang below

**A constant-pressure source is neutrally stable in heave by construction** — pushing it down does
not raise its upthrust, which is the very property that makes it immune to the bleed. The same
property leaves it almost no stiffness in *tilt*. The only restoring moment a floating bell has is
the buoyancy of the ring of wall piercing the surface:

    K_ring = ρ·g·π·R³·t  =  0.0104 N·m/rad    (R = 75 mm, t = 0.8 mm)

It falls as R³, so a smaller bell has even less of it — but the hanging load dominates either way.

Against that, the weight acts through the CG while the gas force acts through the lid centroid, so a
CG a distance ℓ *above* the lid plane contributes −W·ℓ:

| configuration | tilt stiffness | |
|---|---|---|
| rev A, bare bell | +0.053 N·m/rad | stable |
| rev A at 125 Pa, masses on the tray | +0.001 N·m/rad | neutral — tips at a touch |
| rev A at 500 Pa, masses on the tray | **−0.139** N·m/rad | **capsizes** |
| rev F, bare bell | +0.041 N·m/rad | stable |
| rev F at 125 Pa | +0.27 N·m/rad | solid |
| rev F at 500 Pa | **+1.24** N·m/rad | very solid |

With 1308 g aboard, rev A's combined CG had to sit within **1.4 mm** of the lid plane. Nothing
achievable. **Rev F's stability rises with load instead of falling**, because the stabilising mass
and the applied mass are the same object.

> **⚠ THE +0.041 N·m/rad "BARE, STABLE" ROW IS CONTRADICTED BY THE BENCH** (2026-09-20,
> `../../ndLouvers/pressure-testing.history.md` §3.3e). A bare bell on this geometry **capsized twice at an
> immersion of 49–50 mm and settled at a 5–8° angle of loll at 59–64 mm.** A 5–8° loll on the
> wall-sided relation `tan θ = √(−2·GM/BM)` with `BM` ≈ 16 mm puts `GM` at **≈ −0.1 mm** — neutral,
> not stable — and the capsize at 49 mm requires **`GM` ≈ −6 mm**. The bare bell reaches neutral
> only at an immersion near **60 mm** and improves from there.
>
> **The likely cause of the error is the reference plane, and the correction is an owner decision,
> not an edit I have made.** The table above takes the righting couple about the **lid plane**
> (`+W·ℓ`, ℓ = the CG below the lid). A metacentric treatment takes it about the **centre of
> buoyancy**, which on this bell sits **7–14 mm below the water** rather than 45–67 mm above it at
> the lid — roughly 50 mm of righting arm the bell does not have. The paragraph immediately above
> this table already says the right thing in words: *"the same property leaves it almost no
> stiffness in tilt."* **The prose and the table disagree, and the bench agrees with the prose.**
> **CONFIRMED AGAIN ON A DIFFERENT BALLAST, AND THE CROSSOVER IS NOW LOCATED** (2026-09-21,
> history §3.8e). With 17.5 g of ballast the bell **lolled ~5° at d ≤ 57 mm and returned upright by
> d ≥ 64.5 mm**, unaided, as it sank — so the crossover is bracketed in **57–64.5 mm**, against the
> ≈ 60 mm this box predicted from the capsize and loll angles. **The immersion dependence the table
> omits is real, repeatable across ballasts, and now quantified.** Third bench contradiction of
> the "+0.041 N·m/rad, bare, stable" row.
> **A tilt costs more through the waterline than through `cos θ`.** At 5° the `cos θ` term is only
> +0.21 Pa on a 38 Pa point, but the waterline runs **±6.6 mm around a 150 mm skirt — 1.6 Pa** — so
> which azimuth `d` is read at dominates. The force balance wants the **axis** waterline, i.e. the
> mean of the high and low sides. **Record the read azimuth whenever the bell is not upright**, and
> treat any mark below d ≈ 60 mm in a light configuration as untrustworthy without it.
> Until the model is re-derived, treat the load rows as unverified too, and **do not run this bell
> bare** — §"What it can and cannot reach" carries the working consequence.

**Do not "improve" this with a fixed ballast.** Stabilising weight below the lid and the pressure
floor are the *same quantity*. A fixed ballast hung deep enough to give the full-load stiffness
would need ~333 g of apparent weight at 150 mm, which puts **~190 Pa on the floor** at Ø150 —
worse than the instrument's whole useful low range. Only the applied load can pay for its own
stability, which is exactly what hanging it does.

## The formula

    P = k_m · m_app  −  k_d · d

- `m_app` — **apparent** mass, in grams (below)
- `d` — rim immersion, read off the skirt graduations at the axis waterline (mean of the high and low sides, `pressure-testing.md` §2.2b item 5), in mm
- `k_m = g / A_eff` — nominal **0.5672 Pa/g**
- `k_d = ρ·g·(A_wall + A_rod) / A_eff` — nominal **0.2155 Pa/mm**

**Those two numbers are rev F NOMINAL and are not the bell that exists** — see §"As built", where
`k_m` is **0.5639** and `k_d` **0.2414** (§"As built"; the 0.5549–0.5551 and 0.2337/0.2372 pairs are
withdrawn). The formula itself is
unchanged; only the constants move.
Nominal `ID 148.4` with an M3 rod → `A_eff = 17 289 mm²`, `A_wall = 375 mm²`, water at 20 °C.
**A thread has two areas and they go in different places:** the **major** diameter (7.07 mm²) is
what the bore removes from the lid; the **pitch** diameter (5.62 mm²) is what displaces water at
the surface. Both are ~0.04 % of `A_eff`, so the distinction changes nothing — it is written down
only so the next reader does not have to decide which one to use. `k_d` is larger than rev A/B's because the rod now pierces the water surface
alongside the skirt.

**Derivation**, so nobody has to re-derive it: taking the force balance with gas on the lid
underside, liquid pressure on the rim annulus, buoyancy of the submerged hanging load, and weight
down, the effective area comes out as the **inner** cross-section less the rod bore, and the
correction is the buoyancy of whatever crosses the surface. The outer and mid-wall diameters both
appear in intermediate steps and neither is the answer.

### `m_app` is dry masses plus one measured ratio

Routine use is pure arithmetic:

    m_app = (bell + lid + rod, dry) + 0.8736 × (stainless, dry) + 0.195 × (PLA pan, dry)

**The rod is not in the buoyancy term.** Its submerged length changes with `d`, so it lives in `k_d`
via `A_rod`; only the *always* submerged pieces — washers, pan, nut — get a ratio. In
rev F there are two: **0.8736 for the stainless, 0.195 for the PLA pan.**

**But measure that ratio; do not take it from a table.** `m_app = m_dry·(1 − ρ_w/ρ_ss)`, and a 1 %
error in the assumed density gives a **0.145 %** error in P. That sounds tolerable until you notice
what you would be assuming:

| ρ (g/cm³) | `m_app/m_dry` | vs 304 | |
|---|---|---|---|
| 7.70 | 0.87036 | −0.376 % | 430 ferritic — common in cheap washers |
| 7.75 | 0.87120 | −0.280 % | 410 |
| 7.85 | 0.87284 | −0.092 % | the generic "steel" table value |
| **7.90** | **0.87365** | — | **304 / A2** |
| 8.00 | 0.87523 | +0.181 % | 316 / A4 |

The grade spread is **0.56 % of reading, 2.8 Pa at 500 Pa** — on its own as large as everything
else in the budget put together, and comparable to an unchecked scale span. A bin of "stainless
washers" does not say which grade it is. A magnet halves the range for free — 430 and 410 are strongly magnetic,
304 and 316 largely are not — but cold-worked 304 goes weakly magnetic, so treat it as an indicator
rather than a determination.

**Three ways to pin it down, best first:**

| method | error on P |
|---|---|
| **hydrostatic weighing of the batch** — 0.1 g on 800 g | **0.013 %** |
| displacement in a graduated cylinder — ±1 mL on 117 mL | 0.124 % |
| caliper dimensions | ~0.22 % — thickness and stamping burrs dominate |

One weighing per material, once ever. After that the arithmetic above is exact, because apparent
weights add and each ratio applies to any subset. The caliper route is the one to avoid.

### Use it differentially — the one check that removes the degeneracy

`P = k_m·m_app − k_d·d` has three unknowns that all enter as a single constant: the tare mass, the
`d` datum and the skirt meniscus force. **No absolute reading can separate them**, and 2026-09-20
left a −0.42 ± 0.19 Pa residual that none of the three could be told apart from — since shown to
be the sensor's span, not a bell term (§"As built" item 4).

> **⚠ THE ADD-MASS CHECK CANNOT BE PERFORMED ON THIS BUILD — RETIRED** (owner, 2026-09-21): the pan
> is unreachable with the bell afloat (§"As built" item 4). The procedure is kept for a rebuild with
> a load path reachable from outside the skirt; do not schedule it on this bell.

**Adding a known mass does separate them.** At constant trapped volume the bell sinks until the
extra displacement carries the extra weight, and the algebra collapses to

    ΔP = Δm·g / A_o  =  0.5405 Pa/g   (as built, A_o = 18 146 mm²)

exact, with `d`, the tare and the meniscus all cancelling from the difference. **Only the scale's
span survives**, which is the one term this file already says is the reference. Do this first with
the reference weights, before any absolute ladder point is taken seriously.

**[`calibrationBellWeighing.svg`](calibrationBellWeighing.svg) is the rig**, and the trick that makes it
easy is that **you never weigh the object in water — you weigh the water.** Tare a dish on the
scale, lower the load in from a stand that rests on the bench, and the scale reads the displaced
mass directly, because the buoyant force has an equal and opposite reaction on the liquid. No
below-balance hook, no special balance.

The sheet draws **two ways to hold the load**, and the method is identical for both:

| | |
|---|---|
| **A — a thread** | 0.3 mm fishing line, laced straight through the washers' own Ø13 bores. Smallest correction, no carrier to account for. |
| **B — the bell's own rod** | Rigid, cannot swing into a wall, and the pan is already on it. Larger correction, but it is cancelled exactly. |

**Take a blank reading if — and only if — your scale can see it.** Lower the bare thread or rod to
a marked depth, read it, then re-tare and repeat with the load at the *same* mark;
`m_disp = L − B`. It cancels the suspension's own displacement, its meniscus, a soaked knot and any
carrier, all at once. But it is worth **0.008 Pa on 0.3 mm line and 0.06 Pa on a Ø3 rod**, so on a
1 g-resolution scale it is entirely invisible and you should skip it. See the scale section below.

⚠ **Lace the washers onto the line itself rather than using a hook or a mesh bag.** A carrier is a
second material with its own displacement, and you would end up measuring the ratio of
washers-plus-carrier, which is not a quantity you need. This one still matters on a coarse scale,
because a wire hook or a bag can easily displace several grams.

## Your scale is the reference — resolution is not its important property

`P = k_m·m_app − k_d·d`, so **a scale reading (1+ε) times true makes every pressure (1+ε) times
true.** The scale's *span* error propagates straight through as a span error on the reference, and
no averaging removes it. Resolution, by contrast, is a rounding term that barely registers.

Budget at 500 Pa (`m_app` ≈ 906 g), RSS:

| term | 1 g scale, span unchecked | 1 g, span ±0.1 % | 0.1 g, span ±0.1 % |
|---|---|---|---|
| rounding, ±½ division | 0.28 Pa | 0.28 Pa | 0.03 Pa |
| **scale span** | **2.57 Pa** | 0.51 Pa | 0.51 Pa |
| stainless ratio, from 117 g of displacement | 0.57 Pa | 0.57 Pa | 0.06 Pa |
| PLA pan displacement, 16 g | 0.57 Pa | 0.57 Pa | 0.06 Pa |
| area, ID to ±0.15 mm | 0.85 Pa | 0.85 Pa | 0.85 Pa |
| `d` to ±1 mm | 0.22 Pa | 0.22 Pa | 0.22 Pa |
| **total** | **2.85 Pa = 0.57 %** | **1.32 Pa = 0.26 %** | **1.02 Pa = 0.20 %** |

> **⚠ FOUR TERMS MEASURED ON 2026-09-20 ARE MISSING FROM THAT TABLE, AND AT THE BOTTOM OF THE RANGE
> THEY DOMINATE IT.** `../../ndLouvers/pressure-testing.history.md` §3.3 owns the evidence; `pressure-testing.md` §2.2b carries the rules.
>
> | term | size | at 500 Pa | at 43 Pa |
> |---|---|---|---|
> | **wetted-bell film** after any handling, decaying ~80 s | 2.5 g = **1.4 Pa** | 0.28 % | **3.3 %** |
> | **skirt meniscus force**, contact angle unknown | 0 to **±3.9 Pa** | 0.78 % | **9 %** |
> | **tilt**, `P → Mg/(A_eff·cos θ)`, 10° | **0.44 Pa** | 0.09 % | 1.0 % |
> | **`d` read by eye, no graduations** (as on 2026-09-20; since added, ±0.2 mm) | ±1 mm scatter **+1.7 mm systematic** | 0.15 % | 1.0 % |
>
> **The film is the one that bites in practice** — five replications in one session, and the
> before-and-after weighing in §"Measure the finished part" **cannot see it**, because that check is
> for ingress *into* the bell while the film is on the outside, present when you read and gone when
> you weigh. **Charge through the standpipe so the bell never leaves the water**, and if it must be
> handled, wait two minutes.
> **The meniscus term is a band, not a bias** — contact-angle hysteresis means it is not repeatable
> between settlings, and its sign follows whether the skirt is wetting or not. It is unmeasured.
> **The tilt term is silent**: the 65 s of record before an observed 5–8° loll was as quiet as any
> settled stretch, so **no past reading can be audited for it**. Look at the bell before every
> reading and record that you did.

Three things fall out of that table:

1. **Even the worst column is five times better than the SDP810's own 3 % span spec.** The exercise
   is worth doing on whatever scale you already own; it is not worth abandoning for want of a
   better one.
2. **Checking the span is worth far more than buying resolution.** It takes the total from 0.57 %
   to 0.26 %; going from 1 g to 0.1 g on top of that buys only 0.26 % → 0.20 %, because by then the
   **area** term dominates and the scale has stopped mattering.
3. **So buy one calibration weight, not a better scale.** A 500 g or 1 kg M1/F2 weight is the
   cheapest item in this whole project and it is the reference for the reference. Check near the
   *working* mass — a span check at 500 g assumes linearity up to 900 g. Weighing A, B and A+B
   separately tests linearity, but it cannot see a pure gain error, so it is not a substitute.
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

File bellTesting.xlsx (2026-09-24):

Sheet: Sheet1
bell: | 81 | rodU | 5.5 | 86.5 |  | ballastDryAll | 315 |  |  | ballastDry | 309.5 |  | disp | 43 | m_app | 266.5 |  | mDry | 396
18:55:00 | 44 | 51 | 47.5 | 7
19:00:00 | 59 | 64 | 61.5 | 5 |  | 0:05:00 | 14.00 | 4.032
19:05:00 | 75 | 78 | 76.5 | 3 |  | 0:05:00 | 15.00 | 4.320
bell: | 81 | rodU | 5.5 | 86.5 |  | ballastDryAll | 23 |  |  | ballastDry | 17.5 |  | disp | 6 | m_app | 11.5 |  | mDry | 104
19:37:00 | 45 | 46 | 45.5 | 1 |  |  |  |  |  | 19:37:00 | 45.5
19:43:00 | 50 | 55 | 52.5 | 5 |  | 0:06:00 | 7.00 | 1.680 |  | 19:43:00 | 52.5
19:47:00 | 55 | 59 | 57 | 4 |  | 0:04:00 | 4.50 | 1.620 |  | 19:47:00 | 57.0
19:54:00 | 64 | 65 | 64.5 | 1 |  | 0:07:00 | 7.50 | 1.543 |  | 19:54:00 | 64.5
19:59:00 | 69 | 70 | 69.5 | 1 |  | 0:05:00 | 5.00 | 1.440 |  | 19:59:00 | 69.5
no filters
20:20:00 | 71 | 72 | 71.5 | 1 |  |  |  |  |  | 20:20:00 | 71.5
20:25:00 | 77 | 77 | 77 | 0 |  | 0:05:00 | 5.50 | 1.584 |  | 20:25:00 | 77.0
restarted
20:35:00 | 61 | 56 | 58.5 | 5 |  |  |  |  |  | 20:35:00 | 58.5
20:40:30 | 66 | 64 | 65 | 2 |  | 0:05:30 | 6.50 | 1.702 |  | 20:40:30 | 65.0
20:45:00 | 70 | 69 | 69.5 | 1 |  | 0:04:30 | 4.50 | 1.440 |  | 20:45:00 | 69.5
20:50:00 | 76 | 74 | 75 | 2 |  | 0:05:00 | 5.50 | 1.584 |  | 20:50:00 | 75.0
bell: | 81 | rodU | 5.5 | 86.5 |  | ballastDryAll | 308 |  |  | ballastDry | 302.5 |  | disp | 42 | m_app | 260.5 |  | mDry | 389
21:40:00 | 33 | 35 | 34 | 2 |  |  |  |  |  | 21:40:00 | 34.0
21:45:00 | 49 | 51 | 50 | 2 |  | 0:05:00 | 16.00 | 4.608 |  | 21:45:00 | 50.0
21:50:00 | 64 | 66 | 65 | 2 |  | 0:05:00 | 15.00 | 4.320 |  | 21:50:00 | 65.0
21:55:00 | 79 | 81 | 80 | 2 |  | 0:05:00 | 15.00 | 4.320 |  | 21:55:00 | 80.0
bell: | 81 | rodU | 5.5 | 86.5 |  | ballastDryAll | 745 |  |  | ballastDry | 739.5 |  | disp | 100 | m_app | 639.5 |  | mDry | 826
22:29:00 | 43 | 50 | 46.5 | 7 |  |  |  |  |  | 22:29:00 | 46.5
22:34:00 | 68 | 73 | 70.5 | 5 |  | 0:05:00 | 24.00 | 6.912 |  | 22:34:00 | 70.5
22:35:30 | 80 | 77 | 78.5 | 3 |  | 0:01:30 | 8.00 | 7.680 |  | 22:35:30 | 78.5
 |  |  | #DIV/0! | 0 |  | -0.9413194444 | #DIV/0! | #DIV/0! |  | 0:00:00 | #DIV/0!
bell: | 81 | rodU | 5.5 | 86.5 |  | ballastDryAll | 745 |  |  | ballastDry | 739.5 |  | disp | 100 | m_app | 639.5 |  | mDry | 826
22:57:30 | 41 | 49 | 45 | 8 |  |  |  |  |  | 22:57:30 | 45.0
23:01:00 | 64 | 58 | 61 | 6 |  | 0:03:30 | 16.00 | 6.583 |  | 23:01:00 | 61.0
23:04:00 | 72 | 76 | 74 | 4 |  | 0:03:00 | 13.00 | 6.240 |  | 23:04:00 | 74.0
23:04:50 | 80 | 77 | 78.5 | 3 |  | 0:00:50 | 4.50 | 7.776 |  | 23:04:50 | 78.5
P1, _8.6m ID4mm
bell: | 81 | rodU | 5.5 | 86.5 |  | ballastDryAll | 745 |  |  | ballastDry | 739.5 |  | disp | 100 | m_app | 639.5 |  | mDry | 826 | 826 | 726
23:20:30 | 46 | 54 | 50 | 8 |  |  |  |  |  | 23:20:30 | 50.0
23:23:30 | 60 | 65 | 62.5 | 5 |  | 0:03:00 | 12.50 | 6.000 |  | 23:23:30 | 62.5
23:26:30 | 74 | 78 | 76 | 4 |  | 0:03:00 | 13.50 | 6.480 |  | 23:26:30 | 76.0
 |  |  | #DIV/0! | 0 |  | -0.9767361111 | #DIV/0! | #DIV/0! |  | 0:00:00 | #DIV/0!
P2, 2x1.5 w/filters
bell: | 81 | rodU | 5.5 | 86.5 |  | ballastDryAll | 308 |  |  | ballastDry | 302.5 |  | disp | 42 | m_app | 260.5 |  | mDry | 389 | 389 | 347
23:49:00 | 47 | 41 | 44 | 6 |  |  |  |  |  | 23:49:00 | 44.0
23:52:00 | 55 | 52 | 53.5 | 3 |  | 0:03:00 | 9.50 | 4.560 |  | 23:52:00 | 53.5
23:55:00 | 60 | 64 | 62 | 4 |  | 0:03:00 | 8.50 | 4.080 |  | 23:55:00 | 62.0
23:58:00 | 70 | 73 | 71.5 | 3 |  | 0:03:00 | 9.50 | 4.560 |  | 23:58:00 | 71.5
P1, 2x1.5 w/filters
bell: | 81 | rodU | 5.5 | 86.5 |  | ballastDryAll | 23 |  |  | ballastDry | 17.5 |  | disp | 6 | m_app | 11.5 |  | mDry | 104 | 104 | 98
0:17:00 | 60 | 59 | 59.5 | 1 |  |  |  |  |  | 0:17:00 | 59.5
0:20:00 | 60 | 65 | 62.5 | 5 |  | 0:03:00 | 3.00 | 1.440 |  | 0:20:00 | 62.5
0:23:00 | 70 | 61 | 65.5 | 9 |  | 0:03:00 | 3.00 | 1.440 |  | 0:23:00 | 65.5
0:26:00 | 64 | 72 | 68 | 8 |  | 0:03:00 | 2.50 | 1.200 |  | 0:26:00 | 68.0
rung testing all sensors, bell at 60mm
bell: | 81 | rodU | 5.5 | 86.5 |  | ballastDryAll | 23 |  |  | ballastDry | 17.5 |  | disp | 6 | m_app | 11.5 |  | mDry | 104 | 104 | 98
 | 0+ | 0- | 1+ | 1- | 2+ | 2- | 3+ | 3- | 4+ | 4-
bell: | 81 | rodU | 5.5 | 86.5 |  | ballastDryAll | 23 |  |  | ballastDry | 17.5 |  | disp | 6 | m_app | 11.5 |  | mDry | 104 | 104 | 98
 | 0+ | 0- | 1+ | 1- | 2+ | 2- | 3+ | 3- | 4+ | 4-
Date | m_app @0submersion | submersion | P0H | P0L | P1H | P1L | P2H | P2L | P3H | P3L | P4H | P4L |  | P0H | P0L | P1H | P1L | P2H | P2L | P3H | P3L | P4H | P4L | P3H | P3L | P4H | P4L
2026-09-22 | 98.8 | 70 | 16:58:30 | 16:59:50 | 17:01:50 | 17:03:30 | 17:04:55 | 17:06:00 | 17:07:10 | 17:08:10 | 17:09:10 | 17:10:10 |  | 17:32:35 | 17:33:40 | 17:35:30 | 17:36:20 | 17:37:30 | 17:39:02 | 17:40:00 | 17:41:00 | 17:42:30 | 17:43:30 | 18:08:10 | 18:10:00 | 18:11:30 | 18:12:30
2026-09-23 | 174 | 70 | 17:17:12 | 17:18:34 | 17:20:53 | 17:24:01 | 17:25:40 | 17:26:48 | 17:28:46 | 17:29:50 | 17:31:45 | 17:34:04 |  | 18:00:24 | 18:03:02 | 18:05:15 | 18:07:35
2026-09-22 | 244.7 | 70 | 20:01:19 | 20:07:52 | 20:09:47 | 20:11:19 | 20:17:20 | 20:20:07 | 20:22:34 | 20:23:57 | 20:26:19 | 20:27:09
2026-09-23 | 346.7 | 70 | 19:11:47 | 19:14:58 | 19:16:58 | 19:18:27 |  |  | 19:19:48 | 19:21:03 | 19:23:05 | 19:25:10 |  |  |  | 19:32:01 | 19:33:02 |  |  | 19:34:40 | 19:38:03
2026-09-23 | 471.1 | 65 | 20:18:20 | 20:22:05 | 20:25:35 | 20:32:17 |  |  | 20:35:35 | 20:39:05 | 20:42:46 | 20:45:58 |  |  |  |  | 20:59:30
2026-09-23 | 471.1 | 70 | 20:19:45 | 20:23:20 | 20:26:47 | 20:33:40 |  |  | 20:36:59 | 20:40:20 | 20:44:07 | 20:47:18 |  |  |  |  | 21:00:53
2026-09-22 | 728.5 | 70 | 18:47:37 | 18:49:05 | 18:51:04 | 18:52:26 |  |  | 18:53:51 | 18:55:30 | 18:58:15 | 19:00:15 |  | 19:02:08 | 19:03:24 | 19:04:22 | 19:05:22 |  |  | 19:06:36 | 19:07:31 | 19:08:52 | 19:10:20

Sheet: ballasts
rung | dry weight total | w_disp @ 0mm submersion | m_app@0submersion
1 | 104.5 | 5.7 | 98.8
2 | 190.5 | 16.5 | 174
3 | 296.2 | 51.5 | 244.7
4 | 386.2 | 39.5 | 346.7
5 | 530.3 | 59.2 | 471.1
6 | 823.9 | 95.4 | 728.5

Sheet: lineR testing
 | section no | mm
 | 1 | 1538
 | 2 | 8550 | 10088 | 10.088
 | coupler | 2.4x27mm
Rung3(296.2g dry) | submersion | P0H | P2H | P2H
2026-09-24 | 65 | 14:13:10 | 14:21:33 | 14:48:35
 | 70 | 14:15:20 | 14:23:45 | 14:50:50
Rung6(823.9g dry) | submersion | P0H | P0H_LwLine | P0H_noFilterNoWand | P1H | P3H | P4H | P1H | P3H | P0H
2026-09-24 | 65 | 15:15:11 | 15:23:18 | 15:27:32 | 15:50:04 | 15:53:29 | 15:56:28 | 16:33:31 | 16:36:35 | 17:39:15
 | 70 | 15:16:22 | 15:24:27 | 15:28:40 | 15:51:08 | 15:54:39 | 15:57:34 | 16:34:39 | 16:37:48 | 17:40:18
 |  | 0:01:11 |  |  |  |  |  |  |  | 0:01:03

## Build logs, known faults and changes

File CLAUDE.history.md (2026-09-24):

# CLAUDE.history.md — KnurLogger

**Audit trail for the documents routed by `CLAUDE.md`.** Those current documents state what
is true now and what to do. This
file is the audit trail behind it: faults that were found and fixed, the diagnostics that found
them, decisions that were reversed, and requirements that were implemented and then deliberately
removed.

**Nothing here is a live instruction.** Current documents linked from `CLAUDE.md` win any
contradiction. Absence from a current document is not proof that a requirement was withdrawn;
check the recorded decision before reinstating or discarding it.

**Why the file exists.** Two reasons, and the second is the load-bearing one.

1. A fault whose *diagnosis* was expensive is worth recording even after the fault is gone, so the
   next silent bus or unregistered advertisement is not diagnosed from scratch. The reusable half
   of each of those — the command that splits the search space — stayed in `CLAUDE.md`; the
   incident is here.
2. **Git history and the plan's older revisions still describe retired requirements as live.**
   Deleting a requirement leaves nothing to read; a note saying "this was built, measured failing
   and dropped, and here is why" is what stops the next agent rebuilding it from a transcript.

Keeping all of that inside `CLAUDE.md` was burying the live traps in narrative, which is why the
file was split on 2026-09-10.

**When you add to it:** put the new conclusion in its current owning document and the superseded one here, with
the reason and the date. Do not leave "this used to say" narrative in `CLAUDE.md`.

---

## 1. Resolved faults, and the diagnostics that found them

### 1.1 The mux was silent because `~RESET` went to the wrong header pin

**2026-09-09, resolved** — resoldered and verified answering at `0x70`, control register `0x00`.

`~RESET` was soldered to header **pin 9 instead of pin 11**. Pin 9 is a ground pin and pin 11 is
GPIO17, and they are adjacent in the same row, so this is a one-position off-by-one onto the worst
possible neighbour: a PCA9548A held in reset does not degrade or partly work, it goes **completely
silent**, which is indistinguishable from an absent or dead part.

**The diagnostic that localised it** is the part worth keeping. `gpio=17=op,dh` is live in
`/boot/firmware/config.txt` and `pinctrl get 17` reads `17: op -- pd | hi` — so the Pi was
provably driving `~RESET` high while the mux end measured low, which puts the fault on the wire
rather than on the host or the part.

Two rules came out of it and are stated live in `CLAUDE.md`: check the Pi side with
`pinctrl get <n>` before suspecting a silent bus device, and do not try to fix a reset problem in
software — GPIO17 was already high, so no `pinctrl`/libgpiod write could have helped and one would
only have masked the diagnosis.

Build sheet §2 note 2 and the §3a.7 check table carry the meter checks, including the one that
**passes on a board with this fault** (`MUX_RST` ↔ `+3V3` still reads `R12`'s 10 kΩ).

### 1.2 `bluez 5.82-1.1+rpt1` on kernel `6.18.34` could not advertise at all

**Cost a day. Fixed by `apt full-upgrade` on 2026-09-09** → `bluez 5.82-1.1+rpt2`, kernel
`6.18.39`, `firmware-brcm80211 1:20260519`. If a future image regresses to those versions, this is
the explanation for a logger that starts, registers its GATT application and is never seen by
RaceChrono.

**The symptom** is `binc` logging `failed to register advertisement (error 36:
GDBus.Error:org.bluez.Error.Failed)` and `bluetoothd` logging
`add_client_complete() Failed to add advertisement: Invalid Parameters (0x0d)`.

**The cause is a userspace/kernel structure mismatch**, visible only in an HCI trace: the
`Add Extended Advertising Data (0x0055)` MGMT command arrives with `plen 14` while the fields it
declares — instance, `adv_data_len: 3`, `scan_rsp_len: 0` — account for 6 parameter bytes. The
kernel validates that length and rejects the mismatch. `Available adv data len` was 31, so it was
never a capacity problem.

The diagnostic sequence that found it is live in `CLAUDE.md`. Its step 3 (`btmgmt add-adv`, the
*legacy* MGMT path) succeeded throughout, which is what proved the controller and kernel could
advertise and narrowed the fault to `bluetoothd`'s extended-advertising path.

**Three plausible-sounding explanations were tested and were all wrong.** Recorded so nobody
spends the time again: it was **not** advertising-data overflow (a 4-character device name failed
identically), **not** `max_adv_data_len` (31, ample), and **not** connectability, daemon config or
stale daemon state (`ControllerMode = le`, `Experimental = true` and a `bluetooth` restart each
changed nothing).

### 1.3 The Bluetooth radio shipped soft-blocked, persistently

**Cleared 2026-09-09** by `harden-headless.sh` phase 7, and the unblock **survived the reboot**:
`rfkill list bluetooth` reads `Soft blocked: no`, `hciconfig` reads `UP RUNNING`, BlueZ reads
`Powered: yes` / `PowerState: on`. `systemd-rfkill` now restores *unblocked* from the same state
directory that used to restore the block.

As it shipped, `rfkill list` reported `Soft blocked: yes` and BlueZ `PowerState: off-blocked`.
**In that state there is no BLE and therefore no product.** Two traps, which is why `CLAUDE.md`
still carries the `rfkill block wifi` rule:

1. **`bluetoothctl power on` cannot clear it.** rfkill sits below BlueZ. The service runs, the
   controller enumerates, and it still refuses to power.
2. **It survives reboots.** `systemd-rfkill` saves per-device state under
   `/var/lib/systemd/rfkill/` and restores it at boot. `sudo rfkill unblock bluetooth` clears it
   and is persisted the same way.

### 1.4 The bare 1-Wire bus invented phantom devices, the set churned, and it stopped

With the overlay loaded and **the sensor zone unbuilt**, `/sys/bus/w1/devices/` held
`w1_bus_master1` plus a varying number of `00-*` entries whose IDs changed from scan to scan.
Measured 2026-09-09 across 35 s: first `00-800000000000` alone, then `00-dc0000000000` +
`00-3c0000000000`, then `00-3c0000000000` + `00-bc0000000000`, with `w1_master_slave_count`
reading `1`, `2`, `2` and `w1_master_attempts` already past 250 with nothing attached.

**With the sensor zone assembled, three scans over 36 s returned the master alone,
`slave_count = 0`, and no `00-*` at all.** `R11`'s 2.2 kΩ to `+3V3` is in the sensor zone, so
`GPIO4` no longer floats on the SoC's internal pull-up and the bus search reads a terminated line
instead of noise. Well-supported but not proven — nobody re-floated the line to confirm.

The consequence for the code is live in `CLAUDE.md`: the `28-*` family filter and its rules stay
mandatory, but they **can no longer be exercised on this box**, so their correctness now rests on
the parser rather than on an observation.

### 1.5 `initialiseBlePackets()` was called twice

**Removed 2026-09-10.** `raceChronoBleLoop` called it a second time after `main` already had. It
was harmless only while nothing produced a thermal reading: it re-runs `g_mutex_init` on live
mutexes and resets `0x602` to the all-invalid sentinel, so once `oneWireProbes` existed a real
reading taken before the BLE worker finished starting would have been silently clobbered back to
−327.68 °C. The rule that came out of it — initialise shared packet state in `main`, never in a
worker — is live in `CLAUDE.md`.

### 1.6 The box shipped accepting SSH passwords, and the public record of that is permanent

**Closed 2026-09-09** — `ssh-harden.sh --execute` ran and the box is key-only
(`passwordauthentication no`, verified by a forced password-only attempt being refused).

This is the worked example behind `CLAUDE.md`'s rule about measured-state notes. The statement
that the box accepted passwords was accurate and useful when written, and **git history is not
retractable**, so a public repository now carries a permanent record that this host once accepted
password authentication. It took a day to close; the next such note might not.

### 1.7 The BME280 answered at an address the build sheet forbade

The first scan of the assembled sensor zone found the BME280 at **`0x77`**, not the specified
`0x76`. It is a genuine BME280, not a mux at a strapped address — chip-ID register `0xD0` reads
`0x60`. The build sheet used to say "**Do not use `0x77`**" and put `U3.SDO` on `GND_SIG`; the
**owner amended the document rather than the board** (2026-09-09), so `0x77` is the specified
address now and is no longer free for anything else. No collision results, because the mux is
strapped to `0x70` alone and the "keep `0x77` clear of the mux range" reasoning only bites if a
mux is strapped upward.

### 1.8 An early `harden-headless.sh` draft disabled `wpa_supplicant`

Caught by the first real audit. `wpa_supplicant.service` is enabled and running on this image and
**NetworkManager drives it over D-Bus**; disabling it because "NetworkManager spawns its own"
loses Wi-Fi, which is the only way onto a box in a wheel-well cavity. The fact is stated live in
`CLAUDE.md`; this is the record that the mistake was actually made and shipped in a draft.

### 1.9 How the two halves of the I2C setup were told apart mid-run

`/dev/i2c-20` and `/dev/i2c-21` are the VC4 display DDC buses, and their appearance is what
diagnosed a missing `/dev/i2c-1`: loading `i2c-dev` before the reboot produced 20 and 21 but no 1,
because the `i2c_arm` adapter does not exist until the firmware re-reads `config.txt`. **Both
halves took on 2026-09-09** and `/dev/i2c-1` exists.

### 1.10 The apt pre-flight list was not a statement of what apt would change

`SystemSetup/install-dependencies.sh --execute` (2026-09-09) installed `i2c-tools`, `cmake`, `git`
and `libglib2.0-dev`; `rfkill`, `build-essential`, `nmcli` and `bluetoothctl` were already
present. That run also dragged the whole util-linux family forward from `2.41-5` to
`2.41.5-0+deb13u1` as a dependency — **`rfkill` among them**, despite the script correctly
reporting it present and skipping it. Nothing broke, but a four-package pre-flight list does not
bound the change.

---

### 1.11 The first enrollment at the car unplugged each probe as the next went in

**2026-09-10, at the car.** `--enroll` bound `temp0` = `28-06254385da1f`, `temp1` =
`28-0625424044b7` and `temp2` = `28-0625424e16c9`, and was then abandoned; the bindings were
deleted afterwards. They are in the `enrollment` records of
`2026-09-10T09-29-23.594215Z-enroll.ndjson` and nowhere else.

**Binding worked. Everything binding is *for* did not.** The procedure had said "plug them in one
at a time" and meant plug-in-and-leave; it did not say so, and unplugging as you go binds each
probe perfectly well, which is precisely why nothing complained. What it cost:

1. **The four-probe star was never loaded.** Plan thermal item 1's open acceptance criterion is
   all four enumerating together with CRC-clean reads on the 4 × 5 m bus, and the run has no
   bearing on it — three probes read singly is what the ESP32 bench rig had already done in
   2026-09-08. `temp2` alone was on the bus for the last 703 cycles.
2. **The warm-one-probe map check was impossible**, needing four live channels.
3. **It produced §1.12's 186 phantom read errors.**

`temp0`'s bind reading came back `INVALID (readFailed)`, which the run also had no way to follow up
on. The README now states plug-and-leave and gives all three reasons; `CLAUDE.md` requirement 3
rule 7 carries the rule.

### 1.12 A dropped lead was charged to the bus-quality counter for ~100 s per unplug

**2026-09-10, found by reading the session file from §1.11.** The channels showed contiguous runs
of `unparseable` — `temp0` cycles 360–434, `temp1` 387–462, `temp2` 410–444 — and each channel's
`readErrors` matched its `unparseable` count exactly: 75, 76 and 35, 186 in total, on a bus that
had not failed a single read.

**The diagnostic that identified it was the read duration, not the reason string.** `temp0`'s last
good read took 790 ms — a real conversion — and every read after it took 37–40 ms. Too long for a
cached value and far too short for a conversion, i.e. the kernel attempting a transaction and
getting nothing. That timing plus the run structure gives the mechanism: the kernel unregisters a
1-Wire slave only after `w1_slave_ttl` (10) missed searches at `w1_master_timeout` (10 s), so for
up to ~100 s after a lead comes out the sysfs directory is still there, `w1_slave` still reads, and
the content carries neither `crc=` nor `t=`.

`readProbe()` set `isPresent` the moment the file read succeeded, before looking at the content, so
the counting site's `isBound && isPresent && !isValid` charged all of it to `readErrors` and to
`0x603` byte 2–3 — the exact failure the code comment three lines above it forbids for `absent`,
arriving through the one path that still had a directory to read.

**Fixed** by splitting `notAnswering` out of `unparseable` on the presence of the two markers,
counting it in its own field, and recording the raw content (`unparsed`) so the next occurrence can
be told apart from a marginal bus without a trip to the car. `CLAUDE.md`'s family-filter list item
6 is the live rule.

### 1.13 `therm_bulk_read` existed for the first time, and refused the write 863 times

**2026-09-10, at the car.** `enroll.log` carried 863 identical
`OneWire: bulk read trigger refused` lines at 1 Hz and nothing else, burying the two `BOUND`
messages the run existed to produce.

**What the timing established.** The first warning is at 11:33:55 and the first bind is at
11:33:55 — the same second — with none before. `w1_therm` registers `therm_bulk_read` as a master
attribute only once a slave of its family attaches, so this was the attribute appearing for the
first time on this box, and the code path having its first execution ever. `CLAUDE.md` had recorded
it as untestable and shipped-unexercised on exactly that reasoning; the reasoning was right and the
path failed the moment it ran.

**The cause was not recoverable from the artefacts**, because `writeSysfsValue()` discarded
`errno`. The expected reason was `EACCES` — every writable attribute in
`/sys/bus/w1/devices/w1_bus_master1/` is `root:root` and the logger runs as `chrum`, which
`CLAUDE.md` had already predicted in the sentence about `w1_master_timeout` not being shortenable
without root. The fix reported `errno` once, into the session file as well as the console, and a
udev rule was deliberately **not** written against the guess.

**The next run confirmed it: `errno 13`, `EACCES`** (2026-09-10, second enrollment). Worth keeping
because the discipline paid nothing and cost nothing — the guess was right, and waiting one run to
check it turned a plausible fix into a known one for the price of a single log line. **It was also
not the whole fault: with the permission fixed the bulk read still does nothing — §1.14.** The rule that
followed is in `SystemSetup/`, and `CLAUDE.md` carries the two non-obvious things about it: it has
to match the slave's add event rather than the master's, and it is testable without a probe via
`w1_master_add`.

**The measured cost is real either way.** A per-probe read is 790 ms, so four probes is ~3.2 s per
cycle: plan thermal item 2's "start around 1 Hz" is **0.31 Hz** until the bulk path works.

### 1.14 The udev rule fixed the permission and the bulk read still did nothing

> **Its open question is answered in §1.15, and the answer is not the one this section expects.**
> Parasite power was wrong; the trigger was one byte short. Everything measured below still stands.

**2026-09-10, at the car, four real probes, 331 cycles.** With `therm_bulk_read` now writable the
trigger is accepted every cycle — and the cycle time did not move: **3190/3213/3309 ms** against
3198/3213/3281 before the rule, with **every probe still reading in ~800 ms** (790/799/860). If the
bulk path were working, at most the first probe would pay a conversion and the other three would
return the scratchpad in single-digit milliseconds. None of them did.

**The permission was necessary and not sufficient.** §1.13 diagnosed `EACCES` correctly and the
fix was right; it simply was not the whole fault. Worth stating plainly because the udev rule
passed its own test and the natural conclusion was that the job was done.

**What the owner spotted, and why it was the tell.** `0x603` bytes 6–7 — last conversion, ms — read
**0** on the phone. That is a field whose entire job is to show conversion cost, reading zero
during the most expensive part of the cycle. The cause was in this repository:

```
lastConversionMs = bulkWaitMs.has_value() ? *bulkWaitMs : slowestReadMs;
```

`bulkWaitMs` had a value whenever the **write** succeeded, so the moment the udev rule landed, the
0 ms bulk wait started masking the ~800 ms the probes were actually taking. **The fix that made the
write succeed is what made the reporting lie**, and without that 0 on the phone the dead
optimisation would have been recorded as working.

**Why the wait is 0 ms.** `triggerBulkConversion()` polled until `therm_bulk_read` read anything
other than `-1`, and broke on the first poll. The attribute reads `-1` while a conversion is
running, `1` when results are ready, and `0` when no device on the bus supports bulk reading —
so **breaking on "anything but `-1`" cannot distinguish "finished instantly" from "nothing was
triggered"**, and the code had no way to tell which had happened. It does now: the readback is
recorded as `bulkState` on every `temp` record.

**Not yet diagnosed, and the first suspect.** A bulk conversion of parasite-powered probes needs a
strong pullup that this bus does not provide, and `w1-gpio`'s `pullup` parameter is ignored on this
firmware. So `ext_power` per probe is the first thing to read — it is now dumped once into a
`probeCapabilities` record on the first cycle that sees any probe, alongside `resolution`,
`conv_time` and the master's `features`. **Read that record before theorising further.**

**Three fixes shipped, all of them reporting rather than behaviour:** `conversionMs` reports what
the cycle actually paid; `bulkConversion` means a conversion the kernel confirmed rather than a
write that succeeded; and a one-shot warning names the readback value when the trigger is accepted
but converts nothing. **The logger has always been correct and slow — none of this ever produced a
wrong temperature**, which is why it survived a day of being wrong about itself.

**Verification is worth recording because the usual harness could not do it.** The fake-sysfs tree
represents attributes as plain files, so `therm_bulk_read` reads back the `trigger` that was
written to it and the state machine cannot be exercised at all. The `conversionMs` fallback was
verified instead with a **FIFO** standing in for `w1_slave`, which makes a read block for a
controlled time: cycle 1 reported `conversionMs 385` against a slowest read of 385 ms, where the
old code reported 0.

### 1.15 The bulk read converted nothing because the trigger was seven bytes

**2026-09-11, diagnosed at the bench from the box's own journal, confirmed at the car.** §1.14 left
parasite power as the first suspect. It was wrong, and the instrumentation §1.14 shipped is what
disproved it: `probeCapabilities` reads `ext_power "1"` on all four probes, so a strong pullup was
never needed. `conv_time "750"`, `resolution "12"`, `features "0"`.

**The actual cause was one byte.** `therm_bulk_read_store` in `drivers/w1/slaves/w1_therm.c`:

```c
int ret = -EINVAL;
if (size == sizeof(BULK_TRIGGER_CMD))          /* sizeof("trigger") == 8 */
    if (!strncmp(buf, BULK_TRIGGER_CMD, sizeof(BULK_TRIGGER_CMD)-1))
        ret = trigger_bulk_read(dev_master);
if (ret) dev_info(device, "...unable to trigger a bulk read... err=%d
", ret);
return size;                                    /* ALWAYS size — never an error */
```

`writeSysfsValue` wrote `strlen("trigger")` = **7**, so the guard failed, `trigger_bulk_read()` was
never called, no slave was ever marked, and the attribute read back `0`.

**Why it was invisible for a day, which is the reusable part.** The store returns the write size
unconditionally and reports the refusal only with `dev_info`, so `write()` could not fail and
userspace had no signal at all. And **`echo trigger > therm_bulk_read` has always worked**, because
`echo` appends the newline — so every hand test of the interface looked healthy while the logger's
own write was being rejected.

**The evidence was already on the box and nobody had looked.** The kernel logged
`therm_bulk_read_store: unable to trigger a bulk read on the bus. err=-22` **once per cycle for the
whole at-the-car session**, 1725 lines still in the persistent journal. `-22` is `EINVAL`, and
`trigger_bulk_read()` cannot return it — it returns only `0`, `-ENODEV`, `-EAGAIN` or `-EINTR`. The
errno alone identified the guard. **Read `journalctl -k | grep <the sysfs store function>` before
theorising about a sysfs write that succeeds and does nothing.**

**Two further faults were queued behind it and would have survived the size fix.**

1. **`didConvert` was set only by observing `-1`.** `trigger_bulk_read()` does the whole
   `msleep_interruptible(t_conv)` inside the write, so `write()` blocks ~750 ms and the readback is
   already `1` when it returns. `-1` is only observable by a concurrent reader, and this worker is
   the only one — so the loop could never have recognised a conversion it did trigger, and would
   have kept printing "accepted the trigger but reported no conversion" with everything working.
2. **`waitMs` was clocked after `write()` returned**, so `conversionMs` and `0x603` bytes 6–7 would
   have read **0 ms** on a successful bulk conversion — the same fault §1.14 had just fixed for the
   per-probe path, reappearing through the other branch. The clock now starts before the write.

**Measured at the car, 2026-09-11, 123 cycles, all four probes** (session
`2026-09-11T17-11-40.934639Z`): `bulkConversion` true and `bulkState "1"` on every cycle,
`conversionMs` **762–790** for all four together against 799–863 *each* before, `cycleMs` mean 849,
cycle interval mean **1023 ms = 0.977 Hz** against 0.305 Hz, `validMask` 15 throughout, and **zero
CRC failures, zero `notAnswering`, zero unparsed content across 492 probe reads.** That last figure
is the one that mattered beyond rate: bulk reading takes the `read_scratchpad` path rather than
`convert_t`, a different bus transaction pattern, and the 4 × 5 m star took it cleanly. No
`therm_bulk_read_store` line anywhere in that boot.

**One reading that looks like a regression and is not.** `probeCapabilities.bulkReadState` still
reads `"0"` on a healthy box, because the record is emitted after the per-probe reads and reading
`w1_slave` consumes the ready flag. The authoritative field is `bulkState` in the `temp` records.

**A residual that the record cannot show.** `trigger_bulk_read()` marks every slave ready even when
its bus reset failed, so `bulkState "1"` proves the bulk path ran, not that the bus answered. What
separates them is `conversionMs`: a real conversion costs ~780 ms, a failed reset ~0 ms, and the
per-probe CRC verdicts catch the stale scratchpad either way.

## 2. Superseded decisions

### 2.1 "SD primary, BLE secondary" → BLE is the primary data path

**Reversed by owner decision, 2026-09-09** (plan item 5b). Do not reinstate it from memory or from
git history. The analysis record is RaceChrono's consolidated log, because RaceChrono is what
collects box 1's CAN broadcast, box 2's channels and the phone's GPS and stamps them into one
frame set on one timebase. The three narrower grounds on which the local file remains mandatory
are live in `CLAUDE.md`.

### 2.2 The accessory feed → constant 12 V

**Superseded by the box as built, 2026-09-10** (owner). Every document previously assumed an
accessory feed where **ignition-off is the power cut**. It is a constant feed: the logger runs the
whole day and the fuse is the off switch. The four consequences are live in `CLAUDE.md`; the one
worth restating here is that the ~1 s `fsync` requirement never changed — only its trigger moved.

### 2.3 "Never auto-apply a thermal offset" → offsets are applied to the RaceChrono feed

**Reversed by owner decision, 2026-09-10.** The objection was that an offset applied silently
cannot be un-applied later. It was put to the owner and answered on its own terms: it is neither
silent nor irreversible, because the session record carries the raw reading (`centiC`), the offset
in force (`offsetC`) and the value that actually went on the air (`sentCentiC`) side by side. A
mistyped offset costs a reprocess, not a session.

**That record-both property is the entire basis on which the reversal is safe** — anything that
later drops the raw value re-opens the original objection. `CLAUDE.md` states that as a live
constraint.

### 2.4 ROM-ID-keyed offsets in the store → slot-keyed in `KnurLogger.ini`

**Owner decision, 2026-09-10**, taken after the trade-off was put to them; they were briefly
ROM-ID-keyed. Do not "restore" ROM-ID keying. The binding store had no `offsetC` key after this,
and §2.7 later that day removed the store itself. The live consequence — an offset is a property
of one particular DS18B20, so re-enrollment in a different order or a swapped probe strands the
calibration — is in `CLAUDE.md`.

### 2.5 A session-start clock offset against the phone's GPS time

**Superseded twice over**, and its stated mechanism does not exist. RaceChrono stamps every source
on arrival, so box 1 and box 2 are never aligned against each other's clocks; and the RaceChrono
DIY protocol is device→phone notifications plus a filter-write channel, carrying no time transfer
to fetch a GPS time with. **Do not build a GPS-time fetch.** What survives is cheap, sufficient
and live in `CLAUDE.md`: every local record carries elapsed-since-boot alongside the wall clock.

The related misreading went with it: the two boxes' records are not reassembled by a session-start
time offset, they are reassembled by RaceChrono. The consequence that survived is sharper than the
one that went — see `CLAUDE.md` on what a BLE gap actually costs.

### 2.6 "The sensor zone is unbuilt, so an empty I2C scan and zero `28-*` devices are correct"

**Superseded 2026-09-09**: the zone is assembled, minus the pressure sensors. Every document in
both repositories said the zone was unbuilt and that those were the correct results, and the
acceptance criteria moved with the build. A missing `/dev/i2c-1` was never explained by "the
sensors are not built yet" either — that only ever explained an *empty scan*.

---

### 2.7 A separate `channels.ini` binding store → the bindings live in `KnurLogger.ini`

**Owner decision, 2026-09-10.** The store had been deliberately placed in the data directory,
beside the session files, on the reasoning that it was field state that had to outlive a rebuild
and `build/` is where a rebuild lands. The owner reversed it on a simpler ground: the logger's
configuration should not be scattered across several files, and the bindings being in git is
acceptable rather than a problem.

`channels.ini` no longer exists in any form. The bindings are `temp<N>RomId`,
`temp<N>BoundTaiUs` and `temp<N>BoundIso` in the `[thermal]` section of `KnurLogger.ini`,
machine-written by `--enroll` alongside the hand-entered offsets. **Do not rebuild the separate
store**, and do not restore the "field state must outlive a rebuild" argument from this file or
from git history — §2.8 is what answers it.

Two things the move gained that were not the reason for it. The slot-keyed offsets and the
bindings that decide which probe each slot holds are now three lines apart, so §2.4's live
consequence — a re-enrollment strands the calibration — is visible where it bites rather than
filed in another file. And a ROM ID can be typed in by hand, which the machine-written store never
invited; the `28-*` family filter and the one-probe-one-channel rule apply on load either way.

The one thing it cost is that enrollment now rewrites a file a human maintains. It does so line by
line rather than through `g_key_file_to_data()`, which destroys non-ASCII characters in comments —
measured the same day, the em-dashes in that file's header came back as `?`. That is a live rule in
`CLAUDE.md`, not history.

### 2.8 One `KnurLogger.ini` on the box → a git-tracked template and a production copy in `~/bin`

**Owner decision, 2026-09-10, taken as the consequence of §2.7.** With the bindings in
`KnurLogger.ini`, a single copy on the box would have meant the `tar`-over-ssh build loop —
which overwrites everything under `~/KnurLogger` — silently discarding a trip to the car, not just
a hand-typed offset. That trap had been documented and worked around by discipline
(`--exclude=build/KnurLogger.ini`, or copying the file back before the next sync); the stakes made
discipline the wrong answer.

The logger is now built in `~/KnurLogger/build/` and run from `~/bin/`, installed by
`SystemSetup/deploy-logger.sh`, which always replaces the binary and only ever creates the `.ini`.
`KnurLogger.service` was pointed at `/home/chrum/bin/KnurLogger`.

**Do not reinstate the single-copy arrangement, and do not reinstate the `--exclude` workaround** —
there is nothing left to exclude, because the file the sync overwrites is now a template nothing
reads. The cost of the split is that the production `.ini` is outside git, so §2.4's "the
calibration ends up version-controlled" now depends on copying it back into the repo deliberately
rather than on the file being tracked where it sits.

## 3. Retired requirements — do not rebuild these

### 3.1 The session-start cold-soak thermal sample

**Retired whole by owner decision, 2026-09-10, after being implemented.** The
`commonTemperature` record, the `settling*` config keys and the drift fit are all gone. Git
history and plan revisions up to rev 71 still describe it, so this note exists to stop the next
agent rebuilding it from either.

**Why it went, because the reasoning is worth more than the feature.** The requirement was to
*flag* whether the car looked settled rather than assert it, and settledness was inferred from
each probe's drift rate across a 90 s window. That inference does not work, and it was measured
failing: a car parked ~5–6 h drifts about 11 mK/min, which over 90 s is ~18 mK against the
DS18B20's 62.5 mK code step — so **zero code transitions, a fitted drift of exactly 0.0 mK/min,
and `spreadUsable: true`** while the bay still held an 810 mK real gradient that would have gone
straight into ΔT_preheat.

Note what that rules out: **no threshold fixes it**, because the reported drift is exactly zero
rather than merely small, and resolving 11 mK/min needs a 20–30 minute window, which is not a
session start. Drift *rate* and level *gradient* are independent quantities, and inferring "no
gradient" from "no drift" was the error.

**Nothing is lost by dropping it.** Every session already logs all four probes' absolute readings
at 1 Hz, so a cold soak the owner *knows* was a cold soak is still fully derivable from the
ordinary `temp` records by hand. What went was the automatic 90 s summary and its unreliable
verdict, not the calibration.

### 3.2 The binding store's per-probe `offsetC` key

Carried from the store's first version, on the reasoning that thermal item 1 needed somewhere to
put offsets and retrofitting the field later would be a format change. **Retired by owner
decision, 2026-09-10**: the key is gone from the store rather than left dead, because two fields
that look like an offset, one of which does nothing, is worse than one. See §2.4 for where the
offsets went.

## 2026-09-10 — the first road test, and the frozen phone

The first road test connected RaceChrono, received one set of frames — sometimes only a partial
set — and then froze: the app held that frame set indefinitely and nothing further arrived.

**Root cause: the logger answered RaceChrono's subscription burst with an ATT error and lost the
whole burst.** Entering the logging regime, RaceChrono writes `deny all` and then one
`allow single` per configured channel. Recorded verbatim on the bench, in order: `0x7F0`, `0x420`,
`0x600`, `0x601`, `0x202`, `0x602`, `0x603`, `0x78`, `0x4FA`. Five of the nine are **box 1's CAN
frames** — RaceChrono asks every DIY device for the union of every packet ID it has channels for,
not for that device's own. The first command was `0x7F0`, which box 2 does not publish; the code
returned `BLUEZ_ERROR_REJECTED`; RaceChrono abandoned the remaining eight; and `deny all` had
already destroyed every notify timer. The phone then held its last frame forever, and the logger
looked connected and perfectly healthy from every angle.

**Why CAN-bus test mode worked and logging mode did not**, which is what the owner spotted and it
was the key to the whole diagnosis: test mode writes `allow all`, which carries no packet IDs and
therefore cannot be refused. The two regimes exercise different code, and only one of them had
ever run.

**Why nothing caught this earlier.** The ESP32 rig was the only prior proof of the protocol and its
own source says the filter is *deliberately not enforced* — it always notified everything. The
logger is the first implementation in this project that honours the subscription, so the path ran
for the first time on a moving car.

**The diagnosis was slower than it should have been, in a way worth recording.** A rejected filter
command produced no journal line and no session record, so the road-test file showed `deny all`
followed by nothing at all — indistinguishable from RaceChrono having gone quiet. Two hypotheses
were entertained and both were wrong: that the command lengths were mismatched (every observed
command matched the expected length exactly), and that the incoming packet ID was parsed with the
wrong endianness (`00 00 07 F0` big-endian is correct and matches the rig). **The fix that made the
diagnosis possible was recording every filter command raw before validating it**; the fault was
then visible in one bench connection.

**Comparing against KnurDash was decisive and also misleading for an hour.** KnurDash has the same
strict length checks and the same reject-on-unknown-frame, and it works daily — which briefly
argued the rejection could not be the cause. It works because the packet IDs RaceChrono asks for
are mostly its own; **it carries the same latent defect** and will fail identically the moment
box 2's IDs are requested ahead of its own.

**A second, independent defect found in the same comparison.** The BLE worker created its D-Bus
connection and adapter *before* pushing its main context thread-default, copying KnurDash's order.
KnurDash gets away with it because `gtk_main()` iterates the global default context; a headless
logger has no such loop, so `onPoweredStateChanged` and `onCentralStateChanged` never fired at all.
Every session file before this date is missing its BLE connect and disconnect records for that
reason — not because nothing connected. It also meant a link lost without an explicit unsubscribe
left `isNotifying` set and advertising unstarted. Fixed by pushing the context first; the connect
and disconnect records appeared for the first time on the next run.

**Measured after the fix:** RaceChrono subscribed to `0x600`, `0x601`, `0x602` and `0x603` by
packet ID and each notified at 0.98–1.00 Hz across a 57 s session, with the five unknown IDs logged
and ignored. `0x604` took zero notifications because no channel is defined for it — correct
behaviour under an honoured filter, and the reason the heartbeat channel needs defining before it
can serve as the liveness indicator it exists to be.

## 2026-09-11 — the same defect in KnurDash, and what it says about the two boxes

The reject-on-unknown-packet-ID fault was fixed in `KnurDash` as well
(`github.com/chrumck/KnurDash`, commit made on the box itself). It is recorded here because of
what it revealed rather than because this repository owns it.

**Box 1 was already suffering from it and the cause was a change to box 2.** RaceChrono keeps one
channel set and asks every DIY device for all of it, so the moment `0x600` and `0x601` were defined
for the logger, KnurDash started being asked for two IDs it does not publish — and refusing the
first one cost it every subscription behind it. Applying the captured burst to KnurDash's frames
predicts `0x7F0` and `0x420` live with `0x202`, `0x78` and `0x4FA` frozen, and the owner confirmed
from the car that some readouts were live and some frozen. **Neither box's symptom was traceable
to its own code changes**, which is the part worth remembering: the two repositories are
independent, the phone's channel set is not.

**One thing was deliberately not carried across.** KnurDash creates its D-Bus connection and
adapter before pushing its worker's main context thread-default, exactly as this repository did
before 2026-09-10 — but it is a GTK app whose `main.c` calls `gtk_main()`, so the global default
context is iterated and its adapter callbacks fire. Copying this repository's fix there would
change working behaviour for no reason. Its commit message says so, in case a future reader
notices the asymmetry and tries to "align" them.

**KnurDash's fix was compiled and committed but unproven** when this was written. Its CAN hardware
stayed in the car, so the binary restarted continuously on the bench and could not be exercised.
Both boxes went to the car together, and the entry below is the result.

## 2026-09-11 — the second road test: the fix holds, and the next three faults are on the phone

Both boxes connected to RaceChrono on a 143 s, 825 m drive (peak 80.6 km/h, 46 % of samples moving).
Box 2's session is `2026-09-10T22-47-40.448829Z-log.ndjson` — the name is stamped from the box's
wrong clock as usual and means nothing.

**The subscription fix holds on both boxes.** Box 2 was asked for the same nine IDs as before, in
the same shape (`deny all`, then nine `allow single` inside 400 ms), published four and **logged and
ignored the other five**. It sent 141/141/139/139 notifications on `0x602`/`0x603`/`0x600`/`0x601`
across 140 s connected; RaceChrono recorded 137/137/135/135, the shortfall being the tail after the
phone stopped recording, 4.5 s before the disconnect. **Both per-cycle counters advanced by exactly
+1 across every recorded sample — zero drops.** Notify intervals median 1001–1006 ms, max 1084 ms.
One connect, one disconnect, no supervision drops. **Box 1 kept all twelve of its channels alive to
the last sample**, which is the first time its fix has run against a phone.

**What the session proved about this code, beyond the filter.** `throttled` live and sticky both 0
over 559 s, no undervoltage — the supply worker's first run in a moving car, though in a cabin and
unloaded, so the SoC figures are not comparable with anything the enclosure will produce. The I2C
retry behaved exactly as characterised on the bench: **550 first-attempt failures, 550 recovered, 0
exhausted over 550 cycles**, one per sample cycle, with zero BME280 read errors. And `0x600`,
`0x601` and `0x603`'s channel equations are confirmed end to end, by decoding the RaceChrono
recording against this logger's record of the same samples.

**Three faults found, all of them on the phone.** `0x604` has no channel and was never asked for;
one of `0x602`'s four is `bytesToUint` where `bytesToInt` belongs; `0x601` bytes 6–7 has no channel.
`CLAUDE.md` §"The phone's channel list is part of the instrument" carries the live rules. The one
worth restating here is **how the signedness fault stayed hidden**: the same sentinel check passed
on 2026-09-09 reading −327.68 on all four, and the channel list is hand-edited between sessions, so
a check that passed once was quietly no longer true. Nothing in this repository can see it.

**Two method notes earned here.** The session-cycle counter appears in both records, so a
BLE-connected session aligns to RaceChrono exactly by joining on cycle number — no
cross-correlation, no lag, verified as logger `sessionUs 166.8` ↔ phone `t = 7.3 s`. And **the
session ended in a hard cut** — no `BLE stopped` event, no closing record — which is what a pulled
fuse looks like when reading a file back.

**What it did not do, and this is the part with a lesson in it.** No probes were attached, so there
is no `probeCapabilities` record and nothing for the bulk-read question. And **the box was on the
passenger seat** (owner, asked after the write-up): every reading from the session is therefore
void, `enclosurePressurePa` and `cavityTemperatureC` having measured the cabin, and the clean link
is a best case at ~0.5 m rather than evidence about a wheel-well cavity. Commissioning items 5a and
5.7 do not move.

**The code results survive that intact and the readings do not, which is the useful line.** The
filter behaviour, the notification accounting, the three phone-side channel faults, the equation
confirmation and the cycle-counter alignment are all properties of software and protocol; the cabin
exercises them as well as the cavity would. **A cabin pressure record was written up as a cavity Cp
point and withdrawn within the same session** — it was strongly speed-correlated and entirely
plausible. Nothing this repository logs distinguishes the two cases, and nothing it could log
would: `../ndLouvers/` Step 0b commissioning item 2 now requires the mounting state to be recorded
by hand, per session.

## 2026-09-11 — the phone's channel list, written down and made auditable

The three faults found by the second road test were fixed on the phone the same day: `0x604`
defined, `0x601` bytes 6–7 defined with that packet's slots renumbered 50–53 → 51–55, and the
unsigned thermal channel corrected. **None has been seen working yet**; `../ndLouvers/` open item 45
carries the verification.

**How the channel ids decode, which is what made the audit possible.** RaceChrono names each
channel's sample file after the channel's numeric id, and that id is `slot × 2²⁰ + channelType` —
Digital 70537, Temperature 70539, Pressure 70541, Percent 70547 for the four types this logger
uses. The owner supplied the slot names he had picked, and the decode matched field for field
across all sixteen channels, which turned rev 86's inference ("the second of the four, by field
order") into an identification: **`Temperature Front 2`**, i.e. `0x602` bytes 2–3, the `temp1` /
`T_core_in` slot.

**`Tools/rcz-channels.py` is that decode.** It flags a `Temperature` slot reading +327.68, which is
the sentinel decoded unsigned, and it *reports* a channel whose samples are all `NaN`. Run it on the
first recording after any edit to the phone's channel list.

**The all-`NaN` report was written as a fault flag and had to be demoted the same day.** Two of
KnurDash's channels come back empty in every recording, and the assistant read that as a
frame-length fault — `lowPass(E,254)` and `lowPass(F,254)` reference bytes 4 and 5 of `0x7F0` while
the four working channels on that packet use bytes 0–3, so "the frame is four bytes long" fitted
every observation. **It was wrong** (owner, 2026-09-11): RaceChrono renders a deliberate
out-of-calibration-range marker as no value, those sensors were out of range throughout, and the
channels are working as designed. **An empty channel and a mistyped equation are indistinguishable
in an export**, so the tool now reports rather than accuses. The general form of the mistake is
worth keeping: a hypothesis that explains every observation is not thereby correct, and this one
was reachable only by asking what the sensor was doing.

**Two things about slots that are easy to get wrong.** Changing a slot's *type* changes its id, so
`Digital Front 15` and `Temperature Front 15` are different channels and the old one survives unless
deleted — still subscribed, still decoding the same bytes under the old name. And **an old recording
carries the slot numbers that were in force when it recorded**, so a disagreement with `README.md`'s
slot map means the list has moved since, not that either is wrong.

## 2026-09-11 — the third road test: the installed position, and the phone's list finally verified

**The box was in the wheel-well cavity with the enclosure closed** (owner), four probes attached,
engine running — the first session in the position the box was built for. Export
`RaceChrono/20260911_200450_57_aleja_komisji_edukacji_narodowej.rcz`, 415.9 s, 2.68 km.

**The link result.** All three free-running counters — `0x603` bytes 4–5, `0x601` bytes 4–5 and
`0x604` byte 7 — stepped **exactly +1 on every sample**, with box 1 connected at the same time:
**zero dropped notifications over 415 s from inside the cavity.** Three times the second drive's
window, from the position that drive could not test. Probes enumerated 4 and valid-mask 15 on all
406 thermal samples, `0x603` and `0x601` read errors 0, bulk conversion 762–792 ms, thermal rate
0.977 Hz measured off the phone's own timestamps — matching the SD figure from §1.15 exactly.
Live throttle, sticky throttle and the undervoltage comparator all 0; core rail steady at 840 mV.

**Open item 45 closes, and HOW it closed is the part worth keeping.** Two of the three fixes were
proved by this recording: `0x604` decoded for the first time in its life, and `0x601`'s two check
values landed at 31 and 96. **The third could not have been proved by it.** `Temperature Front 2`'s
`bytesToUint`/`bytesToInt` fault is invisible above 0 °C, and every reading in the session was
between 15 and 46 °C — so the drive that verified two of the three was **structurally incapable**
of verifying the third. The owner verified it separately, with the sensor disconnected, where the
channel reads negative. **A test that covers most of a change can be silently blind to the rest of
it**, and the blindness is a property of the data range, not of the effort.

**A reading the assistant got wrong, corrected by the owner.** `T_ambient` falls 20.1 → 15.9 °C
across the session. That was written up as the probe shedding its own heat soak into the airstream
— an instrument artefact to discount. **It is a real ambient change: the garage is warmer than
outside.** The consequence inverts. Far from being an artefact, the session now contains the
garage-to-road step that plan commissioning item 4a has been asking for, with the CAN `0x420`
channel logged beside it. **Before calling a reading an artefact, ask what the car was doing** —
the logger cannot know it left a warm building and neither could the analysis.

**Not established by this session**, so it is not over-read later: no sustained speed (17 km/h
median, 83 km/h peak), no steering-lock or suspension-travel sweep, seat occupancy unrecorded — the
three residuals on plan item 5a. And **the loaded star has still never run hot, vibrating, or for
hours**; seven minutes on a cool September evening is the whole of its driven record.

## 2026-09-13/15 — the track day: the instrument holds up, and a CAN byte turns out to have been thrown away for five sessions

Two morning sessions at Tor Poznań, analysed 2026-09-15 from
`C:\_claude\RaceChrono\20260913_poznan_knurek_ae30.rcz`. The box was in the cavity behind the
**left** wheel well, enclosure closed, beside the i-ELOOP supercapacitor bank. The measurement
results belong to `../ndLouvers/thermals-testing.md` §3.9; what is here is what it says about this
repository.

**The logger came through its first real load case.** 41 minutes across the two sessions, 4 733
thermal cycles, and the loaded 4 × 5 m star had never before been exercised hot, vibrating or for
longer than seven minutes. Two single-cycle CRC failures on `temp3`, each flagged three independent
ways — valid-mask bit cleared, `0x603` bytes 2–3 incremented, `−32768` sent — which is the invalid-
data contract doing exactly what it exists for. Zero BME280 read errors. **Zero dropped
notifications on all three free-running counters, in both sessions.** The logger did not restart
across the 83-minute pit break: `0x601`'s cycle counter runs 3334 → 8269 against 4994 s elapsed, to
within 8 cycles, so one logger session spanned the morning as the constant-12 V feed intends.

**The sticky throttle byte is non-zero for the first time, and this repository cannot say when.**
`0x604` byte 1 reads **5** on every sample of both sessions — `undervoltage` and `throttled`,
latched since **boot** — while byte 0's live bits and byte 2's comparator read 0 throughout. So
nothing happened during either session, and something happened before the first one opened. **No
BLE record can ever date a latched bit**, which is the point worth keeping: `recordStickyTransitions`
timestamps the first transition of each bit and `startSupplyMonitor` records
`stickyAtSessionStart`, and **both exist only in the SD session file.** The relevant SD file is
still on the box. `../ndLouvers/` open item 48. The box is now powered through cranking and
build-sheet §10 step 3's crank watch was bypassed rather than passed, so cranking is the obvious
candidate and is not yet the established one.

**The expensive finding is not about this code at all.** `0x420` byte 7, the outside-air
temperature the plan's thermal item 4a is entirely built on, **has never had a RaceChrono channel
defined**. Box 1 forwards the frame whole and its byte 0 is the coolant channel, so the frame
arrives — but **RaceChrono stores decoded channels, not raw frames**, so the ambient byte was
discarded on arrival in every session so far and no recording can be reprocessed to recover it.

This is a fourth instance of the class the "phone's channel list is part of the instrument" section
records, and the worst-behaved one. **A DIY packet with no channel is never sent**, which is at
least symmetrical: the logger records `"supply": 0` and the gap is visible from either end — that
is how `0x604` was caught. **A CAN byte with no channel is silently dropped by the phone alone.**
Box 1 sent it, box 2 was never involved, and nothing in either repository or either logger's record
can detect the loss. `../ndLouvers/` open item 47, and the rule now in `CLAUDE.md`: *"box 1 already
broadcasts the frame" is a statement about cost, never about whether the data exists.*

**A tool defect found by the same analysis.** `Tools/rcz-channels.py` read only the archive root,
so on a session that was paused and resumed it silently reported the first stretch and discarded
the rest — half of this track day. Fragments are now enumerated and reported separately; they are
not merged, because a channel edited between stretches legitimately differs across them. **The
first run of the audit tool on this file was wrong and looked complete**, which is the failure mode
the tool was written to prevent in the phone's channel list and had in itself.

**And one earlier claim is corrected rather than extended.** Box 1's two `0x7F0` channels,
`lowPass(E,254)*4` and `lowPass(F,254)-50`, have been recorded here since 2026-09-11 as
all-`NaN`-by-design, out of calibration range. **They read normally on track** and are empty only
for the first 200–550 s of each session. The 2026-09-11 statement was right about those recordings
and wrong as a property of the channels — "empty" is a property of the session, and one recording
can never settle it.

## 2026-09-14/16 — the second track day: a 21.7-hour continuous run, and a zero that does not mean what it looks like

Six fragments from a wet-to-dry track day at Poznań, analysed 2026-09-16 from
`C:\_claude\RaceChrono\20260914_poznan_knurek_ae30.rcz`. The measurement results belong to
`../ndLouvers/thermals-testing.md` §3.10 — including the day's largest one, the cavity reaching
100 % RH with a zero dewpoint margin. What is here is what it says about this repository.

**The logger ran continuously across both track days and was never power-cycled.** 09-13's last
sample to 09-14's first is 78 182 s; the BME280 cycle counter reads 20 743 against 20 772 predicted
from the measured within-day 0.986 Hz — **29 cycles adrift over 21.7 hours, 0.04 %**. That is worth
recording twice over. It is the longest unattended run this box has done, by a wide margin over the
7.53 h bench run, and it happened with the fuse left in overnight, which is the failure mode
`CLAUDE.md` names as "a fuse left in for a week is a flat battery". One night is ~3.3 Ah of the
ND's ~45 Ah and is comfortable; the practice is now established rather than hypothetical.

It also fixes the shape of the sticky-latch question. `0x604` byte 1 reads **5** on every sample of
all five sessions, unchanged from 09-13, and since there was no reboot between them **the latch
predates a continuous two-day run.** The search window for `../ndLouvers/` open item 48 is older,
not newer, and only the SD file can narrow it.

**A zero read-error count is not evidence that every sample was valid.** One BME280 cycle on
2026-09-14 sent all three `0x600` values as their sentinels together, **`0x601` byte 0 dropped
31 → 3**, and `bmeReadErrors` stayed at 0 with `lastReadMs` normal. That is correct in every
respect — the transfer succeeded and the part reported a skipped measurement, which is not a read
error — but it means the health channel a reader reaches for first cannot see this case. **Byte 0
is the channel that says so**, and until this day it had never read anything but 31 in the field.
Both `CLAUDE.md` and `README.md` now say it at the point where the counter is described.

**Every thermal read error on record has happened with the car parked.** Seven appeared during
2026-09-14's pit breaks and **none during any of the five recorded sessions**; the counter is flat
inside all six fragments and steps only across the gaps. Adding 09-13's two, which fell inside that
day's stationary pit soak, that is nine of nine. **This is an observation, not a diagnosis** — the
breaks are unrecorded, so nothing here timestamps them and "parked" is inference from the pit
schedule. The SD record is the only thing that could turn it into a diagnosis, and it is still on
the box. Worth knowing before anyone reads a rising `0x603` bytes 2–3 as a driving-load problem.

**And rev 90's reading of the cavity Cp did not survive contact with more data.** Rev 90 recorded
the 09-13 sessions as corroborating the first drive without displacing it, on the argument that a
whole-session fit averages away the speed structure §3.6 found. The 09-14 sessions band by speed
and are **flat from 40 to 200 km/h**, so there is no structure to average away and the two records
contradict each other. `../ndLouvers/` open item 49 owns it. Nothing in this repository turns on
the answer: the channel is disqualified as a static reference at either value, which is the only
part `CLAUDE.md` and `README.md` need to state, and both now say so explicitly rather than implying
a settled number.

## 2026-09-17 — the pressure sensors arrive, and what that does and does not unblock

**The five SDP810s were delivered and are being fitted.** Every file in this repository that
described them as undelivered has been reconciled: `CLAUDE.md`'s hardware-facts bullet and its
bench-test note, `README.md`'s sensor-zone, pressure-companion and testable-today paragraphs, and
`Hardware/logger-perfboard-wiring.md`'s preamble, parts status and I2C-idle note. The plan's
Step 0b remains the authority on what any of it is for.

**What this repository has to get right at the bench**, recorded here because the fitting is
happening now and the consequences are not reversible in software:

1. **`F1` and `TVS1` are still unfitted, and the plan's risk 14 requires them before the sensors
   are connected.** Build-sheet §10 steps 2–3 were bypassed rather than passed, so the rail that
   will feed five new parts has never been on a meter. The parts line in §9 now says so where it is
   read rather than by cross-reference.
2. **The single ±125 Pa must be connectorised, not hard-soldered.** It is time-shared between two
   duties in different measurement phases, which is why the plan's open item 38 closed without a
   sixth sensor. Soldering it down reopens a purchase.
3. **One sensor per mux channel, each channel with its own pull-ups.** All five share one fixed I2C
   address and cannot be strapped apart; the mux does not pass pull-ups downstream.
4. **Record each serial against its mux position as it goes on.** The plan's commissioning item 2
   has the channel→role record as outstanding for the SDP810s, and the role→channel mapping itself
   stays deliberately open — do not invent one at the bench to fill the column.

**The first-transfer-after-idle deviation now gets its real test.** §1's refusal fault was measured
against the BME280 at `0x77` with a nearly empty bus. The five SDP810s sit behind the mux on the
same `SDA_MAIN`/`SCL_MAIN`, and a mux channel switch followed by a sensor read is two transfers of
which the first is the one after idle. Bringing them up is the first observation of that behaviour
at full device count. The retry counter is already in place to see it.

**A separate drift the same sweep caught.** The build sheet's §7 still said "the DS18B20s are not
fitted yet" — they have been fitted and enrolled since the four-probe star passed, and have since
run two track days. The hazard it guards is real and unchanged, so the check now reads as governing
any probe swap or re-fit rather than a first power-on.

## 2026-09-18 — the two-day SD record read on the bench, and three documented facts corrected

The box came back from the car to the bench, the service was stopped, and the 324 MB two-day
session file was read for the first time. It is the record the plan's open item 48 had been waiting
for. **Nothing in this entry is a live instruction** — the live versions are in `CLAUDE.md`,
`one-wire-probes.md`, `README.md` and `Hardware/logger-perfboard-wiring.md`.

**The session is 38.09 h, not 21.7 h.** `2026-09-11T18-08-06.244419Z-log.ndjson`, 404 573 records,
one continuous run spanning both track days; the 21.7 h in the earlier entry is the unattended
overnight stretch inside it. 13 BLE-connected windows, which are the 13 RaceChrono recordings — so
this file is also the only record of what the instrument did *between* sessions, and that turned
out to be where most of the findings live.

**1. "Two CRC failures" was wrong, and the mechanism is worth more than the correction.** All 17
samples that `0x603` bytes 2–3 counted across both days carry `crcOk = true` and the reason
`powerOnDefault`: `temp3` was passing through exactly 85.000 °C, which is also the DS18B20's
power-on scratchpad default, and the scratchpad is byte-identical in both cases
(`50 05 4b 46 7f ff 0c 10 1c`). There was never a bus error. **The loaded star recorded zero CRC
failures in 133 894 cycles**, which is a much stronger result than the one it replaced.
What made this findable only from the SD file: the phone sees a bare counter, so "two CRC failures"
was the only available reading of it and it was not checkable from the `.rcz`. The diagnostic that
settled it was dumping the four preceding samples of each flagged cycle — the flagged value sits on
a smooth ramp between neighbours ~60 mK away, which no reset can produce.

**2. `T_aft` runs far hotter than anything had recorded.** Peak **101.25 °C**; 2 351 samples above
85 °C; nine post-run heat-soak stretches of 170–400 s, of which **92 % fall between recorded
sessions** — which is why two track days of `.rcz` analysis never saw it. It also explains, rather
than undermines, the earlier "every read error happened parked" observation: the pit soak is what
drives the aft probe through the detector's threshold.

**3. The undervoltage latch is dated, and the cranking hypothesis is dead.** `stickyAtSessionStart`
is already 5 in the `supplyBaseline` record, which is written at `bootUs` 13.17 s — so both bits
were earned inside the first 13.2 s after kernel start, before the session opened, and neither
moved again in 38 hours. Sampling ten boots, two carry the latch and eight do not. A cranking dip
would have landed mid-session with `recordStickyTransitions` timestamping it, and none ever did.
This lands on commissioning item 5.4's supply margin rather than on the crank watch.

**4. The first-transfer-after-idle fault is bimodal per boot.** `CLAUDE.md` said "every time".
Reading `i2cFirstAttemptFailures` across all 32 sessions: most show exactly one failure per cycle,
**eight show exactly zero**, the 38-hour session among them at 0 in 135 146 cycles. A bench sweep
the same day found 0 refusals in 300 BME280 reads and 150 SDP810 reads at 2–1000 ms gaps. The
counter that was added so the retry would not become folklore is what exposed this; without it the
two modes are indistinguishable, because the retry hides both.
**A false alarm avoided by the same counters:** `i2cExhausted` is non-zero in two sessions (67 and
41). Both are confined to the first ~90 s with `present=false` — the BME280 physically off the
board during assembly work, with the service still running. `CLAUDE.md` names the check that
separates that from a degraded bus.

**5. The session ended cleanly.** `BLE stopped, 55447 notifications sent` — the first road session
on record that is not a hard cut.

**Two smaller things.** Eight BME280 measurements were skipped, not the one the `.rcz` showed; the
other seven fell between fragments. And one thermal cycle was abandoned 0.1 s before shutdown with
`therm_bulk_read=''`, engaging the per-probe fallback — a teardown race, and the first time that
fallback has run in the field.

**A record-keeping trap worth keeping.** `2026-09-11T17-11-40` and `2026-09-11T17-11-43` are named
2.3 s apart and are **different boots**: `bootUs` 13.2 s and 12.7 s, `stickyAtSessionStart` 5 and 0,
and a sticky bit cannot fall. Each boot restores the same saved clock and starts the logger ~13 s
later, so filename adjacency does not even imply the same boot.

## 2026-09-18 — the first SDP810 on the mux, and a bus hung by probing an empty channel

**`P0` reads.** After the owner rewired the channel-0 segment, `0x25` answers behind mux channel 0.
Identity `0x367C`/`0xE102` returns product **`0x03020A01`** (SDP810-500Pa) and serial
`0x000000009B994E22`, CRC clean on all six words; `0x3615` continuous mode returns the nominal
**60 counts/Pa** scale factor and reads −0.029 Pa mean, sd 0.010 Pa, on open ports at 26 °C. That is
inside the datasheet's 0.1 Pa zero accuracy and 0.05 Pa zero repeatability. **It qualifies nothing**
— there is no wand, tube or filter — and `../ndLouvers/pressure-testing.md` §3.1 says so at length.

**Probing empty mux channel 1 hung the whole bus.** With `P0` working, one read addressed to `0x25`
on channel 1 — empty, `R3`/`R4` not fitted — NAK'd, and every subsequent transfer on the **main**
bus then failed with `ETIMEDOUT`, mux and BME280 alike. The diagnosis was slow because every
cheap check said the bus was fine: `i2cdetect` still listed `0x70` and `0x77` (quick-write probes
still got ACKs), and `pinctrl get 2`/`3` showed `SDA` and `SCL` both **idle-high**, so the usual
stuck-low signature was absent. **A `~RESET` pulse on GPIO17 recovered it** — which is what `R12`
and net list row 12 exist for, and the first time that path has been used deliberately.

Two things to carry: this is build sheet §1's "misbehaves as you switch" warning arriving in
practice, so it is now stated as a prohibition in `CLAUDE.md` and §5; and **a hung bus can present
with both lines high and a clean `i2cdetect`**, so neither is evidence against it. A follow-up
sweep after recovery showed 2 of 12 BME280 reads failing, which looked like the idle-bus fault
returning and was not — it was the bus settling. Re-measuring properly gave 0 failures in 450
reads.

## 2026-09-19 — all five sensors on the mux, and a short that looked like an idle-clean bus

**Nothing in this entry is a live instruction.** The live versions are in `CLAUDE.md`, `README.md`
and `Hardware/logger-perfboard-wiring.md` §5.

All five SDP810s are fitted and read correctly — five distinct serials, CRC clean on identity and
measurement, nominal 60 and 240 counts/Pa scale factors returned, zeros within ±0.06 Pa on open
ports, and a 120-cycle round-robin of all five at 1 Hz giving **1 211 transfers with zero refusals,
zero exhausted retries and zero CRC failures**, a full five-sensor cycle costing 15.4 ms. That is
identity and liveness on bare sensors; nothing pneumatic exists, so nothing has been measured.

**Channel 1 was a real fault: `SD1` shorted to `SC1` at the mux** (owner found and fixed it).
Opening the channel took the entire main bus down — mux and BME280 alike, `ETIMEDOUT` on every
transfer — recoverable only by a `~RESET` pulse on GPIO17.

**The diagnosis is the part worth keeping, because every cheap check cleared the board.**
`i2cdetect` still listed `0x70` and `0x77`, since quick-write probes to those addresses still got
ACKs; and `pinctrl get 2`/`get 3` showed `SDA` and `SCL` **both idle-high** with the channel open,
so the stuck-low signature everyone reaches for was absent. Clean scan, both lines high, every
transfer failing is not a contradiction — it is the specific fingerprint of the two lines shorted
**to each other** on a downstream segment, because at idle both are simply pulled up and only the
first `SCL` edge reveals it. The hypothesis was put that way before the owner opened the board, and
continuity `SDA_CH<n>` ↔ `SCL_CH<n>` is the one-line check it implies.

**The second lesson is procedural: probe mux channels with a reset between each.** The first sweep
ran channels in order, hit channel 1, and reported channels 2, 3 and 4 as absent — three healthy
sensors written off by one bad channel earlier in the loop. Re-running with a `~RESET` pulse before
every channel found all four and localised the fault in one pass. Any bring-up scan should be
written that way.

**This is the second time the same symptom has appeared on the same channel** — 2026-09-18 with the
channel empty and `R3`/`R4` unfitted, 2026-09-19 with it populated and shorted. Different causes,
identical presentation, and `CLAUDE.md` now carries them as one trap because the recovery and the
diagnostic are the same.

**The ±125 Pa turned out to be on `P2`, not the specified `P4`.** The board won and the documents
were corrected; the part is connectorised so no copper changed and nothing was unsoldered. What
matters here is *how* it was caught: **the part identified itself** by returning product
`0x03020B01` and a 240 counts/Pa scale factor. Nobody read it off the board, and a reader that
trusted the header would have recorded a ±125 Pa part as a ±500 Pa one. `CLAUDE.md` now says to
identify an SDP810 by product number and to retain the returned scale factor per sensor.

**A harness bug worth recording because it mimics a hardware fault.** The first round-robin reissued
`0x3615` every cycle and lost **145 of its 150 start-continuous commands**, all exhausting the full
ten-attempt retry — which
reads exactly like a degraded bus. The arithmetic gave it away: 145 = 29 remaining cycles × 5
sensors, so every start-continuous after the first was refused. **`0x3615` is NAK'd if the sensor is
already in continuous mode, and a mux channel switch does not take it out of that mode.** Re-run
correctly, the same test produced zero failures. Recovered-versus-exhausted was the tell: the
idle-bus refusal recovers on attempt two, and these exhausted all ten.

**Open item 44 gained a device count and not an answer.** The round-robin boot was in the
non-refusing mode, so 1 211 clean transfers say nothing about the deviation. The full-device-count
test remains owed and can only be taken on a refusing boot.

## 2026-09-19 — the sixth worker: the five SDP810s into the logged and broadcast data

**Nothing in this entry is a live instruction.** The live versions are in `CLAUDE.md`, `README.md`,
`build/KnurLogger.ini`'s comment block and `pressure-worker-plan.md`'s Work Progress table.

`pressureSensors.cxx` was written against `pressure-worker-plan.md` and its eleven steps executed in
order. **It produces the channel, not a measurement** — no wand, tube or filter exists, so every
number it writes is of whatever air is at an open port. That distinction is now the easiest thing in
the project to lose, because the session files are full of plausible pascals;
`../ndLouvers/pressure-testing.md` §4 item 9 is where a future reader meets it.

**Four owner decisions gated it and all four recommendations were taken** — decipascals on all six
channels with `INT16_MIN`, a configurable rate shipped at 10 Hz, packets published before any role
mapping exists, and IDs `0x605`–`0x607`. They are recorded in `../ndLouvers/CFD-Learning-Plan.md`
Step 0b commissioning item 4a, which is where they belong: each changes what the data means, and this repository
owns no measurement decision. The IDs were checked against the committed
`RaceChrono/vehicleProfile.json` rather than asserted — across both boxes the only IDs claimed are
`0x78`, `0x202`, `0x420`, `0x4FA`, `0x600`–`0x604` and `0x7F0`, and **box 1 uses no DIY channel
slots at all**, so `Pressure Front 1`–`6`, `Digital Front 21`–`27` and `Temperature Front 21` are
free.

**The one thing the plan did not settle: the phone-side divide. It was decided, reversed, and
reversed back inside one day, and the round trip is the useful part.**

**The answer is `/10000`.** RaceChrono's Pressure channel stores kPa and the wire carries
decipascals, so ten thousand is the divide that makes the channel genuinely kPa — the same rule
`0x600`'s `/1000` follows. Full scale is 0.5 kPa, and the 45–90 Pa measurands this project exists
to resolve are 0.045–0.090, which a gauge set to bar renders as near zero.

**`/10` was tried because of that readout, and it does not do what it appears to.** The reasoning
was that dividing by ten puts pascals on the gauge, in the unit every requirement is written in.
**It does not: RaceChrono still believes the stored number is kPa and applies its own unit
conversion on top**, so 500 Pa stored as "500 kPa" is displayed as **5 bar**. Wrong unit *and*
wrong magnitude, where `/10000` is merely small. **A divide chosen to fight the app's unit handling
produces a number that means nothing** — the owner caught this, and it is the reason the shortcut
is now written up in `README.md` as something not to retry.

**Resolution was never the question, and it was measured rather than assumed.** The worry behind
the whole excursion was that a large divide would quantise the recording. It does not: RaceChrono
stores every sample as a **float64**. `Pressure Front 50` has run `/1000` in production since
2026-09-11, and its samples in the 2026-09-14 track export come back as `101.151`, `101.154`,
**`101.15000000000001`** — 8 bytes each, full IEEE-754 precision. A double would need a divide
around 10¹² before it noticed. So `/10000` costs **nothing** in the `.rcz`, which is the whole of
what the exported data depends on.

**What it does cost is the at-the-car eyeball on these six channels, and that is accepted.** Two
things soften it. **The sentinel check survives**, because it turns on the *sign* rather than the
magnitude — −0.0033 bar against +0.0033 bar. And the display unit is an app setting, not part of
the channel definition (`vehicleProfile.json` carries only `equation`, `pid` and `channelId`), so
if RaceChrono's pressure unit can be set per gauge, setting these six to kPa or Pa makes them
readable with no change to the equation at all.

**One thing the excursion dragged with it, and it would have failed silently.**
`Tools/rcz-channels.py` hunts the unsigned-decode sentinel by its *value*, so the `/10` variant
moved the pressure entry to `+3276.8` and moving back returned it to `+3.2768`. Had either move
been missed, the tool would have gone on reporting every pressure channel as healthy while checking
for a number that can no longer occur. The plan's steps 7 and 10 carry the figure too. **Any change
to that divide has to move all three**, and the file now says so at the constant — which is the one
durable thing the round trip produced.

**A latent gap in `Tools/rcz-channels.py` was found by writing the channels rather than by a
fault.** The tool checked the unsigned-sentinel decode on `Temperature` slots only, so the six new
`Pressure` channels — carrying the same sentinel through a different divide — would have gone
unchecked by the one instrument that can audit the phone's list without the phone. It now checks
both, and `Pressure Front 50` is deliberately exempt because `0x600`'s enclosure pressure is
unsigned by design. **That check matters more on the pressure channels than it did on the thermal
ones:** a negative differential is normal on half of them, depending only on which port the tube
lands in, so a wrong sign corrupts ordinary data rather than only the marker — the `Temperature
Front 2` fault was at least invisible only above 0 °C.

**A figure that had been stated two ways in six files was settled** (owner): the `0x3615` re-arm
harness lost **145 of its 150 start-continuous commands** — 30 cycles × 5 sensors — not "145 of 456
transfers". Both sentences read as the same statistic and named different denominators. All six now
name the denominator.

**Measured, one hour on the bench at 10 Hz with all five sensors and the service stopped:** 34 537
cycles at 9.594 Hz, valid mask 31 on every one, zero read errors, zero CRC failures, zero exhausted
transfers, zero dropped records, worst inter-cycle gap 120 ms, 20.2 kB/s. The three 1 Hz workers
were untouched — BME280 1 015/1 021 ms, 1-Wire 1 002/1 005, supply 1 017/1 024 — so a producer
writing ten times the rate did not starve the `fsync` cadence.
**"10 Hz" measured 9.594 Hz, and that is not lost samples.** Every worker schedules its next sample
from the time the current one starts and pays the poll granularity on top; the 1 Hz workers have
always run at 1 002–1 017 ms for the same reason. The cycle counter is exact across all 34 537.

**Open item 44 gained a second device-count run and still no answer.** `i2cFirstAttemptFailures` was
0 for the whole hour, so that boot was non-refusing, as every boot with all five fitted has been.
What the run did add is that **a 10 Hz cycle leaves the bus idle ~85 ms between cycles**, well past
the 10 ms threshold — so a faster sample rate is not a workaround for the deviation and must not be
reached for as one.

**The production `.ini` was the step most likely to break this in the car, and it was handled as
such.** `deploy-logger.sh` only ever *creates* the `.ini`, so a new config key never reaches
`~/bin/` by itself and the logger would have refused to start at the car on a missing
`pressureChannelsEnabled`. The production copy was diffed against the template first — the two
differed **only** in comment blocks and the new `[pressure]` section, no value line — then backed up
to `KnurLogger.ini.bak-20260919`, replaced, and the four ROM ID bindings re-read afterwards to
confirm nothing was lost.

## 2026-09-19 — the phone's list catches up: the pressure channels entered, and a CAN byte finally defined

**The last step of `pressure-worker-plan.md` that needed neither code nor a part is done.** The
pressure channels and their status fields were typed into RaceChrono and verified the same day:
the **sentinel check passed with the sensors disconnected**, every channel reading negative
−3.2768, and `0x606` bytes 4–5 advancing by exactly +1 per sample. `0x605`–`0x607` are now
subscribed and sent. **Step 10 item 5 is still outstanding** — `Tools/rcz-channels.py` against a
recording — so the step's acceptance is unmet: nothing has yet been decoded against the logger's own
session record of the same samples, which is the check that found all three 2026-09-11 faults.

**Two deviations from the slot map `README.md` had specified, and both were settled in the
documents rather than on the phone.** `0x607` byte 6 went into `Temperature Front 20` instead of
`Temperature Front 21`: slot 20 was free and satisfies the same clear-of-everything property, and
the alternative — deleting a channel and re-picking a slot by hand — is exactly the operation that
produced the `bytesToUint` fault on `Temperature Front 2`. **The profile is the authority on what is
entered and the README table is its readable view**, so the table moved. And **`Pressure Front 6`
was deliberately not defined**: `P5` is the unpopulated mux channel 5, so the field carries a
constant sentinel inside a packet that is subscribed for its other three channels, and the phone
simply discards two bytes. That is not open item 47's failure mode and must not be filed as one —
there the packet was invisible and the data existed.

**`0x420` byte 7 was defined at the same sitting**, as `H-40` on predefined channel 10031. That is
the outside-air temperature of `../ndLouvers/` open item 47, undefined since the project began.
**It recovered nothing**: five sessions of it stay gone, because RaceChrono stores decoded channels
and a `.rcz` has no raw-frame layer. The item stays open until a recording is audited through the
new channel, and §"The phone's channel list is part of the instrument" item 4 keeps its present
tense about the mechanism for that reason.

**A new trap came out of committing the re-export: a `git diff` of `RaceChrono/vehicleProfile.json`
is not a review of it.** RaceChrono emits `customChannels` in an order that shifts as entries are
added, so adding 14 channels produced **184 insertions and 86 deletions**, and an equation edited by
hand would have passed review unseen — the one fault class that file exists to catch. Comparing by
`(pid, channelId)` is the check. **Sorting the array was considered and rejected**: the committed
file is the export verbatim minus `localUuid`, and re-import has never been tested against any other
shape, so normalising it would trade a reviewable diff for an untested restore path.

## 2026-09-20 — the box is accepted as operational, and the bring-up programme is retired unperformed

**Owner decision, taken in `../ndLouvers/` and recorded here because it retires work this
repository's build sheet was carrying.** `../ndLouvers/CFD-Learning-Plan.md` risk 14, Step 0b
item 5 and open item 1a-ii own it; `CFD-Learning-Plan.history.md` §1 item 39af holds the full
reasoning for each retired check.

**What was retired.** Build-sheet §10 **steps 2, 3, 5 and 6** are closed **unperformed** — the
dummy-load bench with a meter at `TP2`, the crank-transient watch, and the mux/BME280/DS18B20
bring-up checks. `TVS1` (load-dump clamp) will **not be fitted** and has left §9's bill of
materials, along with `C1`. **`F1` is NOT among the retirements — it is FITTED**, at the car's
fuse box (see below). Plan item 5.3's continuous-draw measurement is
dropped, so the ~275 mA / 3.3–5 Ah estimate in `CLAUDE.md` is now permanent and must be labelled
as an estimate wherever it is quoted.

**The grounds.** This is a test-and-research installation rather than a production one, and the
board has since run a **38.09-hour continuous session** and two track days with the Pi and all
five SDP810s fitted and reading correctly. **The accepted consequence is explicit: a supply fault
destroys the whole rig.**

**Three things to know before "fixing" any of this.**

1. **The BYPASSED markers in §10 are now a record, not a task list.** They were live work through
   rev 104 and read exactly the same; only the banner above them says otherwise. An agent
   scheduling step 2 because it is marked bypassed would be re-opening a closed decision.
2. **`F1` IS FITTED AND WAS NEVER RETIRED — at the car's fuse box**, upstream of any cable routed
   to the logger, which is the source-end position it always specified (owner, correcting the same
   day, 2026-09-20). **An earlier draft of this entry listed it among the retirements and stated
   the feed run was permanently unfused; both are withdrawn as factually wrong.** The argument it
   satisfies: the module's onboard 1.5 A fuse protects everything downstream of itself and nothing
   upstream, so without `F1` the cabin-to-cavity feed run would be unfused over its whole length
   against a chafe-to-chassis short — a **fire** risk rather than a hardware-loss one, which is why
   it was argued separately from `TVS1` and called non-negotiable. **So when the entry above says
   a supply fault destroys the whole rig, that means a fault inside the rig: the feed run itself
   is protected.**
3. **One thing §10 steps 5–6 carried is NOT retired.** Open item 44's full-device-count test is a
   hardware question about the idle-bus refusal, not a bring-up step, and it still wants a
   **refusing boot** — every run with all five sensors fitted has landed on a non-refusing one.
   Keep logging `i2cFirstAttemptFailures` with every pressure session and state the mode, or a
   transfer-error investigation has no way back to whether the bus was refusing.

**Open item 48 closed with them, as permanently unanswerable.** The `0x604` byte 1 sticky-5 latch
is still real and still dated to the first 13.2 s of boot on 2 of 10 boots; what closed is the
margin figure behind it, since `TP2` will never be read. **What would reopen it is behavioural:**
the live throttle bits or the `rpi_volt` comparator moving *during* a run, rather than latching at
boot. Nothing has ever done that across 38 hours including all track running.

**Open item 52 was dropped the same day**, so the `T_aft` band-edge question is settled by
acceptance rather than by measurement: the probe runs to 101.25 °C, its accuracy above 85 °C will
not be bounded and the probe assembly's own temperature rating will not be checked. **Treat every
`T_aft` sample above 85 °C as an indication rather than a measurement, permanently, and do not
open a task to characterise it.** `one-wire-probes.md`'s `powerOnDefault` requirement is
unaffected — open item 53 is a software-behaviour question and stays open.

**And `3DPrinting/calibrationBell.md` is now ADOPTED rather than an option.** The bell is the
reference route for the pressure ladder (`../ndLouvers/pressure-testing.md` §2.2). **Adoption
changed nothing about what this repository may decide** — the file owns the fixture's geometry and
constants and owns no measurement decision, exactly as the build sheet does. **Adopted is not
built:** no bell exists and nothing has been weighed.

### The bell was built, and three of `calibrationBell.md`'s conclusions did not survive it (2026-09-20)

**Nothing here is a live instruction.** `calibrationBell.md` §"As built" owns the fixture's current
constants; `../ndLouvers/pressure-testing.history.md` §3.3 owns the session; open items 55 and 56 in the
plan own what is undecided.

A bell was printed from `calibrationBell.stl` and ran 53 minutes against logger channel `P0`.
Three statements this repository had been carrying were superseded by it.

1. **"Adopted is not built: no bell exists and nothing has been weighed."** A bell exists, weighs
   79 g, and delivered 26–32 Pa. `CLAUDE.md` said the same thing and has been corrected.
2. **The nominal constants.** `calibrationBell.stl` is a **bare** bell — ID 150.00, wall 0.90, no
   collar, no ribs, **no graduations**, no rod, no pan — not the rev F the file and drawing
   describe (ID 148.4, wall 0.80). **`k_d` nominal 0.2122 against 0.2627 as built, 23 %.** The
   session measured **0.2615 ± 0.013**, 0.1σ from the as-built figure and 1.9σ from the drawing's,
   which also showed the printed wall came out at 1.00 against 0.90 in its own STL: **a thin wall
   does not print to nominal, and `k_d` is proportional to it.** The drawing is not withdrawn — it
   describes a rev F bell nobody has printed — and the file's own "measure the finished part" rule
   is what caught this.
3. **"Bare, +0.041 N·m/rad, stable."** The bare bell capsized twice at 49–50 mm immersion and
   lolled 5–8° at 59–64 mm, which puts `GM` at ≈ −0.1 mm there and ≈ −6 mm at the capsize. The
   table's probable error is that it takes the righting couple about the **lid plane** instead of
   the **centre of buoyancy**, worth ~50 mm of righting arm the bell does not have — and the
   paragraph directly above it already says a constant-pressure source has almost no tilt
   stiffness, so the prose and the table disagree and the bench agrees with the prose. **The model
   was deliberately NOT re-derived and the table was NOT rewritten**: that is the owner's call,
   recorded as plan open item 55. What went into the live file is the operating consequence, **do
   not run this bell bare**, and a warning that the loaded rows are unverified too.

Also added to the fixture's error budget, which had carried none of them: the **wetted-bell film**
(2.5 g, 1.2–1.4 Pa, decaying ~80 s after any handling — the owner diagnosed it, and the file's
before-and-after weighing cannot see it because the film is on the outside), the **skirt meniscus
force** (0 to ±3.9 Pa, hysteretic, unmeasured), and **tilt** (0.44 Pa at 10°, and silent in the
record). The measured make-up demand, **0.32 mL/s at ~28 Pa**, went into the operating sequence
against the file's unmeasured "order 1 mL/s at 500 Pa" — which the session showed cannot be scaled
from it in either direction, because the loss did not fall as the pressure fell.

The drawing's footer still read **OPTION NOT YET ADOPTED** four revisions after adoption; it now
names the as-built section instead.

### The bell's bleed turns out to be all sensor, and the line-loss test fails (2026-09-20)

**Nothing here is a live instruction.** `../ndLouvers/pressure-testing.history.md` §3.4 owns both sessions.

`calibrationBell.md`'s supply estimate — "of order 1 mL/s at 500 Pa" — is **superseded by ~5.5 mL/s**.
A leak test with the bell's full line, wand and filter connected but the sensor removed showed
**zero sinking in 10 minutes**, so the whole 0.32 mL/s bleed is the sensor's own bypass and the
circuit resistance is a measured **8.75 × 10⁷ Pa·s/m³** — 6× below the U-tube figure the old estimate
came from, which was taken at ten times full scale where the internal channel's flow is not laminar.
**The consequence for this fixture is that the bell lasts about four minutes per charge at 500 Pa**,
and the operating sequence now carries both figures.

The follow-up — 8.6 m of added tube, to measure how much of the reading the tubing costs — **failed**,
because the bare bell lolled and had to be corrected, and each correction is a positive transient.
**No number from §3.4b belongs in this file.** What it did strengthen is the case already recorded
here: the bare bell is not usable, and open item 55 has gone from a risk to a blocker.

### The bell's wall is 0.891 mm, and the caliper was read in the wrong place (2026-09-21)

**Nothing here is a live instruction.** `calibrationBell.md` §"As built" carries the current
constants; `../ndLouvers/pressure-testing.history.md` §3.5 is the session.

This file and §"As built" had `k_d` = 0.2627 from a 1.00 mm wall, on the strength of a caliper
reading and a five-point regression that agreed with it. **Both were wrong.** A ballasted run
against printed graduations inverts to `A_wall` = 422 mm², a **0.891 mm** wall — `calibrationBell.stl`'s
0.90 to within 1 %. **The caliper was read at the rim**, which is the first layer of a part printed
rim-down and is squished wider than the rest; this file's own print notes call that edge the sealing
face. `k_d` is now **0.2337 rod-less / 0.2372 with the rod**, and the earlier regression's
0.2615 ± 0.013 is withdrawn as 3σ out.

The supply figure moved again too: the circuit resistance is **2.29 × 10⁸ Pa·s/m³**, not the
8.75 × 10⁷ recorded the day before, so the bell needs ~2.2 mL/s at 500 Pa rather than ~5.5 and lasts
about ten minutes per charge there.

**What the fixture got right:** hanging the load is what made the run possible at all, and the
before/after weighing worked exactly as specified — 81 g against 79 g bare, the 2 g being the paper
and tape of the graduations, so no water was taken up.

### The bell's supply demand does not scale with pressure (2026-09-21)

**Nothing here is a live instruction.** `calibrationBell.md` §"As built" and the operating sequence
carry the current figures; `../ndLouvers/pressure-testing.history.md` §3.6 is the session.

This file recorded a single circuit resistance — first 8.75 × 10⁷ Pa·s/m³, then 2.29 × 10⁸ after the
ballasted run, with the earlier figure marked as withdrawn. **Both were right and the withdrawal was
wrong.** The sensor's internal bypass resistance **rises with flow**: 1.0 × 10⁸ at 0.28 mL/s against
2.3 × 10⁸ at 0.82. So the supply demand does not scale linearly with pressure, and the fixture's
"of order 1 mL/s at 500 Pa" cannot be scaled from a low-pressure observation in either direction.

The practical consequence for this fixture is that **the syringe or pump must be sized from the
high-flow end**, and that a bell run at the bottom of its range lasts longer per charge than a
linear extrapolation predicts.

### A false hardware alarm on `P4`, from reading cumulative counters as per-cycle (2026-09-21)

Session `2026-09-21T17-35-44` was first read as showing `P4` degrading: 2 972 read errors, the
same number of `i2cFirstAttemptFailures` and `i2cExhausted`, `i2cRecovered` stuck at zero, and the
error rate climbing from a third of the cycles in one minute to **100 % of cycles** for the last
hour of the session. That is `i2cExhausted` climbing while the device is present — the degraded-bus
signature `CLAUDE.md` says has never been observed — so a `~RESET` pulse and a continuity check on
`SDA_CH4`/`SCL_CH4` were recommended to the owner.

**None of it was real.** The counters in a `pressure` record are `appData.pressure.*` and
`appData.i2c.*` **cumulative session totals**, written into every record so that any single record
states which mode the boot was in. They were summed across 16 871 records. The two symptoms follow
mechanically: the sum multiplies the true count by roughly the record count, and a truthiness test
on a cumulative counter reports every record after the first error as "errored", which is what
produced the apparent climb to 100 %.

**The true figure is 3 read errors in 53 981 cycles**, all on `P4`, each recovered on the next
cycle: two at 19:59:39 and one at 20:18:05 — both moments when the rig was being handled, the first
being the instant the pressure line was plugged. `P0` was valid on every cycle of the session and
`validMask` was 31 on all but three.

**The owner restarted the box and stopped the service, and a bench probe confirmed it.** Main bus
clean with `0x70` and `0x77` answering and both lines idle-high; all five mux channels selecting
and reading back correctly with a `~RESET` between each; all five product numbers and serials
re-read over I2C and **matching `Hardware/logger-perfboard-wiring.md` §5 exactly** —
`0x03020A01` on `P0`/`P1`/`P3`/`P4` and `0x03020B01` on `P2`. A 300-cycle round-robin over all five,
1 500 select-plus-readback-plus-read triples at 11.2 Hz, returned **zero first-attempt failures and
zero exhausted transfers**. That boot was in the non-refusing mode, so it says nothing about open
item 44.

**Two things to carry.** The counter semantics are now a trap in `CLAUDE.md`, including the fact
that `appData.i2c.*` is shared by all three I2C workers, so a count taken from one worker's records
is a whole-bus count. And `i2cRecovered = 0` alongside `i2cExhausted > 0` is not a contradiction to
explain away: on a non-refusing boot nothing needs recovering, so the rare failure that does occur
exhausts outright rather than recovering on the second attempt.

## 2026-09-23 — the SDP810s are hard-soldered, and a documentation review of both repositories

**"The ±125 Pa is connectorised, so no copper changed" was wrong** (owner): all five SDP810s are
soldered directly to the perfboard with no `J7`–`J12` headers. `CLAUDE.md`, the build sheet (§3a,
§8, §9) and `../ndLouvers/` all said otherwise. The `P3`/`P4` swap proposed the same day went with
it; `P4` is inspected and watched instead. The build sheet's "must be CONNECTORISED" now reads as
required and not done, and whether that requirement stands is `../ndLouvers/` open item 38.

**The review** (`../ndLouvers/CFD-Learning-Plan.history.md` §2, rev 119) changed this repository
as follows:
1. **`Tools/bell-marks.py` was on withdrawn constants** — `k_m` 0.5551, `k_d` 0.2372, `A_eff` 17 671,
   no barometric factor — so any reduction through it read ~6 % off, and its docstring cited
   `pressure-testing.md` §3.15, which no longer exists. It now carries `k_m` 0.5639 and `k_d`
   0.2414 (the M3 rod hangs from the bell, so `k_d` includes it), reads `P_abs` from the session's
   `enclosure` records, fits the 60 s window ending at each mark and takes `Q` from the charge's own
   un-pinch point; `R_PATH` defaults to the ladder's short leg.
2. **The build sheet moved from `Hardware/` to `SystemSetup/` and ~30 links did not follow** — one of
   them in a `config.cxx` runtime error message.
3. **A build that adds a required ini key crash-loops the production logger**, since `config.cxx`
   exits on a missing key and the deploy never updates `~/bin/KnurLogger.ini`. The only record of
   the hand-merge was `pressure-worker-plan.md` step 8; README and `CLAUDE.md` now carry it, ahead
   of the pressure correction that will add keys.
4. **Rev 105's retirements** (crank watch, `TP2`, §10 steps 2, 3, 5 and 6) and item 1c's closure
   were carried into the build sheet, the setup runbook, `CLAUDE.md`, README and the BME280's
   role strings, which also moved the cavity thermometer to item 1d and gave humidity its
   measurement consumer. Comments and strings saying the idle-bus refusal happens "every time"
   now say bimodal per boot; the pressure sentinel comment said −327.68 Pa and is −3276.8 Pa.

## 2026-09-23 — the `powerOnDefault` check is removed

**Owner decision:** `oneWireProbes.cxx` no longer treats a DS18B20 reading of exactly 85.00 °C as
the power-on scratchpad default. It is accepted like any other temperature; the `powerOnDefault`
reason code and `dataContracts.hpp`'s `TEMP_POWER_ON_DEFAULT_CENTI_C` are gone.

**Why.** The check could not distinguish a hot probe from a reset one — the scratchpad is
`50 05 4b 46 7f ff 0c 10 1c` with a valid CRC either way — and the aft probe lives in the
80–105 °C band. In the two-day session `2026-09-11T18-08-06` it flagged 21 samples: four a genuine
all-probe reset in the first cycle after boot, 14.1 s in, and 17 `temp3`/`T_aft` transits through
85.000 °C with a good CRC, which its reason code and comment attributed to power or a marginal
pull-up. The owner prefers keeping every reading over flagging.

**Accepted consequence.** A genuine power-on reset now passes as a plausible, valid 85.00 °C
reading. Sessions recorded before this change keep their `powerOnDefault` flags, and in them
`0x603` bytes 2–3 counted the flags too. `../ndLouvers/` open item 53 is closed on it
(`../ndLouvers/CFD-Learning-Plan.history.md` §2, rev 120).

**Changed here:** `one-wire-probes.md` (the section on the check rewritten to the current state,
`powerOnDefault` dropped from the reason list and from the fake-sysfs harness's list), `CLAUDE.md`
(the 85.00 °C trap restated) and `README.md` (the two-day record's status paragraph, the `0x603`
byte 2–3 warning, the harness list).

## 2026-09-23 — `0x607` bytes 6 and 7 made to do what the README said, and the code stops citing documents

**Byte 7 could not do its job.** It published `lastSelectedChannel`, a channel NUMBER, with
`MUX_CHANNEL_NONE` (0) for "deselected" — so idle and "stuck on `P0`" were the same value — and the
packet was only built after the end-of-cycle deselect, so it could never read anything but 0 or
0xFF. A stuck cycle publishes nothing at all, and the notify timer never re-sends an unchanged
packet, so the README's "a value stuck on a channel number is a cycle that never finished" was
impossible. Now byte 7 is the mux CONTROL byte (0 idle, bit *n* for `P<n>`, 0xFF after a failed
deselect), set before each select, and the BLE worker publishes it itself when a cycle has run
longer than 1 s (`reportPressureStall`). The session record's `muxSelected` became `muxControl`.
**Byte 6 took the first VALID channel's temperature and sent 0 °C when none was valid**; it is now
the lowest enabled channel's, with −128 when that channel has no valid reading.

**The code no longer cites documents** (owner): plan and commissioning item numbers, section
numbers, Markdown paths and dated decision citations were removed from comments, strings, the ini
template, `Tools/bell-marks.py` and `SystemSetup/`, keeping the reasons. `pressureBaseline` lost
its `roleMappingNote` and `note` fields, the latter a hard-coded "no wand, tube or filter is
attached" written into every session including the bell sessions. In passing, `harden-headless.sh`
stopped calling the BME280 0x76, `install-dependencies.sh` stopped calling the SD card the primary
record, and `grant-w1-bulk-read.sh` — broken since `bc750f2` by a literal newline inside a `\n` in a
comment, so it failed `bash -n` — parses again.

## 2026-09-23 — `bell-marks.py` averages the 10 s before a mark

The owner replaced the bench rule: a mark is the instant the bell reaches its depth, the line is
pinched ~10 s later, and the stable sink before a mark can be well under a minute, so the reading
is the plain mean over the 10 s ending at the mark. The tool's 60 s straight-line fit reached back
into the charge (5–18 pp on the 2026-09-22 ladder). It also gained `Q_MLS`, because ladder marks
all sit at one depth and consecutive marks give no sink rate. Separately, "no measurement will
ever be taken" and "stays an estimate permanently" were softened to "none is scheduled" in
`CLAUDE.md`, README and the build sheet (owner).

## 2026-09-23 — Wi-Fi gating closed as manual

The open question "manual `nmcli`, or logger-owned?" had waited on plan item 5a's installed link
check, which closed on 2026-09-15 without answering it because no session recorded the radio
state. The owner closed it: the track sessions ran clean with Wi-Fi up, so gating is manual and
done only when diagnosing a BLE link problem. The `rfkill block all` prohibition is unchanged.

## 2026-09-24 — document restructuring

The owner requested an audit and restructuring of KnurLogger and ndLouvers. The router now
routes; implementation constraints, bus diagnostics, packet definitions, record interpretation
and operations have distinct owners. README no longer duplicates the outing-by-outing results
or a second backlog. The pre-cleanup text is preserved at commit
`facedc1c8734c9a13afc6a818c8978d16b1ef4b3`. No runtime behavior changed.

Do not rebuild the router incident catalogue. Read current owners through README or CLAUDE.md.
Measured pressure and thermal findings stay in their ndLouvers companions. The current pressure
correction handoff separates that unimplemented work from the completed acquisition worker.

The host runbook's dated correction log follows, moved intact into this existing trail. It is
historical evidence, not a second procedure. Current host instructions remain in the runbook.

### Host setup corrections
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

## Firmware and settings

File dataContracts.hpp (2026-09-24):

#pragma once

#include <sys/stat.h>
#include <fcntl.h>
#include <unistd.h>
#include <string.h>
#include <errno.h>
#include <dirent.h>
#include <sys/ioctl.h>
#include <linux/i2c.h>
#include <linux/i2c-dev.h>

#include <atomic>
#include <mutex>
#include <string>
#include <vector>
#include <array>
#include <optional>
#include <algorithm>
#include <chrono>
#include <cmath>
#include <filesystem>
#include <fstream>
#include <sstream>
#include <format>

#include <glib.h>
#include <glib-unix.h>
#include <gio/gio.h>

#include "adapter.h"
#include "advertisement.h"
#include "application.h"
#include "characteristic.h"
#include "device.h"
#include "logger.h"

namespace chr = std::chrono;

#define APP_VERSION "0.1.0"

#define CONFIG_FILE_NAME "KnurLogger.ini"
#define SESSION_FILE_EXTENSION ".ndjson"

#define CONFIG_GROUP_SYSTEM "system"
#define CONFIG_KEY_FILES_DIR "filesDir"
#define CONFIG_KEY_FSYNC_INTERVAL_MS "fsyncIntervalMs"
#define CONFIG_KEY_SUPPLY_INTERVAL_MS "supplyIntervalMs"

#define CONFIG_GROUP_THERMAL "thermal"
#define CONFIG_KEY_TEMP_INTERVAL_MS "tempIntervalMs"
// One per channel: temp0OffsetC .. temp3OffsetC. Keyed to the SLOT, not to the probe's ROM ID —
// see the note on TEMP_OFFSET_IMPLAUSIBLE_C.
#define CONFIG_KEY_TEMP_OFFSET_C_FORMAT "temp{}OffsetC"
// Machine-written by --enroll, hand-readable afterwards. `BoundIso` is provenance for a human and
// is never read back; `BoundTaiUs` is what the logger reads.
#define CONFIG_KEY_TEMP_ROM_ID_FORMAT "temp{}RomId"
#define CONFIG_KEY_TEMP_BOUND_TAI_US_FORMAT "temp{}BoundTaiUs"
#define CONFIG_KEY_TEMP_BOUND_ISO_FORMAT "temp{}BoundIso"

#define CONFIG_GROUP_BLUETOOTH "bluetooth"
#define CONFIG_KEY_BLE_DEVICE_NAME "bleDeviceName"

#define CONFIG_GROUP_SENSORS "sensors"
#define CONFIG_KEY_I2C_BUS "i2cBus"
#define CONFIG_KEY_BME280_ADDRESS "bme280Address"
#define CONFIG_KEY_BME280_INTERVAL_MS "bme280IntervalMs"
#define CONFIG_KEY_MUX_ADDRESS "muxAddress"

#define CONFIG_GROUP_PRESSURE "pressure"
#define CONFIG_KEY_PRESSURE_INTERVAL_MS "pressureIntervalMs"
// A LIST of populated mux channels, never a count. A count would say "channels 0..n-1", which is
// a claim about which channels are safe to address - and addressing an unpopulated one hangs the
// whole main bus (see the mux prohibition below). The list is what the sampling loop iterates, so
// a channel that is not in it can never be selected by accident.
#define CONFIG_KEY_PRESSURE_CHANNELS_ENABLED "pressureChannelsEnabled"
// Pa·s/m³, and global because every line on the car is cut from the same stock and carries the
// same filter, wand and port connector.
#define CONFIG_KEY_TUBING_RESISTANCE_PER_METRE "tubingResistancePerMetre"
#define CONFIG_KEY_LINE_FIXED_RESISTANCE "lineFixedResistance"
// Keyed to the slot, like the thermal offsets, although the span pair and the bypass fit belong to
// a particular SDP810: a sensor moved to another slot takes neither with it.
#define CONFIG_KEY_PRESSURE_SPAN_POSITIVE_FORMAT "p{}SpanPositive"
#define CONFIG_KEY_PRESSURE_SPAN_NEGATIVE_FORMAT "p{}SpanNegative"
#define CONFIG_KEY_PRESSURE_LINE_LENGTH_HIGH_M_FORMAT "p{}LineLengthHighM"
#define CONFIG_KEY_PRESSURE_LINE_LENGTH_LOW_M_FORMAT "p{}LineLengthLowM"
#define CONFIG_KEY_PRESSURE_BYPASS_COEFFICIENT_FORMAT "p{}BypassCoefficient"
#define CONFIG_KEY_PRESSURE_BYPASS_EXPONENT_FORMAT "p{}BypassExponent"

#define CONFIG_GROUP_DEBUG "debug"
#define CONFIG_KEY_VERBOSE_MODE "verboseMode"

// The RaceChrono DIY CAN-Bus device protocol, as implemented by KnurDash and by the ESP32 test rig.
// Both are bench-proven against the phone, so these are transcribed rather than chosen.
#define BLE_SERVICE_ID "00001ff8-0000-1000-8000-00805f9b34fb"
#define BLE_CHAR_ID_MAIN "00000001-0000-1000-8000-00805f9b34fb"
#define BLE_CHAR_ID_FILTER "00000002-0000-1000-8000-00805f9b34fb"

#define RACECHRONO_DENY_ALL 0x00
#define RACECHRONO_ALLOW_ALL 0x01
#define RACECHRONO_ALLOW_SINGLE 0x02

#define BLE_NOTIFY_INTERVAL_MIN_MS 5
#define BLE_NOTIFY_INTERVAL_MAX_MS 5000
#define BLE_SHUTDOWN_POLL_MS 500

#define CAN_FRAME_ID_LENGTH 4
#define CAN_DATA_SIZE 8

// Packet IDs are kept identical to the ESP32 rig's so that the RaceChrono channel definitions the
// owner already built against it carry over to this logger unchanged. 0x600 and 0x601 are the
// exception: on the rig they carried synthetic ramp/triangle test frames, and the owner released
// them for real use since that rig is spent. Anyone still holding the rig's 0x600 channel
// definitions must re-enter them - the bytes mean something else here.
#define PACKET_ID_ENCLOSURE 0x600
#define PACKET_ID_ENCLOSURE_STATUS 0x601
#define PACKET_ID_TEMP 0x602
#define PACKET_ID_THERMAL_STATUS 0x603
#define PACKET_ID_SUPPLY 0x604
// The three pressure frames, contiguous with the block above. Checked clear against the committed
// RaceChrono/vehicleProfile.json: across both boxes the only IDs claimed are 0x78, 0x202, 0x420,
// 0x4FA, 0x600-0x604 and 0x7F0.
#define PACKET_ID_PRESSURE_A 0x605
#define PACKET_ID_PRESSURE_B 0x606
#define PACKET_ID_PRESSURE_STATUS 0x607

// Signed 0.01 C/LSB, and INT16_MIN for a channel with no trustworthy reading. Deliberately absurd
// after the divide (-327.68 C) rather than plausible: a carried-forward value must never be
// presented as new, and RaceChrono holds the last value it received indefinitely.
#define TEMP_CENTI_C_INVALID INT16_MIN
#define TEMP_VALID_MIN_CENTI_C -5500
#define TEMP_VALID_MAX_CENTI_C 12500

// Calibration offsets are hand-entered in KnurLogger.ini, one per CHANNEL SLOT, and applied to the
// value sent to RaceChrono. Slot-keyed rather than ROM-ID-keyed is a deliberate simplification with
// one consequence worth stating: an offset is a property of a particular DS18B20, so **re-enrolling
// the probes in a different order, or swapping a probe, leaves the offsets pointing at the wrong
// parts and they must be re-checked.** In exchange the calibration lives in the git-tracked config
// beside every other setting, rather than in the data directory where a wipe would take it.
//
// A relative offset between two DS18B20s is a fraction of a kelvin, so anything past this is a
// decimal-point slip. Warned about and applied anyway; the hard bound below only rejects nonsense,
// because a logger that refuses to start in the car over a typo loses the whole session.
#define TEMP_OFFSET_IMPLAUSIBLE_C 5.0
#define TEMP_OFFSET_MAX_C 50.0


#define ONE_WIRE_DEVICES_DIR "/sys/bus/w1/devices"
#define ONE_WIRE_MASTER_NAME "w1_bus_master1"
// A DS18B20 is family 28. The bare bus invented churning `00-*` phantoms while the sensor zone was
// unbuilt and GPIO4 floated; they stopped once R11 terminated the line, but nothing may rely on
// that — matching the family code is the only thing that separates a probe from noise.
#define ONE_WIRE_DS18B20_PREFIX "28-"
#define ONE_WIRE_ROM_ID_LENGTH 15

#define TEMP_CHANNEL_COUNT 4
#define PRESSURE_CHANNEL_COUNT 6
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

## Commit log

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2026-09-09 Apply host setup to the box; record what --execute found
    First --execute runs: install-dependencies.sh then harden-headless.sh,
    reboot, and a re-audit diffed against a fresh before run.
    Boot 19.468s -> 11.105s. Bluetooth soft block cleared and it survived the
    reboot. /dev/i2c-1 and the 1-Wire master exist. No unit failed to mask.
    Corrections 25-29, none of which a static pass could have reached:
    - The bare 1-Wire bus lists a phantom 00-800000000000 and
    w1_master_slave_count reads 1 with nothing wired. Count 28-* only.
    The old acceptance called an empty directory the pass; empty is
    actually the failure, since a working bus registers its master.
    - Six of the nine units phase 3 claims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
2026-09-09 Channel enrollment and supply telemetry requirements; fix the w1 phantom
    Three owner decisions (ndLouvers rev 67a) put two new requirements on the
    logger, and re-probing the box corrected a finding from the last commit.
    Correction 30: the 1-Wire phantom is a churning set, not one device.
    Across 35s with nothing wired the bus gave 00-800000000000, then
    00-dc.. + 00-3c.., then 00-3c.. + 00-bc.., with the slave count reading
    1, 2, 2. The previous text supported "expect four probes plus one", a
    stable offset. The count is unstable and unusable, so 28-* matching is
    the only thing separating a probe from noise. Rescan is every 10s.
    New requirement: the logger binds temp0-temp3 by discovery order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
2026-09-09 Cold-soak calibration requirement; thermal channel mapping is pinned
    The four DS18B20s are installed on the car (ndLouvers rev 67b), which
    changes two things here.
    The thermal role->channel mapping is no longer undecided. Enrolled in
    installed order it is temp0=T_ambient, temp1=T_core_in, temp2=T_core_out,
    temp3=T_aft. Decided but not applied: enrollment needs a logger. The
    pressure mapping stays open.
    New requirement: record a cold-soak spread at session start. With the
    probes installed the bench cross-comparison is replaced by an in-situ
    common-temperature check, and the logger is what captures it. On a cold
    car at equilibrium all four probes are at one temperature, so the spread
    between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
2026-09-09 Correct the requirement count and bring README up to date
    CLAUDE.md said "Four requirements" while carrying five bullets - channel
    enrollment, the cold-soak spread and supply telemetry were added on top
    of the original two without updating the count.
    README still said the host setup had not been applied to the box and that
    nothing in SystemSetup/ had been run; both became false when the scripts
    ran. It also described the thermal role mapping as undecided, which
    installing the probes settled.
    Its Next section now says what is actually testable on the box with no
    sensor zone built - the build, config loading, the session writer, the
    supply-telemetry worker, and the 1-Wire phantom filter, who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
2026-09-09 Record the public upstream, the build-on-box workflow, and its one consequence
    Upstream is github.com/chrumck/KnurLogger and it is public. Two things
    follow.
    Workflow: the box has git 2.47.3, cmake and libglib2.0-dev, so the code is
    built on the Pi rather than cross-compiled. Clone once, pull thereafter.
    Do NOT put push credentials on the box - commit and push from the
    workstation and let the box pull only. A logger in a wheel-well cavity is
    physically exposed, so a PAT or writable deploy key on it is write access
    to this repo for whoever takes the car or the SD card. Public repos need
    no credential to pull, so read-only costs nothing. For a tight loop, copy
    the tree over rather than round-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
2026-09-09 Mark the SystemSetup scripts executable in git
    All four were committed as 100644, so a fresh clone gets them
    non-executable and ./script.sh fails with Permission denied - which is
    exactly what happened on the box. The local working copies looked fine
    because the Windows filesystem does not track the bit.
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2026-09-09 RaceChrono BLE worker; the advertising blocker was a BlueZ/kernel bug
    The logger now advertises as KnurLogger on service 0x1ff8 and RaceChrono can
    see it. ActiveInstances reads 1 while it runs, which is the acceptance.
    raceChronoBle.cxx carries the binc plumbing — adapter, advertisement, GATT
    application, notify timers — and blePackets.cxx carries the wire format. They
    are separate because in a single translation unit the worker that owns a reading
    has to be able to pack it, and supplyMonitor is included before the BLE worker;
    packing therefore cannot live downstream of its callers. The BLE worker runs its
    own GMainContext pushed thread-default with its own GMainLoop, which is
    KnurDash'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
    [case.stl, cover.stl, pcbHolder.stl]
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2026-09-09 DS18B20 enrollment worker, and thermal offsets applied to the BLE feed
    oneWireProbes.cxx completes the four workers: `28-*`-only enumeration, one
    probe per enrollment step, the channels.ini binding store, and the 0x603
    1-Wire status frame that was defined from the start and never sent.
    Two enrollment requirements the owner named that were not among the five in
    CLAUDE.md, and neither follows from the other five. A bound channel whose ROM
    ID goes absent logs as present-but-invalid rather than being omitted, because
    an omitted channel makes a mid-session dropout indistinguishable from the
    logger not having run - which is the one property the SD record exists for.
    And enrollment keeps sampling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
    [dataContracts.hpp]
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2026-09-10 Constant 12 V feed supersedes the accessory assumption; first long-run telemetry
    The box is wired to constant 12 V, not the accessory circuit (owner, as built).
    Every document here assumed an accessory feed where ignition-off is the power
    cut, and that changes the failure model rather than just a wire: the logger
    runs the whole day with the fuse as the off switch, it is powered during
    cranking for the first time, and battery drain becomes a real failure mode -
    comfortable over a day, a flat battery over a forgotten week.
    Two things follow that are decisions rather than notes. KnurLogger.service
    moves from convenient to REQUIRED, because nothing hand-starts the logger when
    the fuse goes in a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
    [KnurLogger.3mf, cableTab.stl]
2026-09-10 Split CLAUDE.md's history into CLAUDE.history.md
    CLAUDE.md had reached 514 lines, over half of them accounts of faults
    already fixed and requirements already retired, which buried the live
    traps. The split rule: CLAUDE.md keeps what to do and the one-line guard
    against reinstating retired work, CLAUDE.history.md keeps the reasoning
    behind the guard. Reusable diagnostics stay live -- the bluetoothctl
    advertise ladder, pinctrl before suspecting a silent device, the unshare
    fake-sysfs technique -- because their value survives the fault.
    Three drifts found by the sync pass and fixed: the host section still
    named kernel 6.18.34 while the BLE section recorded the 6.18.39 upgrade
    as the fix; pi-he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
2026-09-10 Bindings move into KnurLogger.ini; three faults from the first enrollment
    The first --enroll run at the car bound three probes and was abandoned. It
    advanced plan thermal item 1 by nothing, because the probes were unplugged one
    at a time as the next went in, so the 4 x 5 m star was never loaded. The
    procedure now says plug-and-leave, and gives the three reasons.
    Owner decision: the ROM ID bindings leave channels.ini for the [thermal]
    section of KnurLogger.ini, beside the slot-keyed offsets. One file holds the
    whole logger configuration, and a changed binding now sits three lines from the
    offset it invalidates. The store is gone rather than left dead.
    Enrollment therefore rewrites a hand-ma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
    [dataContracts.hpp]
2026-09-10 All four probes enrolled; the loaded 4 x 5 m star passes; EACCES confirmed
    Second enrollment at the car, with every probe left connected this time.
    temp0 28-06254385da1f T_ambient
    temp1 28-0625424044b7 T_core_in
    temp2 28-062542ac86b6 T_core_out
    temp3 28-0625424e16c9 T_aft
    63 consecutive cycles enumerated four probes with a valid-mask of 15 every
    cycle: zero read errors, zero CRC failures, zero non-probe entries, per-probe
    read 799-832 ms. That closes plan thermal item 1's first requirement, open since
    the ESP32 star run was deliberately skipped at rev 67a - R11's 2.2 kOhm pull-up
    carries the star as built, and the series-resistor and second-bus fallbacks are
    not needed.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
2026-09-10 Bulk-read udev rule applied and verified; fix the fake-id format in --verify
    grant-w1-bulk-read.sh --execute --verify from a login shell. therm_bulk_read
    comes up root:gpio 664 and chrum writes it, so thermal item 2's 0.31 Hz
    deviation should close on the next run.
    Should, not is. The verification registers a FAKE family-0x28 slave via
    w1_master_add, so it proves the rule fires on a slave attach and lands the right
    ownership - not that four real probes convert, nor that cycleMs falls. The
    confirmation is bulkConversion:true and a ~1000 ms cycle on a run with the
    probes connected, and the docs say so rather than reading a green PASS as
    "1 Hz confirmed". Every session recorded before today st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
2026-09-10 Doc sync before context clearing: stale per-probe figure, README lead
    Sync pass findings in this repo:
    - CLAUDE.md's live 1-Wire trap still quoted 790 ms per probe, from the aborted
    single-probe run. The loaded four-probe star measured 799-832 ms per probe and
    3198-3281 ms per cycle. Corrected; the 790 ms figure stays in history, which is
    where it belongs.
    - The bulk-read trap gains its pointer to history 1.13, where the diagnosis is.
    - README led with the 2026-09-09 BLE result. The headline is now the enrollment
    and the star, and what the logger has still never done is run on a moving car -
    which is the first thing a fresh session should read.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
2026-09-10 The bulk read converts nothing with the permission fixed; conversionMs was hiding it
    Measured with four real probes: 331 cycles at 3190-3309 ms, every probe still
    ~800 ms, against 3198-3281 ms before the udev rule. The write to
    therm_bulk_read is accepted and nothing converts. The permission was necessary
    and not sufficient.
    Found because 0x603's conversion-time field read 0 on the phone and the owner
    asked about it. The cause was here:
    lastConversionMs = bulkWaitMs.has_value() ? *bulkWaitMs : slowestReadMs;
    bulkWaitMs had a value whenever the WRITE succeeded, so the moment the udev rule
    landed a 0 ms bulk wait began masking ~800 ms of real conversion. The fix that
    made the write succee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
    [dataContracts.hpp]
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2026-09-10 README: 0x600/0x601 do not carry over from the ESP32 rig
    The channel-section preamble still said packet IDs 0x600-0x603 were inherited
    from the rig "so channel definitions written against it carry over" - three
    lines above the new 0x600 section saying the opposite. Rev 81 released those
    two IDs and the preamble was not reconciled: the same distant-contradiction
    failure the sync pass exists to catch, in the one paragraph a reader consults
    before typing definitions into the phone.
    0x602 and 0x603 do still carry over, and that is now stated separately.
2026-09-10 Sync pass: §10 step 5 is done, and item 44's requirement lands where it executes
    Two findings from the wrap-up sync pass.
    §10 step 5 still read "PARTLY DONE, 2026-09-09" describing a scan that found
    only 0x77 — written before the ~RESET resolder and before the BME280 was read
    at all. Both devices answer and the part is read end to end, so the step is
    done.
    The more useful one: open item 44 states that §10's bring-up steps must not
    read a single failed transfer as an absent part, and that requirement had been
    written into §2 note 3 and into the plan but never into §10 — the step that
    would actually execute it. A requirement filed only in the audit trail is a
    requirement nothing wil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
2026-09-10 KnurDash carries the same fix now, and one box broke the other
    The reject-on-unknown-packet-ID fault was fixed in KnurDash too. Recorded here
    for what it revealed rather than because this repository owns it.
    Box 1 was already suffering from it, and the cause was a change to box 2.
    RaceChrono keeps one channel set and asks every DIY device for all of it, so
    defining 0x600 and 0x601 for this logger started getting KnurDash asked for two
    IDs it does not publish - and refusing the first cost it every subscription
    behind it. The captured burst predicts 0x7F0 and 0x420 live with 0x202, 0x78 and
    0x4FA frozen, and the owner confirmed exactly that from the car.
    Neither box's symptom was traceable t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
2026-09-11 Point at the new thermal and pressure companions, and correct a superseded Cp
    The plan's Step 0b split its rig, method and results into two companion files in
    the sibling ndLouvers repository. Repoint the BME280 reasoning at
    ../ndLouvers/thermals-testing.md §1.4 and add both companions to the reading
    order, with the caveat that the pressure one describes nothing that exists yet.
    Also corrects a figure that had gone stale here after the first drive: the cavity
    pressure offset was carried as "at Cp -1, ~464 Pa, five to ten times the signal",
    which was the pre-drive estimate. Measured: 156 Pa below stationary at a mean
    116 km/h, Cp about -0.25, and not a single constant Cp across the speed ba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
2026-09-11 The subscription fix holds on a phone, and the next three faults are on the phone
    Second road test, 2026-09-11. Box 2 accepted the whole burst and ignored the five IDs
    it does not publish; 141/141/139/139 notifications over 140 s with zero drops on either
    per-cycle counter. KnurDash's fix is confirmed for the first time - it kept all twelve
    of its channels alive to the last sample. The I2C retry behaved as characterised on the
    bench: 550 first-attempt failures, 550 recovered, 0 exhausted.
    New section: the phone's channel list is part of the instrument and this code cannot
    check it. One 0x602 channel is bytesToUint where bytesToInt belongs, which is invisible
    above 0 C; 0x604 and 0x601 bytes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
2026-09-11 Back up the RaceChrono vehicle profile, and correct 0x600's pressure equation
    The phone's channel definitions existed only on the phone. RaceChrono's exported
    vehicle profile is now committed at RaceChrono/vehicleProfile.json, pretty-printed and
    diffable, covering both boxes since the two share one channel set. localUuid is
    stripped: it is a 64-hex identifier tied to the owner's install, not a channel
    definition, and this repository is public. Nothing else in the file is host-specific -
    no MAC, no location, no credential.
    Checking it against this README found one drift: 0x600's pressure channel is entered as
    bytesToUint(raw,0,4)/1000, so the gauge reads kPa, while the table here documented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
2026-09-11 Two owner corrections: the pressure gauge reads bar, and box 1's empty channels are fine
    The /1000 on 0x600's pressure channel is not "so the gauge reads kPa" - RaceChrono's
    Pressure channel takes kPa and that gauge displays bar, so 101319 Pa is stored as
    101.319 and renders as ~1.013 bar. The invalid marker survives as ~42950 bar.
    Box 1's two all-NaN channels are deliberate, not broken. RaceChrono renders an
    out-of-calibration-range marker as no value at all, and those sensors were out of range
    throughout; lowPass(E,254) and lowPass(F,254) are working as designed. The frame-length
    diagnosis committed in 7a853b3 was wrong - it fitted every observation and was still
    missing the one fact only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
2026-09-11 Doc sync: the bulk read works, and the standing diagnosis was wrong
    Reconciles both repositories' claims about the 1-Wire sample rate against
    what was measured at the car on 2026-09-11. Six files here; ndLouvers is
    committed separately.
    CLAUDE.md's therm_bulk_read block said the bulk path had never once worked and
    named parasite power as the first suspect. It now states the two conditions
    that are each necessary and neither sufficient - the udev rule and an
    eight-byte trigger - and records the four properties that cost something to
    learn: 0/1/-1 are three different answers, the steady-state readback is 1 and
    not -1, the conversion must be timed from before the write, and
    probeCapabilities.b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
2026-09-11 Doc sync: the third road test, from inside the cavity
    The box was in the wheel-well cavity with the enclosure closed (owner) — the
    first session in the position it was built for. 415 s with box 1 connected at
    the same time, and all three free-running counters stepping exactly +1 on every
    sample: zero dropped notifications from the cavity, three times the second
    drive's window. Probes 4 and valid-mask 15 on all 406 thermal samples, zero read
    errors, bulk conversion 762-792 ms, 0.977 Hz measured off the phone's own
    timestamps — matching the SD figure from history 1.15 exactly. Throttle live and
    sticky and the undervoltage comparator all 0.
    The phone's channel list is finally verified end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
2026-09-15 Split the 1-Wire path into its own document, and sync the set
    CLAUDE.md had reached 803 lines with a third of them on one subsystem, and
    `therm_bulk_read` was sub-item 5 of a bullet, four levels deep, running 66
    lines. one-wire-probes.md now owns that subsystem -- ROM-ID bindings, the
    `w1-gpio` pullup trap, the `28-*` family filter, `therm_bulk_read`, the ~100 s
    tail a pulled probe leaves, the fake-sysfs harness, and the enrollment and
    calibration-offset requirements -- with those four as top-level sections
    instead of nested list items. Same contract as its parent: traps and standing
    requirements, not procedures. README.md still says how to run each one.
    Referenced from README's read-order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
2026-09-15 The track day, a fragment-blind audit tool, and a CAN byte nobody defined
    Analysis of the 2026-09-13 Poznan track day (two sessions in one .rcz).
    The logger came through its first real load case: 41 min, 4733 thermal
    cycles, two single-cycle CRC failures each flagged three ways, zero
    dropped notifications on all three counters in both sessions, and no
    restart across the 83-minute pit break.
    - Tools/rcz-channels.py read only the archive root, so a session that was
    paused and resumed reported its first stretch and silently discarded
    the rest - half of this track day. Fragments are now enumerated and
    reported separately; they are not merged, because a channel edited
    between stretches l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
2026-09-16 The second track day: a 21.7-hour continuous run, and a zero that misleads
    Six fragments from the 2026-09-14 wet-to-dry day at Poznan. Zero dropped
    notifications on all three counters in all six, zero invalid thermal
    samples in 5385 cycles.
    - The logger ran continuously across BOTH track days and was never
    power-cycled: 78182 s apart, and the BME280 cycle counter lands 29
    cycles (0.04 %) from prediction. Longest unattended run by far, with
    the fuse left in overnight. It also means the sticky undervoltage latch
    predates a two-day run, so item 48's search window is older.
    - A ZERO READ-ERROR COUNT IS NOT PROOF EVERY SAMPLE WAS VALID. One cycle
    sent all three 0x600 values as sentinel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
2026-09-21 calibrationBell: the wall is 0.891 mm, and the caliper was read in the wrong place
    A ballasted run against printed graduations (../ndLouvers/pressure-testing.md
    §3.5) inverts to A_wall = 422 mm², a 0.891 mm wall — calibrationBell.stl's
    0.90 to within 1 %. The caliper reading of 1.00 mm had been taken at the rim,
    which is the first layer of a part printed rim-down and is squished wider than
    the rest; this file's own print notes call that edge the sealing face.
    k_d moves from 0.2627 to 0.2337 rod-less / 0.2372 with the rod, and every
    constant derived from it moves with it. The earlier regression figure of
    0.2615 ± 0.013, from eyeballed depths on an unballasted bell, is withdrawn as
    3 sig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
    [KnurLogger.3mf, calibrationBell.3mf, pipeStand1.stl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]
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2026-09-23 Bell: A_eff measured with water; the SDP810's barometric dependency
    The ladder of 2026-09-22/23 settled the fixture and overturned its constants.
    A_eff is now MEASURED, not computed from the ID: a datum-free two-fill
    difference (1215 g of water between the 30 mm and 100 mm marks), corroborated
    to 0.08 % by a 50 mm single fill, gives 17 392 mm2 - 1.6 % below pi/4*150^2,
    the bore being mildly oval (~150.0 x 147.6). So k_m = 0.5639, not 0.5551.
    k_d = 0.2372 is withdrawn as a measurement: it was the slope of READING against
    depth, so it carried the reading sensor's span and the barometric term below.
    The 0.891 mm wall was inverted from it, which made the pair circular. Geometry
    on the measured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
    [calibrationBell.3mf, calibrationBellPan1.stl, calibrationBellPan2.stl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]
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2026-09-23 Docs: review sync — bell-marks on current constants, SystemSetup paths, hard-soldered sensors
    Tools/bell-marks.py moved off the withdrawn constants (k_m 0.5551, k_d 0.2372,
    no barometric term) onto k_m 0.5639 / k_d 0.2414 with P_abs read from the
    session, the 60 s fit at each mark and per-charge flow. The build sheet's
    Hardware/ -> SystemSetup/ move is carried into every link, including a runtime
    error string. All five SDP810s restated as hard-soldered with no headers. A
    build that adds a required ini key is recorded as crash-looping the production
    logger. Rev 105 retirements, item 1c/1d, the bimodal idle-bus refusal and the
    pressure sentinel value reconciled across docs, comments and role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
    [dataContracts.hpp]
2026-09-23 0x607 bytes 6/7 fixed, powerOnDefault docs, code stops citing documents
    - 0x607 byte 7 is now the mux control byte (0 idle, bit n while P<n> is read,
    0xFF after a failed deselect), set before each select; the BLE worker
    publishes it when a cycle stalls past 1 s, since a stuck cycle publishes
    nothing itself. Byte 6 is the lowest enabled channel's temperature, -128
    when it has no valid reading (it was the first valid channel, 0 when none).
    Session field muxSelected -> muxControl.
    - Owner's change: the powerOnDefault check is removed; 85.00 C is a reading.
    one-wire-probes.md, CLAUDE.md and README updated to match.
    - pressureBaseline drops roleMappingNote and note; plan/section/doc r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
    [dataContracts.hpp]
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2026-09-24 Pressure correction: line-resistance input done; bell workbook update
    The correction handoff now points at the measured line-resistance
    parameters in ndLouvers pressure-testing.md §3.3a. calibrationBell.md
    notes plan open item 57 as closed. bellTesting.xlsx carries the
    2026-09-24 line-resistance marks.
    [bellTesting.xlsx]
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2026-09-24 Pressure correction steps 1-3: config keys, held BME280 pressure, the correction
    - [pressure] gains tubingResistancePerMetre, lineFixedResistance and six
    per-slot keys (span pair, line lengths, bypass fit), required for every
    enabled channel; the template carries the bench values, line lengths 0.
    - Bme280Data holds the last valid absolute pressure in two atomics;
    getHeldAbsolutePressure() returns it with its age.
    - correctPressure() divides by P_abs/96600 Pa and (1 + span), solves the
    bypass flow and adds back the line loss. pressureDeciPa on the air is the
    corrected value; the raw pressurePa is unchanged. A held pressure older
    than 10 s, or none yet, sends INT16_MIN with a reaso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
    [dataContracts.hpp]
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
